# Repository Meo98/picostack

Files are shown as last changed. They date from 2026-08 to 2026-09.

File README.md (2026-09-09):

<p align="center">
  PicoStack
</p>

<h1 align="center">PicoStack</h1>

<p align="center">
  <b>A stackable, contract-driven module system for the Raspberry Pi Pico.</b><br>
  Open hardware, generated by code, verified by tests that are proven to fail.
</p>

<p align="center">
  
  
  
  
</p>

<p align="center">
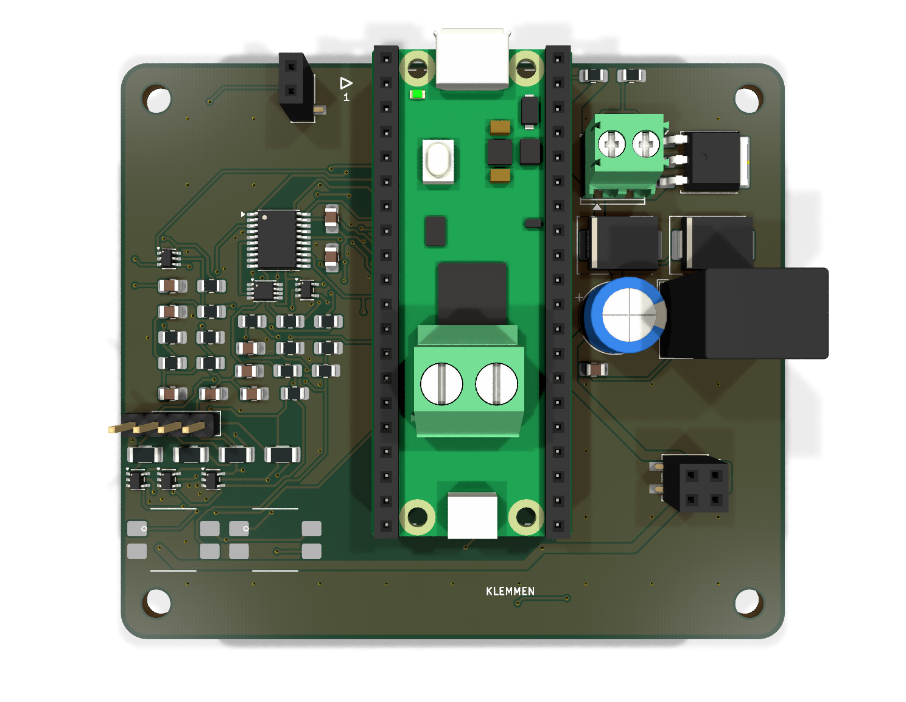
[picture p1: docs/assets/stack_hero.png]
PicoStack motor module with a Raspberry Pi Pico plugged directly into its own stacking headers
  
</p>

---

**One board plus a Pico is a working device.** PicoStack v2 abolishes the
separate base board that v1 needed: every 75 × 65 mm module now carries its
own 6–30 V supply (reverse-polarity protection, TVS, a K7805-1000R3
regulator, Schottky-OR into VSYS) and a pair of Pico-native 1×20 socket rows
(17.78 mm apart, the Pico's own pinout) — the Pico plugs straight into the
top of the stack and all 40 pins run down through it. Stack several fed
boards and they coexist; one is enough to power the whole chain. Every
module also breaks out its 18 spare Pico GPIOs plus 3V3/GND as labelled
solder pads on the board edge.

Power, I²C, emergency-stop and flashing signals run through the stack on
the same contract pinout v1 defined — v2 changed the connector geometry,
not a single pin's role — and any module can be flashed **through the
stack**, selected by a hardware token chain, without touching a cable.

The unusual part: **these boards are not drawn, they are built.** Schematics,
placement, routing, ground stitching and the manufacturing checks all come
from Python that runs headless against KiCad. The stack's mechanical and
electrical rules live in a single machine-readable file — the *contract*
(see the [design spec](docs/superpowers/specs/2026-09-07-picostack-v2-design.md)
for the full v2 rationale) — and every board is measured against it before
it may exist.

## Why you might care

- **You want motorized / sensor / whatever hats for the Pico** that stack
  instead of sprawling across a desk. Design one module and it composes
  with all the others.
- **You want to see a fully generative KiCad workflow** — schematic
  generators, placement specs, headless autorouting (freerouting 2.3),
  copper-pour healing, DRC gates — all reproducible from the command line.
- **You like tests that can actually fail.** Every check in this repository
  ships with a proof that it turns red when the thing it guards is broken.
  ERC and DRC caught *none* of the 14+ real bugs found during development —
  including a fail-unsafe emergency-stop gate (an intact loop blocked the
  motor, a broken wire released it) and a reverse-polarity FET wired so
  that reverse voltage crowbarred instead of being blocked. The custom
  gates caught all of them; that story is documented in the code.

## The stack at a glance

| Piece | What it is | State |
|---|---|---|
| **Contract** (`tools/stack_spec.py`) | Connector positions, pin roles, per-module supply rules, edge-pad positions, landing-point copper rules, mating rules — the single source of truth for anyone building a module | stable, v2 |
| **Motor module** (`hardware/kicad/motor/`) | DRV8876 H-bridge, STM32C011 co-processor, opto-isolated dual-channel e-stop loop, own 6–30 V supply cell | 75 × 65 mm, routed, DRC-clean |
| **Dimmer family** (`hardware/kicad/dimmer{1,3,4}/`) | 1/3/4-channel low-side LED dimmers from one parametric description, own supply cell each | 75 × 65 mm, routed, DRC-clean |
| **Base board** (`hardware/kicad/sockel/`) | v1's Pico socket + 24 V input + 5 V rail board | **v1-only, archived** — see [release v0.1.0](https://github.com/Meo98/picostack/releases/tag/v0.1.0); not part of v2, not updated to the v2 contract |
| **Toolchain** (`tools/`) | Schematic generators, board builder, autorouter driver, ground healer, contract probes | working, evolving |

<p align="center">
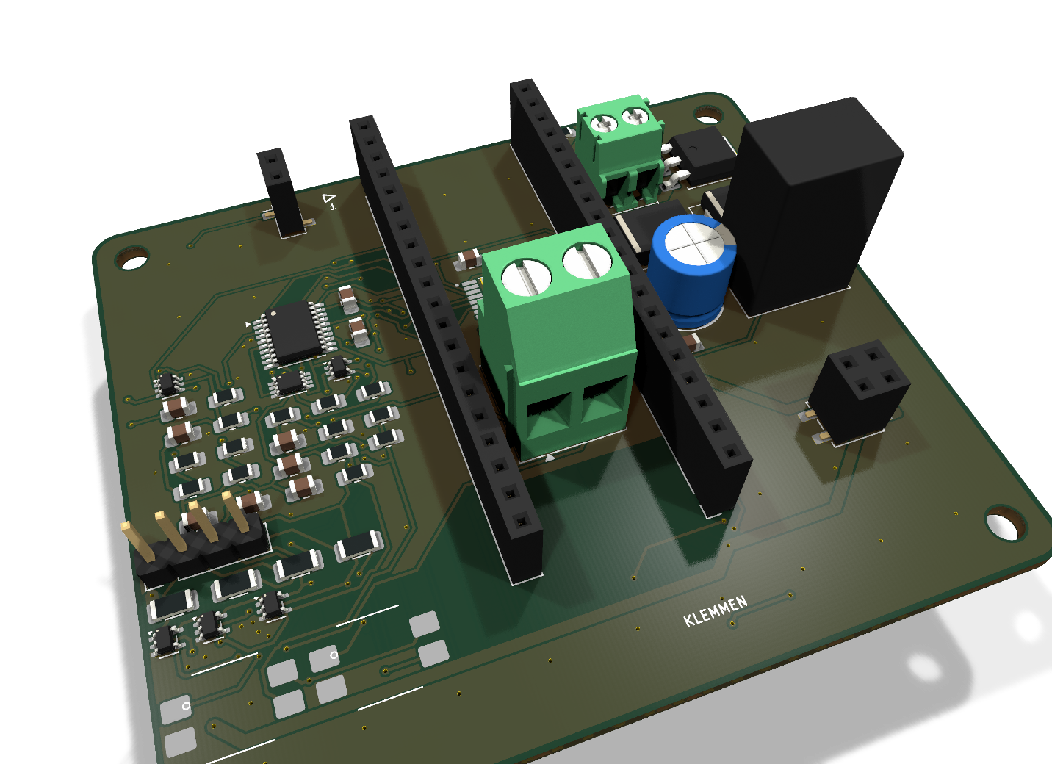
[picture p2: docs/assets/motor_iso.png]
Motor module, isometric
  
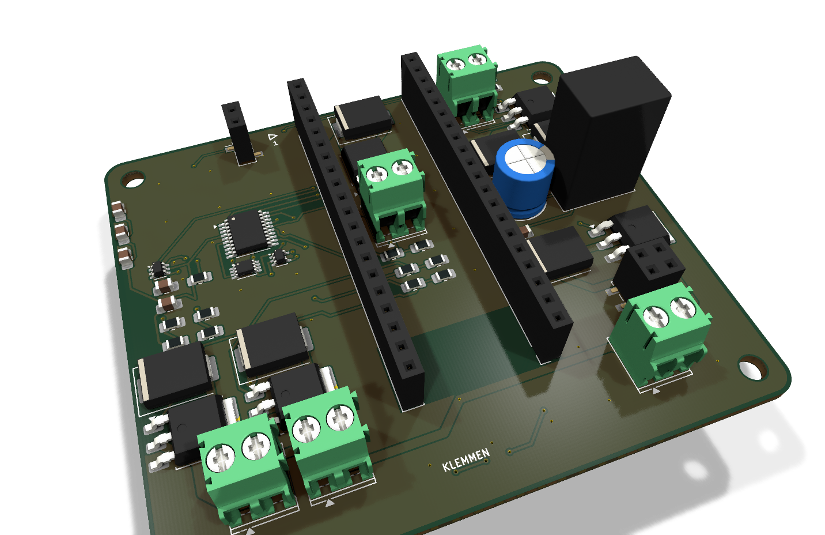
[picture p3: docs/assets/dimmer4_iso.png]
Four-channel LED dimmer module, isometric
  
</p>
<p align="center">
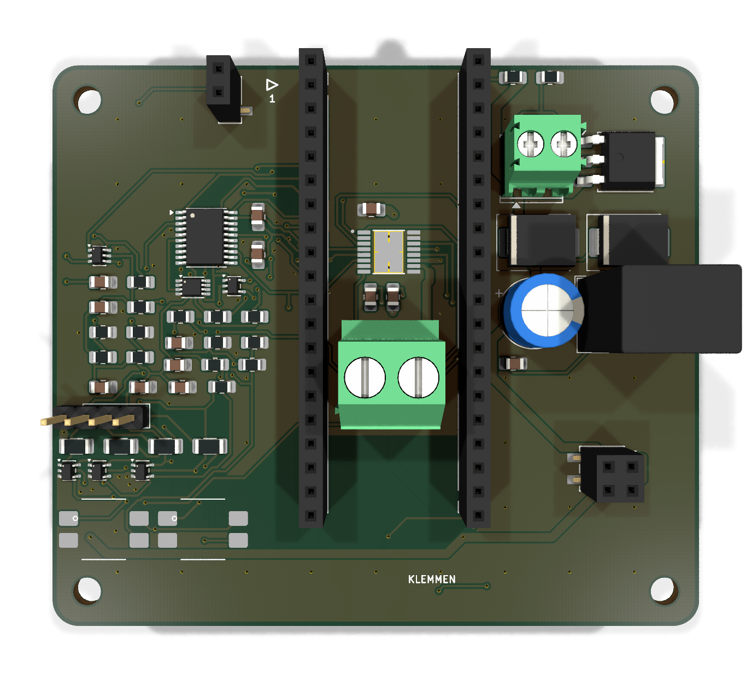
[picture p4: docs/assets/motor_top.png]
Motor module, top view
  
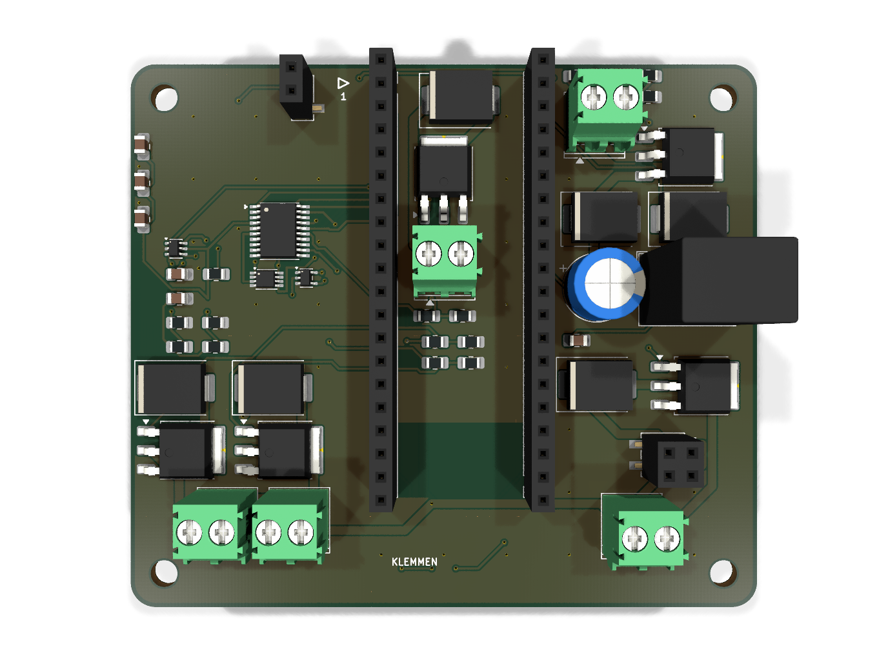
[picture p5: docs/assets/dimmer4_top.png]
Four-channel LED dimmer module, top view
  
</p>

## How a board gets built

```text
tools/sch/<board>.py      →  KiCad schematic (generated, ERC-clean)
tools/pcb/spec_<board>.py →  placement + pre-routes + stitching, no KiCad needed
tools/pcb/build.py        →  fresh .kicad_pcb from netlist + spec
tools/pcb/autoroute.py    →  freerouting 2.3 headless, DSN repaired on the fly
tools/pcb/masseheiler.py  →  finds isolated copper islands, heals them with vias
tools/pcb/steckerprobe.py →  measures the finished board against the contract
```

Every stage is a plain Python file you can read, run and extend. The
[website](https://meo98.github.io/picostack/) walks through the architecture in
detail.

## Building a module of your own

The contract is deliberately small. A module must:

1. use the 75 × 65 mm outline and M3 hole pattern from `stack_spec.py`,
2. place the two Pico-native socket rows and the two connector pairs at the
   contract positions (the helpers compute them for you — never type the
   coordinates),
3. give the board its own 6–30 V supply cell (reverse-polarity protection,
   TVS, Schottky-OR into VSYS) and bring every unused Pico GPIO out as a
   labelled edge pad,
4. keep the landing-point areas free of exposed copper, so a stack that is
   assembled rotated cannot short anything,
5. pass `tests/` and the contract probes against the built board.

Start by copying `tools/pcb/spec_motor.py` and
`tools/sch/motormodul.py`, then read
[CONTRIBUTING.md](CONTRIBUTING.md) — it describes the workflow, the
red-proof testing rule, and how to propose a new module.

**Module ideas we would love to see:** sensor hats, LED drivers, stepper
drivers, CAN/RS-485 bridges, audio, battery management — anything that
speaks the contract. Firmware in any language that runs on a Pico or the
module MCUs (C, MicroPython, Rust, …) is equally welcome.

## Repository layout

```text
hardware/kicad/     KiCad projects (generated .kicad_sch + built .kicad_pcb)
tools/stack_spec.py the contract
tools/sch/          schematic generators
tools/pcb/          board builder, router driver, probes, healer
tests/              plain-python test suites (no pytest needed)
docs/               project website (GitHub Pages)
```

## Building the boards yourself

You need KiCad 10, Python 3, and Java ≥ 25 for the bundled
freerouting 2.3 flow. Then:

```bash
python3 tests/run_all.py                 # every suite, no board tools needed
python3 tools/sch/motormodul.py          # regenerate a schematic
tools/pcb/kipy tools/pcb/build.py spec_motor \
  hardware/kicad/motor/Motormodul.kicad_pcb \
  hardware/kicad/motor/Motormodul.kicad_sch   # rebuild a board
```

(`kipy` is a small launcher that runs a script inside KiCad's Python.
See CONTRIBUTING for the full toolchain walkthrough.)

## Getting boards made

Gerbers, JLC-format BOM/CPL and pick-and-place files for all four v2 boards
live under `hardware/fertigung/{motor,dimmer1,dimmer3,dimmer4}/`, and ship as
ZIPs with every [release](https://github.com/Meo98/picostack/releases).
[`hardware/fertigung/ORDERING.md`](hardware/fertigung/ORDERING.md) walks
through ordering an assembled board at JLCPCB, including the traps that
already cost real money in v1 (a diode package mix-up, a rotation-preview
miss, a type-code encoding gotcha).

## License

- **Hardware** (everything under `hardware/`): [CERN-OHL-S-2.0](hardware/LICENSE) —
  strongly reciprocal: if you ship a derived board, you publish your changes.
- **Code** (tools, generators, firmware): [GPL-3.0-or-later](LICENSE).
- **Documentation**: CC-BY-SA 4.0.

## Project language

The public face of this project is English. The code comments are currently
German — they carry the full engineering rationale of every decision and are
being translated over time. New contributions should be in English.

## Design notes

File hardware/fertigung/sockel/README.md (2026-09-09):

# Sockelplatine — v1-only, archived

This fabrication data is **frozen at the v1 state**, kept for archive
purposes alongside [release v0.1.0](https://github.com/Meo98/picostack/releases/tag/v0.1.0).
It is **not part of the v2 product line** and was not regenerated for the
v2 contract (`VERTRAG_VERSION = 2` in `tools/stack_spec.py`).

v2 removed the need for this board entirely: every v2 module now carries
its own supply cell (reverse-polarity protection, TVS, K7805-1000R3,
Schottky-OR into VSYS) and a pair of Pico-native 1×20 socket rows, so one
module plus a Pico is a working device without a separate base board. See
[`hardware/fertigung/ORDERING.md`](../ORDERING.md) for the current v2
board family (motor, dimmer1, dimmer3, dimmer4) and
[`tools/sch/sockelplatine.py`](../../../tools/sch/sockelplatine.py) for
why this board's generator is not kept in sync with the v2 contract.

Do not order this as a v2 deliverable.

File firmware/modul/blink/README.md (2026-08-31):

# Modul-Testprogramm: blink

Das kleinstmögliche Programm für den Modul-MCU (STM32C011F6P6), dessen
Wirkung man von aussen sieht: ein GPIO-Pin im Sekundentakt umschalten.
Zweck ist einzig, `firmware/sockel/nachweis.py` etwas zum Aufspielen zu
geben, dessen Erfolg oder Misserfolg man ohne Messgerät erkennt — eine
LED oder ein Multimeter am Pin genügt.

Es gibt hier absichtlich **keinen Quelltext**. Register, Header und
Startup-Code hängen am gewählten MCU-Typ (STM32C011F6P6, siehe
`hardware/bauteile.md`) und liegen im Beispielprojekt des Herstellers
(STM32CubeC0 / STM32CubeIDE-Projektvorlage für die STM32C0-Serie,
GPIO-Toggle-Beispiel). Von dort übernehmen, nicht neu schreiben:
STM32-Startup-Dateien und Register-Zugriffe von Grund auf
nachzubauen wäre Aufwand ohne Erkenntnisgewinn für diesen Nachweis.

## Was das Programm tun soll

- Einen freien GPIO-Pin (z. B. ein LED-taugliches Pin, nicht PA11/PA12
  — die trägt der Bootlader-UART — und nicht PA14/BOOT0) im
  Sekundentakt umschalten (toggle, ca. 1 Hz).
- Keine weitere Funktion. Kein UART, kein I²C, keine Interrupts, die
  nicht zum Blinken gehören — je kleiner, desto eindeutiger ist der
  Nachweis, dass genau *dieses* Programm lief.

## Ausgabeformat

Der ROM-Bootlader (AN3155) kennt keine ELF-Dateien und keine
Sektionsheader. Er nimmt rohe Bytes, die er ab `0x08000000`
(Flash-Anfang) in den Speicher schreibt — Adresse und Byte-Reihenfolge
allein entscheiden, keine Metadaten.

Übersetzung (mit dem `arm-none-eabi`-Toolchain aus dem
Hersteller-Beispielprojekt bzw. STM32CubeIDE/CMake):

```bash
# Projekt wie gewohnt uebersetzen -> blink.elf
arm-none-eabi-objcopy -O binary blink.elf blink.bin
ls -l blink.bin      # erwartet: wenige hundert Byte
```

`blink.bin` ist die Datei, die `nachweis.py::aufspielen(pfad)`
erwartet.

## Status

Noch nicht angelegt. Es fehlt der STM32C011 auf dem Tisch (siehe
`docs/nachweis-2026-08.md`) — ohne Hardware zum Gegenprüfen lohnt sich
kein Quelltext, den niemand testen kann. Sobald ein Chip vorliegt: aus
dem Hersteller-Beispiel ableiten, wie oben beschrieben übersetzen, mit
`nachweis.py` aufspielen.

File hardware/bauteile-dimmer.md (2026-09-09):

# Bauteil-Belege Dimmer-Module (1/3/4 Kanäle)

Die Dimmer übernehmen das MCU-Nest wörtlich vom Motormodul; deren
Nummern sind in `bauteile.md` / `bauteile-1b.md` belegt. Hier stehen
nur die Positionen, die es NUR auf den Dimmern gibt bzw. die für die
Bestückungs-Bestellung 2026-09-04 neu gesichtet wurden. Regel wie
immer: eine LCSC-Nummer steht nur hier, wenn die Produktseite selbst
geöffnet und gelesen wurde.

| Position | Bauteil | Gehäuse | LCSC | gesichtet | Beleg |
|---|---|---|---|---|---|
| Freilaufdiode D1–D4 | SS36**C** (MDD/Microdiode) | **SMC (DO-214AB)** | C16237 | ja | LCSC-Produktseite `lcsc.com/product-detail/C16237.html` (Rohdaten: „SMC(DO-214AB)", 60 V, 3 A, „700mV@3A", Lager 102 720). **Falle:** das MDD-Teil mit dem nackten Namen „SS36" (C16015) ist laut seiner Produktseite **SMA (DO-214AC)** — falsches Gehäuse für unsere Pads. Das onsemi-SS36 in SMC (C391251) existiert, hatte am Recherchetag aber nur 847 Stück Lager bei ~0,37 $ |
| Gate-Vorwiderstand RG1–RG4 | 0805W8F1000T5E (UNI-ROYAL), 100 Ω ±1 % | 0805 | C17408 | ja | LCSC-Produktseite `lcsc.com/product-detail/C17408.html` (Rohdaten: „100Ω", „±1%", „125mW", „150V", Lager 8 236 700). Gleiche geprüfte Baureihe wie der 10-kΩ-Beleg C17414 in `bauteile-1b.md` |
| Stütz-Elko C12 (auch C3 Sockel, C12 Motor) | GR227M035F12RR0VL4FP0 (Chengx) | radial D8×L12, RM 3,5 | C45078 | ja | LCSC-Produktseite `lcsc.com/product-detail/…C45078.html` (Rohdaten: „220µF ±20%", „35V", „8mm × 12mm", „Lead Pitch: 3.5mm", „3000hrs@105℃", Lager 123 720) |
| Schraubklemme J5–J8 | KF350-3.5-2P (Cixi Kefa) | THT, RM 3,5, 2P | C474892 | ja | LCSC-Produktseite `lcsc.com/product-detail/C474892.html` (Rohdaten: „3.5mm", „1x2P", „10A", „300V", „18–24 AWG", M2-Schraube, Lager 7 100). **Ehrlich vermerkt:** das ist ein Klon auf dem Raster des Phoenix-PT-1,5/2-3,5-H-Footprints, keine Maßzeichnungs-Gegenprüfung Pad für Pad — Sitz im JLC-Bestückungs-Preview kontrollieren. Der Phoenix-Originaltyp war bei LCSC nicht auffindbar |

## Nachtrag 2026-09-04: JLC-Matching-Runde 2 (Lagerprobleme)

JLCs Abgleich traf drei Widerstandszeilen auf lagerleere Teile (Qty 0)
und hatte vom Kanal-FET NCE6050KA nur noch 3 Stück; die LCSC-Seite
C96013 meldet „Out of Stock". Ersatz, jeweils Produktseite gesichtet:

| Position | Bauteil | LCSC | Beleg |
|---|---|---|---|
| Kanal-FET Q1–Q4 | **NCE6020AK** (NCE), TO-252-2L — **ersetzt den ausverkauften NCE6050KA** | C108639 | LCSC-Produktseite `lcsc.com/product-detail/C108639.html` (Rohdaten: „60V", „20A", „40mΩ@4.5V", „<35mΩ @ VGS = 10V", Gate-Schwelle „2.5V", Lager 6 010). Gleiches V_GS(th)-Limit wie der 6050KA → das 3,3-V-Ansteuerargument (Herleitung in `tools/sch/dimmermodul.py`) bleibt konservativ tragfähig: 40 mΩ × (3 A)² = 0,36 W je Kanal. **Ehrlich vermerkt:** die Espace-Felderfahrung gilt wörtlich nur für den 6050KA — am ersten Board Temperatur nachmessen |
| Kennwiderstand 1,5 kΩ (R100 Dimmer4) | 0805W8F1501T5E (UNI-ROYAL) | C4310 | LCSC-Produktseite `lcsc.com/product-detail/C4310.html` (Rohdaten: „1.5kΩ", „±1%", „125mW", Lager 376 800); JLC-**Basic** laut Basic-Parts-Liste |
| Kennwiderstand 680 Ω (R101, R100 Motor) | 0805W8F6800T5E (UNI-ROYAL) | C17798 | LCSC-Produktseite `lcsc.com/product-detail/…C17798.html` (Rohdaten: „680Ω", „±1%", „125mW", Lager 1 216 700); JLC-Basic |
| 100 kΩ (R102, RP1–RP4) | 0805W8F1003T5E (UNI-ROYAL) | C149504 | JLCPCB-Produktseite `jlcpcb.com/partdetail/160838-0805W8F1003T5E/C149504` (Bestückungsbibliothek); LCSC führt denselben Widerstand doppelt — C17407 („SMT-Geschäft vorbehalten", Lager 185 900 im Retail) meldete im JLC-Dialog trotzdem 35 shortfall, C149504 ist der bestückbare Eintrag. JLCs Auto-Match C5713386 hatte Lager 0 |
| 0-Ω-Brücke (R101 Motor, R100 Dimmer1) | 0805W8F0000T5E (UNI-ROYAL) | C17477 | LCSC-Produktseite `lcsc.com/product-detail/C17477.html` (Rohdaten: „0Ω Jumper", „125mW", Lager 6 207 600) |

## Nachtrag 2026-09-07: JLC-Basic-Festlegung der Kleinteile (Runde 3)

Die „Extended components fee" (3,07 $ je Nicht-Basic-BOM-Zeile) machte
sichtbar, welche Zeilen JLCs Beschreibungs-Matching dem Zufall
überließ. Sichtung per headless Chrome direkt aus dem Seiten-JSON der
JLC-Teileseiten (`componentLibraryType`, `overseasStockCount`,
`noBuyReason`), alle am 2026-09-07:

| Teil | LCSC | Befund |
|---|---|---|
| 100 nF 50 V X7R 0805 (C100 u. a.) | C49678 | YAGEO CC0805KRX7R9BB104, „base", Lager 20,6 Mio |
| 1 µF 50 V X7R 0805 (C101) | C28323 | Samsung CL21B105KBFNNNE, „base", Lager 3,9 Mio |
| 22 µF 25 V X5R 0805 (C2 Sockel) | C45783 | Samsung CL21A226MAQNNNE, „base", Lager 5,2 Mio |
| 4,7 kΩ 0805 (R1/R2 Sockel, R20/R21 Motor) | C17673 | 0805W8F4701T5E, „base", Lager 6,6 Mio |
| 100 kΩ — Bestätigung | C149504 | **„base", Lager 5,2 Mio** — der Karteileichen-Match C17407 ist „expand" UND `noBuyReason: "This product is no longer manufactured."` |
| 100 kΩ — verworfen | C2889441 | VO-Teil aus der Websuche: „expand", Lager 0, ebenfalls abgekündigt |

Ergebnis: Alle Widerstands- und Kondensator-Zeilen aller Boards sind
Basic (keine Gebühr, deterministisches Auto-Match). Die verbleibenden
8 Extended-Zeilen des Dimmer4 sind sämtlich Halbleiter ohne
Basic-Äquivalent — die ~24,56 $ Gebühr sind das Minimum für dieses
Design.

Die übrigen Dimmer-BOM-Nummern (STM32C011F6P6 C5456198, 74LVC-Gatter
C202238/C206109/C7832, IRFR5305 C2624, SMCJ30A C340696, 10 kΩ C17414)
sind in `bauteile.md` / `bauteile-1b.md` bzw. im LED-Dimmer-Altprojekt
belegt und in `tools/jlc.py` als Konstanten übernommen. Der dort
belegte NCE6050KA (C96013) bleibt als Referenz stehen, wird aber seit
dem Nachtrag oben nicht mehr bestückt.

## Nachtrag 2026-09-09: v2-Versorgungszelle (Task 9, Fertigungsdaten)

Mit v2 trägt **jedes** Modul (Motor, Dimmer1/3/4) die Versorgungszelle
aus `tools/sch/versorgung.py` (J90/Q90/R90/R91/D90/C90/U90/C91/D91,
löst den bisherigen board-eigenen Verpolschutz Q1/Q10/D1/D10/C12 ab —
per `pos.csv` nachgemessen, keiner dieser alten Bezeichner existiert
mehr). Für `tools/jlc.py` neu **zusammengesetzt**, aber **keine neue
LCSC-Sichtung** nötig — alle vier Nummern sind bereits an anderer
Stelle in diesem Projekt mit Produktseite belegt:

| Bauteil (Zelle) | LCSC | bereits belegt in |
|---|---|---|
| J90 KF350-3.5-2P | C474892 | `tools/jlc.py` (Bestellrunde 2026-09-04) |
| U90 K7805-1000R3 | C909765 | `tools/sch/sockelplatine.py` / `tools/jlc.py` (Sockel-U2) |
| D91 SS36C | C16237 | `tools/jlc.py` (Dimmer-Kanaldioden D1–D4) |
| C90 220µF Elko | C45078 | `tools/jlc.py` (Sockel-C3 / bisheriges C12) |

Q90 (IRFR5305, C2624), D90 (SMCJ30A, C340696), R90/R91 (10 kΩ,
C17414), C91 (22µF, C45783) sind ebenfalls reine Wiederverwendungen
bereits belegter Nummern (s. Konstanten in `tools/jlc.py`).

**Eine echte neue Sichtung diese Runde:** U6/U7 (Motormodul) wechseln
von SN74LVC1G06 (C7828, invertierend — für den Ruhestrom-Notaus falsch
gepolt, s. `tools/sch/motormodul.py::INVERTER_WERT`) auf **SN74LVC1G07
(C7830)**, nichtinvertierender Puffer mit Open-Drain-Ausgang,
pinidentisch (SOT-353/SC-70-5, gleicher Footprint wie U3/U103). Die
Quelle in `motormodul.py` leitet C7830 aus der LCSC-Nummernfolge der
Nachbartypen her (C7828 = 1G06, C7832 = 1G08) statt aus einer selbst
gesichteten Produktseite — das wäre nach der bindenden Regel dieses
Projekts eigentlich ein Lückenfall (Feld leer lassen). Für diese
Aufgabe **selbst nachgesehen** (WebFetch auf
`lcsc.com/product-detail/C7830.html`, 2026-09-09): Seite bestätigt
MPN **SN74LVC1G07DCKR**, Gehäuse **SC-70-5**, Beschreibung „Single
Buffer/Driver With Open-Drain Output", 1,65–5,5 V, 32 mA Senkstrom —
die Nummer ist korrekt, die Herleitung war nur unvollständig belegt.
`tools/jlc.py` führt C7830 jetzt als `LCSC_1G07`-Konstante.

Unbestückt und ohne LCSC-Bedarf: J95/J96 (Randpad-Reihen, SMD-Lötpads
auf B.Cu, `stack_spec.RANDPADS`) und J105 (zweiter Stapelstecker,
Pico-Pins 21–40 — vorher Teil eines einzelnen 2×20-Steckers J100,
jetzt zwei 1×20-Buchsen) — beide von Hand im gesteckten Verbund
bestückt, s. `hardware/fertigung/*/UNBESTUECKT.txt`.

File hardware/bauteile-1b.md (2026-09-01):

# Bauteilwahl Etappe 1b: Stapelstecker, Auswahlketten-Logik, Leistung, Klemmen

**Stand:** 2026-08-31. Bestand und Preise bei LCSC/JLCPCB ändern sich laufend;
die hier genannten Zahlen sind Stichproben vom Recherchezeitpunkt, keine
Garantie. Vorlage und Sorgfaltsmassstab: `hardware/bauteile.md` (Etappe 1a).

## Bauteiltabelle

**Nachtrag 2026-08-31 (Prüfung durch den Auftraggeber):** Der 2×20-Signalstecker
ist nach der Entscheidung des Auftraggebers **kein** Buchse/Stift-Paar mehr,
sondern ein echter Stapelstecker (Buchse mit durchgehendem Stift). Die
ursprünglichen zwei Zeilen dafür (Buchse C2977589 / Stift C50980) stehen unten
als **verworfen** markiert, ersetzt durch die neue Stapelstecker-Zeile.
Begründung und Rechnung: Beleg 1 (überarbeitet) und der neue Abschnitt
„Beleg 6 — Entscheidung Stapelstecker". Die beiden verworfenen Bauteile
bleiben sichtbar stehen, weil ihre Zahlen (6,0/3,0 mm bzw. 8,5 mm) jetzt die
Grundlage des neuen, eigenständigen Kettensteckers sind.

| Zweck | Typ | Bauform | LCSC | geprüft | Quelle |
|---|---|---|---|---|---|
| Signalstecker, Buchse (oben, 2×20) — **verworfen, s. u.** | BOOMELE/ZHOURI-Familie, 2,54 mm Buchsenleiste | THT, Gehäusehöhe 8,5 mm über Platine | C2977589 | verworfen (Bauform an sich geprüft) | LCSC-Produktseite `lcsc.com/product-detail/C2977589.html`; Datenblatt (ZHOURI, Rev. ZRLCGY2025-06-17-CJ A/1), Masszeichnung „8,5±0,2"; JLCPCB-Produktseite `jlcpcb.com/partdetail/2.54-2*20/C2977589` (SMT Assembly, Economic/Standard PCBA) |
| Signalstecker, Stift (unten, 2×20) — **verworfen, s. u.** | BOOMELE 2,54 mm Stiftleiste, gerade | THT, Stift 6,0 mm oberhalb / 3,0 mm unterhalb des Isolierkörpers (Gesamtlänge 9,0 mm) | C50980 | verworfen (Bauform an sich geprüft) | LCSC-Produktseite `lcsc.com/product-detail/Male-Header_Made-in-China-2-54mm-2-20P-Header_C50980.html`; Datenblatt (东莞康孚电子), Masszeichnung „3.0" / „6.0"; JLCPCB-Produktseite `jlcpcb.com/partdetail/BOOMELE-2_54mm2_20PHeader/C50980` (SMT Assembly, Economic/Standard PCBA) |
| **Stapelstecker, Signal (2×20) — ersetzt die beiden Zeilen oben** | ZHOURI/BOOMELE „PC104-2*NA+1": Buchse mit durchgehendem Stift | THT, Gehäuse 8,5 mm über Platine, Stift 12,46 mm unterhalb des Gehäuses (Gesamtlänge 23,50 mm), 3 A/Kontakt | C35165 | ja | LCSC-Produktseite `lcsc.com/product-detail/Pin-Header-Female-Header_Boom-Precision-Elec-2-54mm-2-20P_C35165.html`; Datenblatt (ZHOURI/上海康司玛, Zeichnung „PC104-2*NA+1"), Masszeichnung „8,5±0,2" / „12,46±0,2" / „23,50"; JLCPCB-Produktseite `jlcpcb.com/partdetail/BOOMELE-2_54_2_20PFemaleLongPC104/C35165` (SMT Assembly, Economic/Standard PCBA) |
| ~~Kettenstecker, Buchse (oben, 1×2, trägt SEL+GND)~~ — **verworfen 2026-08-31 (Aufgabe 5e): zwei bedrahtete Hälften können sich am selben Ort keine Bohrungen teilen, s. Beleg 13** | XFCN PM254V-11-02-H85 | THT, 8,5 mm über Platine, 3 A/Kontakt, 250 V | C541849 | verworfen (Bauform an sich geprüft) | LCSC-Produktseite `lcsc.com/product-detail/C541849.html` (Rohdaten: „3A", „250V", „8.5mm"); JLCPCB-Produktseite `jlcpcb.com/partdetail/XFCN-PM254V_1102H85/C541849` (SMT Assembly, Economic/Standard PCBA) — laut Herstellerbezeichnung passend zur XFCN-PZ254-Reihe |
| ~~Kettenstecker, Stift (unten, 1×2)~~ — **verworfen 2026-08-31 (Aufgabe 5e): zwei bedrahtete Hälften können sich am selben Ort keine Bohrungen teilen, s. Beleg 13** | XFCN PZ254V-11-02P | THT, Stift 6,0 mm oberhalb / 3,0 mm unterhalb des Isolierkörpers, 3 A/Kontakt, 250 V | C492401 | verworfen (Bauform an sich geprüft) | LCSC-Produktseite `lcsc.com/product-detail/Pin-Header-Female-Header_XFCN-PZ254V-11-02P_C492401.html` (Rohdaten: „6mm"/„3mm" Steck-/Lötpin); JLCPCB-Produktseite `jlcpcb.com/partdetail/XFCN-PZ254V_1102P/C492401` (SMT Assembly, Economic/Standard PCBA) |
| ~~Leistungsstecker, Buchse (oben, 2×2)~~ — **verworfen 2026-08-31 (Aufgabe 5e): zwei bedrahtete Hälften können sich am selben Ort keine Bohrungen teilen, s. Beleg 13** | gleiche ZHOURI-Familie, 2,54 mm | THT, 8,5 mm über Platine, 2,5 A/Kontakt | C2977590 | verworfen (Bauform an sich geprüft) | LCSC-Produktseite `lcsc.com/product-detail/Female-Headers_ZHOURI-2-54-2-2_C2977590.html` (Rohdaten: „2.5A", „8.5mm insulation height") |
| ~~Leistungsstecker, Stift (unten, 2×2)~~ — **verworfen 2026-08-31 (Aufgabe 5e): zwei bedrahtete Hälften können sich am selben Ort keine Bohrungen teilen, s. Beleg 13** | gleiche BOOMELE-Familie, 2,54 mm | THT, 6,0/3,0 mm, 3 A/Kontakt | C66690 | verworfen (Bauform an sich geprüft) | LCSC-Produktseite `lcsc.com/product-detail/Male-Header_Double-Rows2-2p-pitch2-54mm_C66690.html` (Rohdaten: „3A", „6mm"/„3mm") |
| **Kettenstecker, Buchse (oben, 1×2) — ersetzt die verworfene Zeile** | Buchsenleiste 1×2, 2,54 mm, SMD senkrecht, Isolationshöhe 8,5 mm, ≥ 1 A | **SMD**, 8,5 mm über Platine | *(offen — keine gesichtete Nummer)* | Bauform ja, Polzahl nein | Bauform belegt an C261072 (BOOMELE 2.54-2\*5P, „Surface mount, vertical", „Insulation Height: 8.5mm", „Current Rating: 2.5A") und C52611 (BOOMELE 2.54-2\*25P, „SMD header 2\*25P 2.54mm H=8.5mm Gold-plated"); in 1×2 auf **keiner** Produktseite gesehen — deshalb kein LCSC-Feld, s. Beleg 13.4 |
| **Kettenstecker, Stift (unten, 1×2) — ersetzt die verworfene Zeile** | Stiftleiste 1×2, 2,54 mm, SMD senkrecht, Isolierkörper ≤ 2,5 mm, Steckstift 6,0 mm | **SMD**, 8,5 mm unter der Platine (2,5 + 6,0) | *(offen — keine gesichtete Nummer)* | Bauform ja, Polzahl nein | Bauform belegt an C919361 (2×2), C192300 (2×4), C124390/C124391 (Ckmtw, 2×3/2×5); in 1×2 nicht gesehen, s. Beleg 13.4 |
| **Leistungsstecker, Buchse (oben, 2×2) — ersetzt die verworfene Zeile** | Buchsenleiste 2×2, 2,54 mm, SMD senkrecht, Isolationshöhe 8,5 mm, ≥ 2,5 A/Kontakt | **SMD**, 8,5 mm über Platine | *(offen — keine gesichtete Nummer)* | Bauform ja, Polzahl nein | wie die Zeile darüber: C261072 / C52611; in 2×2 nicht gesehen, s. Beleg 13.4 |
| **Leistungsstecker, Stift (unten, 2×2) — ersetzt die verworfene Zeile** | BOOMELE „2.54-2\*2P" | **SMD senkrecht**, Isolierkörper 2,5 mm, Steckstift 6,0 mm, 3 A/Kontakt | **C919361** | ja | LCSC-Produktseite `lcsc.com/product-detail/C919361.html` (Rohdaten: „Surface Mount (SMD), Vertical", „Insulation Height: 2.5mm", „Mating Pin Length: 6mm", „Current Rating: 3A", 28 460 auf Lager) |
| D-Flipflop, asynchroner Löscheingang | SN74LVC1G175DCKR (TI) | SOT-363-6 (SC-70-6), 6 Pins | C202238 | ja | LCSC-Produktseite `lcsc.com/product-detail/74-Series_TI_SN74LVC1G175DCKR_SN74LVC1G175DCKR_C202238.html`; JLCPCB-Produktseite `jlcpcb.com/partdetail/TexasInstruments-SN74LVC1G175DCKR/C202238` (SMT Assembly, Economic/Standard PCBA, MSL 1); Primärquelle TI-Datenblatt `SN74LVC1G175`, Dok. SCES560G (März 2004, revidiert Juni 2015), Abschnitt 3 „Description" und Abschnitt 5 „Pin Configuration and Functions" (Gehäuse „DCK Package, 6-Pin SC70", Pin 6 = `CLR`) |
| Gatter Dual-NAND (NOT via NAND(Q,Q), NRST) — **ersetzt die Zeilen NOT+NAND unten, s. Nachtrag 2026-08-31 (2. Runde)** | SN74LVC2G00DCUR (TI) | **VSSOP-8 (0,5 mm Pitch), 8 Pins — NICHT SOT-363**, s. Anmerkung unten | C206109 | ja | LCSC-Produktseite `lcsc.com/product-detail/C206109.html` (Rohdaten: Gehäuse „VSSOP-8-0.5mm"); TI-Datenblatt `SN74LVC2G00`, „Dual 2-Input Positive-NAND Gate" |
| ~~Gatter NOT (Invertierung Q)~~ — **verworfen, s. Nachtrag 2026-08-31 (2. Runde): ersetzt durch eine Einheit des Dual-NAND (Eingänge kurzgeschlossen)** | SN74LVC1G04DCKR (TI) | SOT-353 (SC-70-5), 5 Pins | C8207 | ja (Bauform an sich geprüft, aber verworfen) | LCSC-Produktseite `lcsc.com/product-detail/C8207.html`; JLCPCB-Produktseite `jlcpcb.com/partdetail/TexasInstruments-SN74LVC1G04DCKR/C8207` (SMT Assembly, Economic/Standard PCBA, MSL 1) |
| ~~Gatter NAND (NRST)~~ — **verworfen, s. Nachtrag 2026-08-31 (2. Runde): ersetzt durch die zweite Einheit desselben Dual-NAND** | SN74LVC1G00DCKR (TI) | SOT-353 (SC-70-5), 5 Pins | C8185 | ja (Bauform an sich geprüft, aber verworfen) | LCSC-Produktseite `lcsc.com/product-detail/C8185.html` (Rohdaten: „SOT-353“, „ultra-small DPW package… 0.8 mm × 0.8 mm“); TI-Datenblatt `SN74LVC1G00`, „Single 2-Input Positive-NAND Gate“ |
| Gatter AND (BOOT0) | SN74LVC1G08DCKR (TI) | SOT-353 (SC-70-5), 5 Pins | C7832 | ja | LCSC-Produktseite `lcsc.com/product-detail/C7832.html` (Rohdaten: „SC-70-5“, „ultra-small DPW package… 0.8 mm × 0.8 mm“); TI-Datenblatt `SN74LVC1G08`, „Single 2-Input Positive-AND Gate“ |
| ~~Gatter Dual-AND (RESET, BOOT0) — **verworfen, s. Nachtrag 2026-08-31**~~ | 74LVC2G08GT,115 (Nexperia) | XSON-8 (1×2 mm), 8 Pins | C548580 | ja (Bauform an sich geprüft, aber verworfen) | JLCPCB-Produktseite `jlcpcb.com/partdetail/Nexperia-74LVC2G08GT115/C548580` (SMT Assembly, Economic/Standard PCBA, MSL 1) |
| 5-V-Regler | K7805-2000R3 | SIP-3 | C2931187 | ja | bereits geprüft in Etappe 1a / LED-Dimmer-Projekt, siehe `hardware/bauteile.md` — hier unverändert übernommen, nicht neu recherchiert |
| Klemme 2-polig | DB128L-5.08-2P-GN-S | THT, 5,08 mm | C395868 | ja | bereits geprüft in Etappe 1a / LED-Dimmer-Projekt — unverändert übernommen |
| Klemme 3-polig — **seit Aufgabe 5f von keinem Modul mehr gebraucht** (sie trug die Sensorklemme J2 des Motormoduls; der Sensoreingang ist entfallen, s. Beleg 12, Nachtrag). Zeile bleibt stehen, weil die Nummer geprüft ist und ein künftiges Modul sie brauchen kann | DB128L-5.08-3P-GN-S | THT, 5,08 mm | C395869 | ja | LCSC-Produktseite `lcsc.com/product-detail/C395869.html` (16 A, 300 V, M2-Schraube, 12–22 AWG); JLCPCB-Produktseite bestätigt (DORABO-Familie, SMT/Wave-Assembly, Economic/Standard PCBA) — selbe Farbe/Baureihe wie die bereits geprüfte 2-polige Klemme |
| ~~Schaltdiode (Notaus-Verriegelung, Aufgabe 5)~~ — **verworfen, s. Nachtrag 2026-08-31 (Aufgabe-5-Fix-1): eine Si-Diode ist für den gezogenen Ruhepegel der NOTAUS-Sammelleitung zu hochohmig, s. Beleg 10** | 1N4148W (ST/Semtech) | SOD-123 | C81598 | ja (Bauform an sich geprüft, aber verworfen) | LCSC-Produktseite `lcsc.com/product-detail/Switching-Diode_ST-Semtech-1N4148W_C81598.html` (Rohdaten: Gehäuse „SOD-123", `Vf "1V@50mA"`); JLCPCB-Produktseite `jlcpcb.com/partdetail/ST-1N4148W/C81598` bestätigt SMT-Assembly („Economic and Standard" PCBA, MSL 3) |
| ~~Koppeldiode NOTAUS-Sammelleitung (D3/D4, Aufgabe-5-Fix-1)~~ — **verworfen, s. Nachtrag 2026-08-31 (Aufgabe 5d): der Notaus-Eingang arbeitet jetzt im Ruhestrom, der Bus wird von einem Open-Drain-Ausgang gezogen; eine Diode IN REIHE dazu liesse null Reserve gegen V_IL, s. Beleg 11. Die Grenzwerte bleiben stehen, weil die Gegenproben im Test mit ihnen rechnen** | BAT54W (YANGJIE), Schottky | SOD-123 (gleicher Footprint wie bisher) | C699107 | ja | LCSC-Produktseite `lcsc.com/product-detail/Schottky-Barrier-Diodes-SBD_Yangzhou-Yangjie-Elec-Tech-BAT54W_C699107.html` (Rohdaten: Hersteller „YANGJIE", Gehäuse „SOD-123", 30 V, 200 mA, Leckstrom „2µA@25V"; Bestand am Recherchetag 440 Stück — **wenig, vor der Bestellung prüfen**). Grenzwerte für die Pegelrechnung aus dem Vishay-Typdatenblatt `BAT54W`, Dok. **86408, Rev. 1.0 vom 20-Nov-2023**, Tabelle „ELECTRICAL CHARACTERISTICS" (T_amb = 25 °C): V_F ≤ 240 mV @ 0,1 mA, ≤ 320 mV @ 1 mA, ≤ 400 mV @ 10 mA, I_R ≤ 2 µA @ 25 V. **Ehrlich vermerkt:** das Yangjie-eigene PDF war über LCSC nicht als PDF abrufbar (die Datenblatt-URL liefert eine HTML-Seite); die zitierten Grenzwerte sind die des JEDEC-Typs BAT54W bei Vishay, nicht die von Yangjie selbst. Vor der Fertigung mit dem Yangjie-Datenblatt gegenprüfen |
| Verriegelungsgatter NOTAUS→nSLEEP (U3, Aufgabe-5-Fix-1) | SN74LVC1G08DCKR (TI) — **zweite Verwendung desselben Bauteils wie U103**, keine neue Nummer | SOT-353 (SC-70-5), 5 Pins | C7832 | ja | dieselbe geprüfte Produktseite wie die BOOT0-Zeile oben; Grenzwerte für die Pegelrechnung aus dem TI-Datenblatt `SN74LVC1G08`, Dok. **SCES217AA** (April 1999, revidiert August 2026), Abschnitt 5.3 „Recommended Operating Conditions" (V_IH ≥ 2,0 V, V_IL ≤ 0,8 V bei V_CC = 3–3,6 V) und Abschnitt 5.5 „Electrical Characteristics" (V_OH ≥ V_CC − 0,15 V bei −100 µA, V_OL ≤ 0,1 V bei 100 µA, I_I ≤ ±5 µA) |
| **Kanaltreiber Notaus→NOTAUS (U6/U7, Aufgabe 5d)** — Inverter mit **Open-Drain**-Ausgang; ersetzt die verworfenen Koppeldioden D3/D4 | SN74LVC1G06DCKR (TI) | SOT-353 (SC-70-5), 5 Pins — **gleicher Footprint wie U3/U103** | C7828 | ja | LCSC-Produktseite `lcsc.com/product-detail/Inverters_Texas-Instruments-SN74LVC1G06DCKR_C7828.html` (Rohdaten: Gehäuse „SC-70-5“, Versorgung „1.65V~5.5V“, Ausgangstyp „Open-drain“, Eingang „Schmitt trigger“, „Output sink current 32mA max“, Ruhestrom „10µA max“, Bestand 3 600). Primärquelle TI-Datenblatt `SN74LVC1G06`, Dok. **SCES295AB** (JUNE 2000 – REVISED OCTOBER 2025), selbst geöffnet und gelesen: Abschnitt 5.3 „Recommended Operating Conditions“ (V_IH ≥ 2,0 V, V_IL ≤ 0,8 V bei V_CC = 3–3,6 V; I_OL ≤ 24 mA bei V_CC = 3 V), Abschnitt 5.5 „Electrical Characteristics“ (V_OL ≤ 0,1 V bei 100 µA, **≤ 0,4 V bei 16 mA / V_CC = 3 V**, ≤ 0,55 V bei 24 mA; I_I ≤ ±1 µA; I_off ≤ ±10 µA; I_CC ≤ 10 µA), Abschnitt 1 „Features“ („Schmitt trigger action on all ports“, „Ioff supports partial-power-down mode and back-drive protection“), Abschnitt 3 „Description“ (Ausgänge dürfen für „active-low wired-OR“ zusammengeschaltet werden) |
| **Optokoppler Sensoreingang und Notaus-Schleifen (U2 sowie U4/U5, Aufgabe 5d)** — U2 war seit dem Altprojekt bestückt, stand aber **nie in dieser Tabelle**; hier nachgetragen | PC817X1CSP9F (SHARP), Rangmarke **A** | SMD-4P (SMT-Gullwing) | C97308 | ja | LCSC-Produktseite `lcsc.com/product-detail/Optocouplers_Sharp-Microelectronics-PC817X1CSP9F_C97308.html` (Rohdaten: Hersteller „SHARP“, Gehäuse „SMD-4P“, „Current Transfer Ratio 600%;50%“, „Forward Current (If) 50mA“, „Forward Voltage (Vf) 1.2V“, „VCE Saturation 200mV@20mA,1mA“, „Isolation Voltage 5kV“, Bestand 10 640). Primärquelle SHARP-Datenblatt „PC817X Series“, **Sheet No. D2-A03101EN, Date Sep. 30. 2003**, selbst gelesen: „Absolute Maximum Ratings“ (I_F 50 mA, I_C 50 mA, P_tot 200 mW, T_opr −30…+100 °C), „Electro-optical Characteristics“ (V_F TYP 1,2 V / MAX 1,4 V bei I_F = 20 mA; I_CEO MAX 100 nA; **I_C MIN 2,5 mA bei I_F = 5 mA, V_CE = 5 V** = CTR ≥ 50 %; V_CE(sat) MAX 0,2 V bei I_F = 20 mA, I_C = 1 mA; t_r/t_f TYP 4/3 µs, MAX 18 µs), „Model Line-up“ (Rangmarke A = I_C 4,0–8,0 mA bei I_F = 5 mA). **Footprint — ERLEDIGT (Aufgabe 5f):** die Gullwing-Bauform misst laut „Outline Dimensions“, Zeichnung 2 „SMT Gullwing Lead-Form“, 6,5 × 4,58 mm Körper bei **10,0 +0/−0,5 mm** Anschlussspanne und 7,62 mm Reihenabstand; der Platzhalter `Package_SO:SOP-4_3.8x4.1mm_P2.54mm` (Pads bis 3,48 mm vom Mittelpunkt) lag **vollständig neben** den Anschlüssen. Ersetzt durch einen projekteigenen Footprint, Pad für Pad aus „Design Considerations“ → „Recommended Foot Print (reference)“, Zeile „SMT Gullwing Lead-form“ (Reihenabstand **8,2 mm**, Pad **2,2 × 1,7 mm**, Raster 2,54 mm): `hardware/kicad/components/footprints/Optocoupler_PC817.pretty/PC817_SMT_Gullwing.kicad_mod`. U2 gibt es nicht mehr (Sensoreingang entfallen), U4/U5 tragen ihn. Details Beleg 12, Nachtrag |
| **Schleifenwiderstände Notaus (R16–R19, Aufgabe 5d)** — 1206 statt 0805, weil sie einen äusseren Dauerkurzschluss aushalten müssen | 1206W4F3301T5E (UNI-ROYAL), 3,3 kΩ ±1 % | 1206, Dickschicht | C26032 | ja | LCSC-Produktseite `lcsc.com/product-detail/Chip-Resistor-Surface-Mount_Uniroyal-Elec-1206W4F3301T5E_C26032.html` (Rohdaten: Gehäuse „1206“, „3.3kΩ“, Toleranz „±1%“, Leistung „**250mW**“, max. Arbeitsspannung „200V“, TK „±100ppm/℃“, Bestand 164 200). Die 250 mW sind der Beleg für die Kurzschlussrechnung in Beleg 11 |
| **Widerstände 0805, ganze Baureihe (Aufgabe 5f)** — die Belastbarkeit war bis dahin nirgends belegt, obwohl 20 Widerstände darauf beruhen | 0805W8F…T5E (UNI-ROYAL), Dickschicht, ±1 %; als Beleg geöffnet: 0805W8F1002T5E (10 kΩ) | 0805 | C17414 | ja | LCSC-Produktseite `lcsc.com/product-detail/Chip-Resistor-Surface-Mount_Uniroyal-Elec-0805W8F1002T5E_C17414.html` (Rohdaten: Gehäuse „0805“, „10kΩ“, Toleranz „±1%“, Leistung „**125mW**“, max. Arbeitsspannung „**150V**“, TK „±100ppm/℃“, Bestand 21 700 400). Diese 125 mW sind die Rechengrundlage der neuen Leistungsprüfung (`motormodul.P_NENN_JE_BAUFORM`) — s. Beleg 12, Nachtrag |
| **Verpolungsschutz Q1 (Aufgabe 5f)** — **ersetzt den geerbten „IRF4905“**, den es in TO-252 gar nicht gibt (s. Beleg 12, Nachtrag) | IRFR5305PbF (Infineon/International Rectifier), P-Kanal, −55 V, −31 A, 65 mΩ | **D-Pak (TO-252AA)** | C2624 | ja | LCSC-Produktseite `lcsc.com/product-detail/mosfets_infineon-technologies-irfr5305trpbf_C2624.html` (Rohdaten: „P-Channel MOSFET“, Gehäuse „**DPAK (TO-252AA)**“, „55V“, „31A“, „65mΩ @ 10V“, „110W“, Gate-Schwelle „4V“, Bestand 17 854, 0,23 $ ab 100 St.). Primärquelle Infineon/IR-Datenblatt **PD-95025A (12/13/04)**, selbst gelesen: Titelzeile „IRFR5305PbF … Surface Mount (IRFR5305) … V_DSS = −55V, R_DS(on) = 0.065 Ω, I_D = −31A“, „Absolute Maximum Ratings“ (V_GS ±20 V, P_D 110 W), „Electrical Characteristics“ (V_GS(th) −2,0…−4,0 V; I_GSS ±100 nA bei ±20 V), Abschnitt „D-Pak (TO-252AA) Package Outline“. **Gegenprobe zum alten Typ:** IRF4905 gibt es bei LCSC nur als TO-220 (C2564 Infineon, C18207551 UMW) und als TO-263/D2Pak (C5337969) |

Von den acht in der ersten Fassung neu recherchierten Nummern (nicht sieben, wie dort irrtümlich stand — Zählfehler korrigiert) sowie den drei in dieser Nachbesserung hinzugekommenen (Stapelstecker C35165, Kettenstecker C541849/C492401) wurde jede auf einer echten LCSC- oder
JLCPCB-Produktseite gesichtet (Datenblatt-Zeichnung oder strukturierte
Attribute), nicht aus dem Gedächtnis übernommen. Wo eine WebSearch-Kurzfassung
unterwegs Angaben behauptete, die dem tatsächlich gelesenen Datenblatt
widersprachen (siehe Beleg 2), wurde die Kurzfassung verworfen und nur das
gelesene PDF verwendet.

## Beleg 1 — Steckerhöhe gegen den 15-mm-Plattenabstand

**Aufgabe:** `STAPEL_ABSTAND = 15.0` (`tools/stack_spec.py`) ist der Abstand
**Platinenoberkante zu Platinenoberkante** zweier benachbarter Platinen (so
die Aufgabenstellung). Jedes Modul hat oben eine Buchsenleiste, unten eine
Stiftleiste, in der Platine verbunden. Zu prüfen: passt eine gängige
Bauform von Stift- und Buchsenleiste zusammen mit 1,6 mm Platinendicke auf
genau diesen Abstand.

**Geometrie.** Modul A (oben) trägt die Stiftleiste an seiner Unterseite,
Modul B (darunter) die Buchsenleiste an seiner Oberseite. Der freie
Luftspalt zwischen der Unterseite von A und der Oberseite von B ist

    G = STAPEL_ABSTAND − Platinendicke = 15,0 mm − 1,6 mm = 13,4 mm

Dieser Spalt wird nicht von den Steckern getragen — das leisten die
Abstandsbolzen (Design-Doc, Abschnitt „Mechanik": „Abstandsbolzen tragen
die Mechanik; die Stecker haben nur elektrische Aufgaben"). Für die
Steckverbindung heisst das: Stiftlänge unterhalb der Platine (M) plus
Buchsenhöhe oberhalb der Platine (F) müssen den Spalt **überbrücken**
(M + F ≥ G), und der Stift darf nicht so lang sein, dass sein Schulter
(Isolierkörper) am oberen Rand der Buchse anschlägt, bevor die Bolzen die
Platinen auf Abstand gebracht haben (M ≤ G).

**Belegte Werte (aus Beleg-Datenblättern oben):**

- Stiftleiste C50980: Stift ragt **6,0 mm** unterhalb des Isolierkörpers
  heraus (das ist die Seite, die als Steckseite nach unten zeigt, wenn das
  Bauteil mit dem Lötschwanz — 3,0 mm — durch die Platine nach oben lötet).
  → **M = 6,0 mm**
- Buchsenleiste C2977589: Gehäusehöhe **8,5 mm** über der Platine, auf der
  sie sitzt. → **F = 8,5 mm**

**Rechnung:**

    M + F = 6,0 mm + 8,5 mm = 14,5 mm
    G     = 13,4 mm
    Einstecktiefe = (M + F) − G = 14,5 mm − 13,4 mm = 1,1 mm

    M = 6,0 mm ≤ G = 13,4 mm → kein Anschlagen der Stiftschulter, grosser
    Puffer (7,4 mm) in diese Richtung.

**Befund:** Die Kombination **mattet gerade so**, mit rechnerisch **nur
1,1 mm Einstecktiefe**. Das ist kein „passt nicht", aber ein dünner Rand:

- Beide Bauteile tragen ±0,2 mm Toleranz auf den relevanten Massen
  (zusammen bis zu ±0,4 mm), dazu kommen die Toleranz der Platinendicke
  (JLCPCB-Standard: 1,6 mm ± 10 %, also ±0,16 mm) und die Fertigungslänge
  der Abstandsbolzen. Im ungünstigsten Fall reduziert sich die
  Einstecktiefe auf nahe null oder wird rechnerisch negativ — dann stecken
  die Kontakte nicht mehr sicher ineinander.
- Für 2,54-mm-Stiftkontakte wird in der Verbindungstechnik üblicherweise
  eine Mindest-Einstecktiefe von einigen mm für zuverlässigen Kontaktdruck
  und Selbstreinigung durch Wischen empfohlen; das ist allgemeines
  Auslegungswissen aus der Steckverbinder-Praxis, keine Angabe aus den
  hier gelesenen Datenblättern — beide Datenblätter machen dazu keine
  Aussage.
- Eine gründliche Suche nach einer **passenderen Standard-Buchse** (grösser
  als 8,5 mm, aber ohne durchgehenden Einzelstift wie beim PC104-Typ, der
  unten verworfen wird) oder einem **längeren Standard-Stift** (länger als
  6,0 mm mattend, bei derselben Lieferantenfamilie) blieb erfolglos: die
  generischen 2,54-mm-Serien auf LCSC bieten für Stiftleisten regelmässig
  nur die 6,0/3,0-mm-Kombination, für Buchsenleisten regelmässig maximal
  8,5 mm — jenseits davon wird es entweder ein Sonderpreis-Einzelfund oder
  ein Bauteil mit durchgehendem Stift (siehe unten).

**Verworfen: ZHOURI 2,54-2×20 PC104 (LCSC C35165).** Diese „Buchse" mit
12,3 mm Isolationshöhe (Datenblatt, Masszeichnung „8,5±0,2" Gehäuse plus
„12,46±0,2" / „23,50" lange durchgehende Stiftbeine) ist elektrisch ein
**Sockel-plus-langer-Stift in einem Bauteil** — genau die Bauform, die der
Vertrag ausdrücklich ausschliesst („ein echter Stapelstecker wäre hier
falsch: sein langer Stift bildet oben und unten denselben Kontakt").
Deshalb nicht als Ersatz verwendet, obwohl die Höhe besser passen würde.

**Ergebnis für Aufgabe 2, Schritt 2 — keine stillschweigende Ausweichung:**
Mit den zwei belegten Standard-Bauteilen (C50980 / C2977589) lässt sich der
Vertrag mit **15,0 mm** rechnerisch erfüllen, aber nur mit einer knappen,
toleranzgefährdeten Einstecktiefe von 1,1 mm. Drei Wege stehen offen, und
die Entscheidung darüber liegt beim Auftraggeber:

1. **So lassen** und die 1,1 mm als ausreichend akzeptieren — mit dem
   Risiko, dass ungünstige Toleranzstapel die Verbindung im Extremfall zu
   locker machen.
2. **`STAPEL_ABSTAND` verringern** (z. B. auf 14,0–14,3 mm), um mehr
   Einstecktiefe zu gewinnen — dann muss geprüft werden, ob die 10 mm
   hohen Schraubklemmen (Design-Doc, Abschnitt „Mechanik") noch passen;
   der ursprüngliche Grund für 15 mm war gerade deren Höhe plus Reserve.
3. **Sonderbauform suchen/bestellen lassen** (z. B. eine Buchse mit mehr
   als 8,5 mm bei einem anderen Hersteller/Distributor als LCSC) — hier
   nicht weiter verfolgt, weil ausserhalb des Bindungsrahmens „nur
   gesichtete LCSC/JLCPCB-Nummern".

### Nachtrag 2026-08-31 — Entscheidung des Auftraggebers: doch der Stapelstecker

Der Auftraggeber hat nach Prüfung dieses Befundes entschieden: **der
2×20-Signalstecker wird der oben verworfene PC104-Stapelstecker (LCSC
C35165)** — nicht mehr das Buchse/Stift-Paar C2977589/C50980. Begründung
und Grenzen dieser Entscheidung stehen ausführlich in Beleg 6 unten; hier
nur die nachgerechnete Geometrie, weil sie dieselbe Systematik wie oben
verwendet, nur mit einem anderen Bauteil.

**Geometrie beim durchgehenden Stift.** Anders als beim Buchse/Stift-Paar
sitzt hier auf **jedem** Modul dieselbe Buchse-mit-langem-Stift (C35165).
Der Stift von Modul A führt durch dessen eigene Platine (1,6 mm) hindurch
und ragt dann weiter nach unten in die Buchse von Modul B hinein:

    M = Stiftlänge unter dem Gehäuse − Platinendicke von A
      = 12,46 mm − 1,6 mm = 10,86 mm  (Nettoreichweite unter A's Unterseite)
    F = Gehäusehöhe der Buchse über B's Oberseite = 8,5 mm  (unverändert)

Dieselbe Bedingung wie oben (M ≤ G ≤ M + F, mit G = STAPEL_ABSTAND −
1,6 mm) ergibt jetzt:

    M + F = 10,86 mm + 8,5 mm = 19,36 mm
    G(15,0 mm) = 15,0 mm − 1,6 mm = 13,4 mm

    M = 10,86 mm ≤ 13,4 mm  → kein Anschlagen, 2,54 mm Puffer
    Einstecktiefe = 19,36 mm − 13,4 mm = 5,96 mm  → komfortabel

Umgestellt nach dem gültigen Bereich für `STAPEL_ABSTAND` (Bedingung
M ≤ G ≤ M+F, G = STAPEL_ABSTAND − 1,6 mm):

    STAPEL_ABSTAND_min = M + 1,6 mm  = 10,86 + 1,6  = 12,46 mm
    STAPEL_ABSTAND_max = M+F + 1,6 mm = 19,36 + 1,6 = 20,96 mm

**Ergebnis: 15,0 mm liegt komfortabel im gültigen Bereich [12,46 mm;
20,96 mm]**, mit 5,96 mm rechnerischer Einstecktiefe — deutlich mehr
Reserve als die 1,1 mm des ursprünglich geprüften Paars. Auch im
ungünstigsten Toleranzfall (±0,2 mm auf beiden Bauteilmassen, ±0,16 mm
Platinendicke) bleibt die Einstecktiefe über 5,5 mm; eine Nachrechnung mit
den etwas niedrigeren, automatisch aus dem LCSC-Attributfeld gelesenen
Werten (8,3 mm statt 8,5 mm, 12,3 mm statt 12,46 mm — kleine Abweichung
zur direkt aus der Datenblattzeichnung gelesenen Zahl, vermutlich Rundung
der automatischen Attributextraktion) ändert daran nichts Wesentliches
(M+F ≈ 19,0 mm, Einstecktiefe ≈ 5,6 mm bei 15,0 mm).

**`STAPEL_ABSTAND` muss also NICHT geändert werden.** Die Vermutung des
Auftraggebers, es könnte auf 12,6 mm sinken müssen, hat sich mit den
tatsächlich gelesenen Datenblattzahlen nicht bestätigt — 15,0 mm passt mit
gutem Spielraum. Umgesetzt in `tools/stack_spec.py` als Kommentar bei
`STAPEL_ABSTAND` und in den neuen Konstanten `STECKER_STAPEL`/
`STECKER_KETTE`.

**Unabhängige Bestätigung, nicht aus dem Datenblatt:** PC/104 ist ein
dokumentierter Industriestandard mit **fest definiertem** Platinenabstand
von 0,600 Zoll = 15,24 mm (Quelle: PC/104-Consortium, `pc104.org/hardware-
specifications/pc104/`; unabhängig bestätigt durch Samtec, die für exakt
diesen Standard passende Abstandsbolzen mit 15,24 mm Stapelhöhe führen).
Das hier gewählte Bauteil trägt den Namen „PC104-2\*NA+1“ und ist damit
mit hoher Wahrscheinlichkeit für genau diesen Industriewert ausgelegt —
15,24 mm liegt nur 0,24 mm über unserem Vertragswert 15,0 mm, tief im oben
berechneten gültigen Bereich. Das ist ein unabhängiger Plausibilitätscheck
von ausserhalb der Datenblattzeichnung, kein Ersatz für die eigene
Rechnung, aber eine Bestätigung, dass die eigene Dimensionsinterpretation
der Zeichnung (M und F wie oben zugeordnet) nicht offensichtlich falsch
ist.

> **Überholt seit 2026-08-31 (Aufgabe 5e), s. Beleg 13.** Die hier für den Kettenstecker gewählten bedrahteten Teile (C492401 / C541849) sind nicht baubar — zwei bedrahtete Hälften am selben Ort brauchten dieselben Bohrungen. Der Kettenstecker ist jetzt ein **SMD-Paar**, Einstecktiefe 5,60 statt 3,1 mm.

**Der Kettenstecker reproduziert den ursprünglichen Befund unverändert.**
Die eine Leitung, die weiterhin aufgetrennt werden muss (`SEL`), bekommt
zwangsläufig wieder ein normales Buchse/Stift-Paar (kein Durchgangsstift
möglich, sonst liesse sie sich nicht auftrennen — derselbe Grund, der den
2×20-Stecker ursprünglich zum Paar gemacht hatte). Die dafür gefundenen,
extra für die Zweipoligkeit gesichteten Bauteile XFCN PZ254V-11-02P
(C492401, Stift) und XFCN PM254V-11-02-H85 (C541849, Buchse) tragen
**exakt dieselben Masse** wie C50980/C2977589 (6,0/3,0 mm bzw. 8,5 mm,
beide Datenblätter/Attribute gesichtet) — die Rechnung von oben gilt
deshalb unverändert: **1,1 mm Einstecktiefe bei 15,0 mm, derselbe dünne
Rand wie ursprünglich gefunden.** Der Umstieg auf den Stapelstecker löst
das Höhenproblem nur für die 39 durchgereichten Leitungen, nicht für den
Kettenstecker. Das ist keine neue Erkenntnis, sondern derselbe Befund wie
oben, jetzt auf einen kleineren, eigenständigen Stecker konzentriert statt
über den ganzen 40-Pin-Stecker verteilt — hier explizit festgehalten, weil
das beim ersten Lesen der Aufgabenstellung leicht überlesen werden könnte:
„zur selben Bauhöhe passen" heisst nicht „dasselbe Höhenproblem gelöst".

## Beleg 2 — D-Flipflop mit asynchronem Löscheingang: gefunden

**Ergebnis: Ja, es gibt eines, JLCPCB-bestückbar.** `SN74LVC1G175DCKR`
(Texas Instruments), LCSC C202238, Gehäuse SOT-363-6 (6 Pins).

**Primärquelle, direkt gelesen:** TI-Datenblatt `SN74LVC1G175`, Dokument
SCES560G, „MARCH 2004 – REVISED JUNE 2015“ (heruntergeladen von
`ti.com/lit/ds/symlink/sn74lvc1g175.pdf`). Titel bereits im Dokumentkopf:
„SN74LVC1G175 Single D-Type Flip-Flop With Asynchronous Clear“. Abschnitt 3
„Description“, wörtlich: „The SN74LVC1G175 device has an asynchronous
clear (CLR) input. When CLR is high, data from the input pin (D) is
transferred to the output pin (Q) on the clock's (CLK) rising edge. When
CLR is low, Q is forced into the low state, regardless of the clock edge
or data on D.“ Abschnitt 5 „Pin Configuration and Functions“ zeigt für das
hier gewählte Gehäuse „DCK Package, 6-Pin SC70“ die Pinbelegung 1=CLK,
2=GND, 3=D, 4=Q, 5=VCC, 6=CLR (aktiv LOW, Balken über CLR im Schaltzeichen
und in der Pin-Tabelle als „Clear Data Input“ beschriftet) — exakt das
Gehäuse von C202238 (LCSC-Attribut „SC70(6)“ bzw. „SOT-363-6“, dieselbe
Bauform unter anderem Namen).

Ergänzend, nicht als Ersatz für die Primärquelle: Nexperia führt denselben
Standardtyp unter identischem Familiennamen 74LVC1G175 (Datenblatt Rev. 11,
15. Aug. 2023) mit gleicher Funktion („master reset MR, asynchronous
active LOW“) — die beiden Hersteller bieten pin- und funktionskompatible
Varianten desselben Typs an. Die vorherige Fassung dieses Dokuments zitierte
irrtümlich nur die Nexperia-Quelle für ein bei LCSC als TI-Bauteil
gesichtetes Teil; korrigiert auf die tatsächliche Herstellerquelle des
gesichteten Bauteils. Auf der tatsächlich
gesichteten LCSC-Produktseite steht die TI-Beschreibung wörtlich „Single
D-Type Flip-Flop With Asynchronous Clear".

**Wichtige Korrektur unterwegs — nicht 74LVC1G74, nicht 74LVC1G79:**
Zwei andere Kandidaten aus der ersten Web-Recherche mussten verworfen
werden, nachdem ich die echten Datenblätter gelesen hatte (nicht nur
Suchmaschinen-Kurzfassungen):

- **74LVC1G74** (Nexperia, gesichtet als `74LVC1G74GT,115`, LCSC C548415):
  hat zusätzlich zum Reset auch einen Set-Eingang UND einen invertierten
  Ausgang Q̄ — macht 8 Signale (D, CP, SD, RD, Q, Q̄, VCC, GND) nötig.
  Gehäuse laut LCSC-Produktseite tatsächlich **XSON-8**, nicht SC-70/SOT.
  Nur 75 Stück Lagerbestand am Stichtag — für unseren Zweck ohnehin
  überdimensioniert (wir brauchen keinen Set-Eingang, kein Q̄).
- **74LVC1G79** (Nexperia): eine WebSearch-Kurzfassung behauptete, dieses
  Bauteil habe einen Reset-Eingang in einem 6-Pin-SOT-363. Das
  tatsächliche Nexperia-Datenblatt (Rev. 16, 9. Sept. 2025) widerlegt das:
  Pinbelegung ist nur D, CP, GND, Q, VCC (5 Pins, Funktionstabelle kennt
  **kein** Reset-Signal überhaupt) — ein einfaches Flipflop ohne jeden
  Löscheingang, in SOT-353 (5-Pin). Die Web-Kurzfassung war schlicht
  falsch; verworfen zugunsten des selbst gelesenen PDF.

**Warum SOT-363-6 statt SOT-353/SC-70 (5-Pin), wie in der Aufgabe
gewünscht:** Ein Flipflop mit Löscheingang braucht mindestens sechs
Signale (D, CP, Löscheingang, Q, VCC, GND) — eines mehr, als das reine
5-Pin-SOT-353 (D, CP, Q, VCC, GND, wie beim löscheingangslosen
74LVC1G175-Vorgänger 74LVC1G79) bietet. SOT-363-6 (auch SC-70-6 genannt)
ist dieselbe Gehäusefamilie und Baugrösse, nur mit einem sechsten Anschluss
— das ist die kleinstmögliche Bauform für diese Funktion, keine
gleichwertige 5-Pin-Alternative existiert.

**Was der Löscheingang am Sockel zusätzlich braucht:** `MR̄` ist aktiv
LOW und muss vom Sockel (oder lokal) angesteuert werden. Zwei Wege, beide
technisch gangbar, Entscheidung nicht hier getroffen:

1. **Neue globale Leitung** (z. B. `SEL_CLR`, aktiv LOW, vom Sockel über
   den 2×20-Stecker durchgereicht). Das ist eine Vertragsänderung: ein
   neuner Eintrag in `RESERVIERT`/`PIN_ROLLE` (`tools/stack_spec.py`) —
   verbindlich laut Vertrag „nicht zu ändern" ohne die Erlaubnis des
   Auftraggebers. Vorteil: der Sockel kann die Kette **jederzeit**
   erneut löschen, nicht nur beim Einschalten.
2. **Lokales RC-Power-on-Reset pro Modul**, ohne neue Leitung: ein
   passives RC-Glied an `MR̄`, das beim Hochfahren der Versorgung kurz LOW
   hält und dann freigibt. Passt gut zur tatsächlichen Anforderung des
   Vertrags — der verlangt das Leertakten ausdrücklich nur „bevor er
   FLASH_MODE das erste Mal auf 1 setzt", also einmalig beim Einschalten
   (Design-Doc, Abschnitt „Einschaltzustand"). Da laut Vertrag ausserdem
   kein Hot-Plug vorgesehen ist („Module werden stromlos gesteckt"),
   schalten alle Module gemeinsam mit dem Sockel ein — ein lokales RC-POR
   pro Modul feuert dann bei jedem Einschalten genau einmal, deckt exakt
   den geforderten Fall ab und braucht **keine** Vertragsänderung. Nachteil:
   die Zeitkonstante hängt von Bauteiltoleranzen ab (muss mit Marge gegen
   die Versorgungs-Anstiegszeit ausgelegt werden) und der Sockel kann die
   Kette später nicht mehr aktiv nachlöschen — dafür bliebe weiterhin das
   Leertakten als Rückfalloption.

Mit diesem Löscheingang **entfällt das Leertakten** in beiden Fällen für
den Einschaltfall — Weg 1 ersetzt es vollständig und wiederholbar, Weg 2
deckt exakt den einmaligen Einschaltfall ab, den der Vertrag verlangt.

## Beleg 3 — Gatter (Invertierung, RESET-/BOOT0-AND): JLCPCB-bestückbar

Die in `hardware/bauteile.md`, Beleg 4, genannten Kandidaten wurden auf
echten LCSC-/JLCPCB-Produktseiten geprüft:

- **Invertierung Q** (für RESET): `SN74LVC1G04DCKR` (TI), LCSC C8207,
  Gehäuse SOT-353 (SC-70-5) — genau die in der Aufgabe gewünschte
  Winzbauform. JLCPCB-Produktseite bestätigt SMT Assembly.
- **RESET = FLASH_MODE ∧ ¬Q und BOOT0 = FLASH_MODE ∧ Q** (2× 2-Input-AND):
  `74LVC2G08GT,115` (Nexperia), LCSC C548580, Gehäuse **XSON-8** (1×2 mm,
  kein 6-Pin-SOT möglich — ein Dual-Gatter mit zwei unabhängigen
  2-Input-AND-Funktionen braucht mindestens acht Signale: 2×(2 Eingänge +
  1 Ausgang) + VCC + GND = 8. Das deckt **beide** AND-Funktionen
  (RESET und BOOT0) in einem einzigen Bauteil ab — pro Modul also ein
  einziger Dual-AND-Chip statt zwei Einzel-AND-Chips.

**Zur Stückzahl-Angabe in der Aufgabenstellung:** Die Aufgabentabelle
nennt „2× NOT und 3× AND". Das deckt sich **nicht** mit der tatsächlichen
Gatterlogik in `tools/kette.py` (Funktion `modul_zustand`) und mit
`hardware/bauteile.md`, Beleg 4: dort sind es pro Modul **1× NOT und
2× AND** (`SEL_OUT` braucht seit der Korrektur in Etappe 1a kein eigenes
Gatter mehr, es ist direkt der Flipflop-Ausgang `Q`). Ich habe mich an den
Code und die bereits geprüfte Herleitung in `bauteile.md` gehalten, nicht
an die möglicherweise veraltete Zahl in der Aufgabenstellung — das sollte
beim Lesen auffallen, falls die „2×/3×"-Angabe woanders noch eine Rolle
spielt.

### Nachtrag 2026-08-31 — RESET-Gatter verpolt: aus dem AND wird ein NAND

**Befund (gemeldeter Fehler dieser Aufgabe):** `tools/kette.py` modelliert
`RESET = flash_mode ∧ ¬q` als **aktiv HIGH** ("1 = im Reset gehalten").
Der Reset-Eingang des STM32C011F6P6 heisst aber `NRST` (PF2-NRST) und ist
laut Datenblatt **aktiv LOW**. Im Stand vor dieser Korrektur trieb das
UND-Gatter oben (Einheit 1 von `74LVC2G08GT,115`, C548580) sein Ergebnis
direkt auf `NRST` — verpolt: das Modul liefe genau dann, wenn es im Reset
stehen soll, und umgekehrt.

**Auflösung:** Aus dem UND-Gatter für `NRST` wird ein NAND —
`NRST = ¬(FLASH_MODE ∧ ¬Q)` — das ist exakt die fehlende Invertierung,
ohne ein zusätzliches Gatter im Signalweg. `BOOT0 = FLASH_MODE ∧ Q` bleibt
unverändert ein AND (der Bootloader-Pin des STM32 ist aktiv HIGH, dort
liegt keine Verpolung vor).

**Warum jetzt zwei Einzel-Gatter-ICs statt eines Dual-Gatter-ICs.** Der
bisherige Dual-AND (`74LVC2G08GT,115`, XSON-8, C548580) bildete beide
AND-Funktionen in einem Bauteil. Ein homogenes „2G"-Dual-Gatter kann aber
nur **eine** Funktion für beide Einheiten liefern (2× AND oder 2× NAND,
nicht gemischt) — ein Bauteil mit einer AND- und einer NAND-Einheit in
einem Gehäuse wurde bei LCSC/JLCPCB nicht gefunden. Da `NRST` jetzt NAND
und `BOOT0` weiterhin AND braucht, ersetzen zwei Einzel-Gatter-ICs den
einen Dual-Gatter-IC:

- **NRST-Gatter:** `SN74LVC1G00DCKR` (TI), LCSC C8185, SOT-353 (SC-70-5).
- **BOOT0-Gatter:** `SN74LVC1G08DCKR` (TI), LCSC C7832, SOT-353 (SC-70-5).

Beide auf ihren LCSC-Produktseiten gesichtet (nicht aus dem Gedächtnis):
`lcsc.com/product-detail/C8185.html` nennt das Gehäuse „SOT-353“,
`lcsc.com/product-detail/C7832.html` „SC-70-5“ — dieselbe Bauform unter
zwei gängigen Namen, mit identischer Pinbelegung (1,2 Eingänge, 3 GND,
4 Ausgang, 5 VCC — selbst aus der KiCad-Symbolgeometrie nachgemessen,
`tools/sch/symlib.py`), also 1:1 austauschbar mit dem bereits im Entwurf
verwendeten NOT-Gatter U102 (`SN74LVC1G04DCKR`, C8207, ebenfalls
SOT-353) — exakt „gleiches Gehäuse, gleicher Platz".

**Bauteilzahl, ehrlich benannt:** Die Gatter-**logik** bleibt bei drei
Funktionen (1× NOT, 1× NAND, 1× AND — unverändert gegenüber der
Aufgabenzählung), aber die **physische** IC-Zahl steigt von einem
Dual-Gatter-Bauteil auf zwei Einzel-Gatter-Bauteile (ein IC mehr auf der
Stückliste als unmittelbar zuvor). Das ist keine stillschweigende
Abweichung: ein gemischtes AND/NAND-Dual-Gatter wurde gesucht und nicht
gefunden: mangels passendem Bauteil ist das der einzige gangbare Weg, ohne
einen vierten Gattertyp (einen zusätzlichen Inverter) einzuführen.

**Umgesetzt:**

- `tools/sch/modulsockel.py`: `U103` ist jetzt der NAND-Einzelgatter-IC
  (treibt `NRST` direkt), `U104` neu als AND-Einzelgatter-IC (treibt
  weiterhin `BOOT0`); das Netz an MCU-Pin 6 heisst jetzt `NRST` statt
  `RESET`, um die Aktiv-LOW-Polung im Netznamen sichtbar zu machen.
- `tools/kette.py`: Modellfunktion `modul_zustand()` unverändert (der
  Test hängt an der Aussage "RESET=1 heisst im Reset gehalten"), Docstring
  ergänzt um den Hinweis auf die Hardware-Invertierung.
- `tests/test_modulsockel.py`: neue Zusicherung, dass das an `NRST`
  angeschlossene Gatter invertierend (NAND) ist, nicht nur eine
  Gatterzahl-Prüfung.

### Nachtrag 2026-08-31, zweite Runde — der zusätzliche Baustein war vermeidbar

**Befund der Prüfung:** Die obige Aufteilung in zwei Einzel-Gatter-ICs
übersah den Standardtrick, dass **ein NAND mit kurzgeschlossenen
Eingängen ein Inverter ist** — `¬Q = NAND(Q,Q)`. Damit sind die
NOT-Funktion (`Q → NQ`) und das NRST-Gatter (`NAND(FLASH_MODE, NQ)`)
beide NAND und passen in **ein** Doppel-NAND-Bauteil; nur `BOOT0` bleibt
als eigenständiges AND übrig. Physische Gatter-ICs: **zwei statt drei**
(vorher: NOT + NAND + AND je einzeln).

**Bauteil:** `SN74LVC2G00DCUR` (TI), LCSC **C206109**, „Dual 2-Input
Positive-NAND Gate". **Wichtige Korrektur der zunächst genannten
Gehäuseangabe:** Trotz der Namensähnlichkeit zum SOT-363-Flipflop
(`SN74LVC1G175DCKR`) ist dieses Bauteil **nicht** SOT-363/SC-70-6 —
das auf der LCSC-Produktseite (`lcsc.com/product-detail/C206109.html`)
tatsächlich genannte Gehäuse ist **„VSSOP-8-0.5mm"**, unabhängig
bestätigt über eine zweite Suche (DigiKey/weitere Distributoren nennen
denselben Wert: „NAND Gate IC with 2 channels in an 8-VSSOP package").
Das ist auch physikalisch zwingend: SOT-363/SC-70-6 hat nur 6 Anschlüsse,
ein Dual-2-Input-Gatter braucht mindestens 8 (2×(2 Eingänge + 1 Ausgang)
+ VCC + GND) — ein Dual-Gatter passt in dieses 6-Pin-Gehäuse gar nicht.
Verwendeter KiCad-Footprint: `Package_SO:VSSOP-8_2.3x2mm_P0.5mm`
(0,5-mm-Pitch, passend zur LCSC-Gehäuseangabe).

**Verdrahtung (`tools/sch/modulsockel.py`, U102):** Pin-Gruppierung laut
KiCad-Symbol `74xGxx:74LVC2G00` (`tools/sch/symlib.py`, `_subunits()`
nachgemessen): Einheit 1 = Pins {1,2,7} (Eingänge 1/2, Ausgang 7),
Einheit 2 = Pins {3,5,6} (Eingänge 5/6, Ausgang 3), Einheit 3 = Pins
{4,8} (GND/VCC, gemeinsam). Einheit 1 bekommt an beiden Eingängen
`SEL_OUT` (Q) — die absichtliche Kurzschaltung, die den Inverter bildet
— und liefert `NQ` auf Pin 7. Einheit 2 bildet aus `FLASH_MODE` und `NQ`
das Ergebnis `NRST` auf Pin 3, direkt an PF2-NRST des MCU. Im Code
ausführlich kommentiert, warum die zwei kurzgeschlossenen Pins **kein**
Fehler sind (sonst „repariert" sie der nächste Blick).

**Ersetzt/verworfen (Tabelle oben nachgezogen):**
- `SN74LVC1G04DCKR` (NOT, C8207) — Bauform weiterhin korrekt geprüft,
  aber nicht mehr verbaut.
- `SN74LVC1G00DCKR` (NAND, C8185) — dito, ersetzt durch eine Einheit des
  Dual-NAND.
- `SN74LVC1G08DCKR` (AND, C7832) — **bleibt unverändert** für `BOOT0`;
  kein Gegenstück im Dual-NAND, weil ein homogenes Dual-Gatter nicht eine
  AND- und eine NAND-Einheit zugleich liefern kann.

**Umgesetzt:**

- `tools/sch/modulsockel.py`: `U102` ist jetzt `SN74LVC2G00DCUR`
  (Dual-NAND, drei Platzierungen wie zuvor beim verworfenen Dual-AND:
  Einheit 1 = NOT via NAND(Q,Q), Einheit 2 = NRST-NAND, Einheit 3 =
  Versorgung). `U103` bleibt der Einzel-AND-Gatter-IC für `BOOT0`
  (vorher `U104`, umbenannt, da die Lücke durch die Konsolidierung
  entfällt). Neue Footprint-Konstante `FP_VSSOP8`.
- `hardware/bauteile-1b.md`: neue Zeile für `SN74LVC2G00DCUR` (C206109),
  die drei ersetzten Einzel-Gatter-Zeilen als verworfen markiert (Bauform
  weiterhin korrekt), Gehäuseangabe „VSSOP-8", nicht „SOT-363" — mit
  eigener Anmerkung, weil das zunächst falsch vermutet wurde.
- `tests/test_modulsockel.py`: bestehende Polaritäts-Zusicherung bleibt
  gültig (sucht das treibende Bauteil an `NRST` generisch über die
  Verdrahtung, nicht über eine feste Referenzbezeichnung) — geprüft
  gegen `libid == "74xGxx:74LVC2G00"`, die neue Multi-Unit-Einheit.
- `tests/test_modulsockel.py`: neuer ERC-Testschritt (siehe unten).

## Beleg 4 — Leistungsstecker: Bauform gewählt, Strombelastbarkeit belegt

> **Überholt seit 2026-08-31 (Aufgabe 5e), s. Beleg 13.** Die hier gewählte bedrahtete Buchse/Stift-Paarung (C2977590 / C66690) ist nicht baubar: beide Hälften müssen am selben Ort sitzen und bräuchten dann dieselben Bohrungen. Der Leistungsstecker ist jetzt ein **SMD-Paar**. Die Stromrechnung unten (Engpass Buchse, zwei Kontakte je Ader, ~5 A vor Derating) gilt unverändert weiter — die SMD-Buchse trägt dieselben 2,5 A je Kontakt.

**Bauform:** dieselbe 2,54-mm-Stift-/Buchsenleisten-Familie wie der
Signalstecker (BOOMELE/ZHOURI), aber als eigener, getrennter 2×2-Stecker
— getrennt geführt vom Signalstecker, wie es das Design-Doc verlangt
(„Getrennt vom Signalstecker geführt, damit Motorströme nicht neben
empfindlichen Leitungen liegen"). Dieselbe Familie wurde gewählt, damit
Stiftlänge und Buchsenhöhe zum bereits gerechneten Stapelabstand passen
(Beleg 1) — ein anderer Verbindertyp hier hätte eine zweite,
unabhängige Höhenrechnung nötig gemacht.

- Buchse: C2977590 (ZHOURI 2,54-2×2), LCSC-Produktseite bestätigt
  „2.5A"-Stromangabe pro Kontakt und „8.5mm insulation height" — identische
  Werte wie beim 2×20-Signalstecker (C2977589), nur mit weniger Positionen.
- Stift: C66690 (BOOMELE 2,54-2×2P), LCSC-Produktseite bestätigt „3A" pro
  Kontakt, „6mm"/„3mm" Stiftlänge — identisch zu C50980.

**Strombelastbarkeit (belegt, nicht angenommen):** Engpass ist die Buchse
mit **2,5 A pro Kontakt** (Datenblatt-Rohdaten, „Current rating: 2.5AMP";
die Stiftleiste erlaubt mit 3 A mehr). Bei zwei parallelen Kontakten je
Ader (24 V auf zwei der vier Positionen, GND auf den anderen zwei) ergibt
sich rechnerisch **bis 5 A pro Ader vor Derating** — dieselbe Vorsicht wie
schon in `hardware/bauteile.md`, Beleg 3, für die Etappe-1a-Schätzung: das
ist eine einfache Parallel-Summe der Einzelkontakt-Nennwerte, keine
geprüfte Aussage über reale Stromaufteilung bei ungleichen
Kontaktwiderständen, und keine Herstellerangabe für den Parallelbetrieb
selbst. Der Vertrag legt keinen Strombudget-Wert für den ganzen Stapel
fest (`docs/superpowers/specs/2026-08-28-picostack-design.md` nennt nur
„eigener Stecker, nur 24 V und Masse, mehrere Kontakte parallel", ohne
Zahl) — die Positionsanzahl (2×2) ist hier ein **Vorschlag**, kein
Vertragswert. Reicht 5 A vor Derating nicht (z. B. bei mehreren
Motor-Modulen gleichzeitig unter Last), lässt sich mit einer grösseren
Positionszahl (z. B. 2×3, je 3 parallele Kontakte) mehr herausholen, ohne
die Höhenrechnung aus Beleg 1 zu ändern — die Familie bleibt dieselbe.

## Beleg 5 — Klemmen: 3-polig gefunden, 2-polig unverändert

- **2-polig** (`DB128L-5.08-2P-GN-S`, LCSC C395868): unverändert aus
  Etappe 1a / LED-Dimmer-Projekt übernommen, nicht neu recherchiert (siehe
  `hardware/bauteile.md`).
- **3-polig** (`DB128L-5.08-3P-GN-S`, LCSC C395869): auf der
  LCSC-Produktseite gesichtet, selbe Farbe/Baureihe wie die bereits
  geprüfte 2-polige Klemme (DORABO-Hersteller, „DB128L-5.08"-Familie).
  Datenblatt-Rohdaten: 16 A, 300 V, M2-Schraube, 12–22 AWG (2,5 mm²),
  −40 °C…+105 °C. JLCPCB listet die Geschwister-Varianten derselben
  Baureihe (2P, 3P-OG-S, 3P-BK-S, 4P) mit „Economic and Standard"-PCBA;
  die JLCPCB-Seite für exakt die GN-S-Farbvariante wurde nicht einzeln mit
  eigener URL gesichtet, die LCSC-Produktseite mit der vollständigen
  Spezifikation aber schon.

## Beleg 6 — Entscheidung Stapelstecker: warum zuerst ausgeschlossen, warum jetzt doch

**Warum ursprünglich ausgeschlossen (Etappe 1b, erste Fassung dieses
Dokuments, und schon im Design-Doc):** Der Signalstecker führt alle 40
Pico-Pins durch den Stapel. Ein „echter Stapelstecker" — eine Buchse mit
einem einzigen, durchgehenden Stift statt getrennter Buchse oben/Stift
unten — bildet auf **jedem** dieser 40 Pins denselben elektrischen Knoten
von der Platinenoberseite bis zur Unterseite. Für 39 der 40 Leitungen ist
das gewollt: I²C, die Flash-UART, `SEL_CLK`, `FLASH_MODE`, `NOTAUS`,
Versorgung und alle freien GPIO sind **globale oder durchgereichte Netze**
— im ganzen Stapel dasselbe Signal, unabhängig davon, welches Modul gerade
angesprochen wird. Genau **eine** Leitung ist anders: `SEL`, die
Auswahlkette. Sie ist ein Schieberegister (`tools/kette.py`) — jedes
Modul haelt seinen eigenen Zustand `Q` in einem Flipflop, und `SEL` muss
von Modul zu Modul **unterbrochen** werden koennen (D des einen Moduls ist
Q des Moduls darueber, nicht dieselbe Leitung). Ein durchgehender Stift
kann das nicht: er verbindet `SEL` elektrisch mit sich selbst durch den
ganzen Stapel, und aus der Kette würde ein einziger gemeinsamer Knoten —
das Schieberegister bräche zusammen, mehrere Module wären gleichzeitig
„ausgewählt". Deshalb stand in der ersten Fassung dieses Dokuments (siehe
Beleg 1, unveränderter Text oben): der PC104-Stapelstecker C35165 sei
„elektrisch ein Sockel-plus-langer-Stift in einem Bauteil — genau die
Bauform, die der Vertrag ausdrücklich ausschliesst" und wurde verworfen.

**Was sich geändert hat, ist nicht die Physik, sondern der Zuschnitt.**
Der ursprüngliche Ausschluss galt dem *ganzen* 2×20-Stecker, weil er alle
40 Leitungen auf einmal traf. Er bleibt für **eine** Leitung richtig
(`SEL`) — aber falsch verallgemeinert für die anderen 39. Die Lösung des
Auftraggebers trennt das: Der 2×20-Stecker traegt nur noch die 39
Leitungen, die ohnehin durchgehend sein sollen, als echter Stapelstecker
mit den bekannten Vorteilen (ein Bauteil statt zwei, mechanisch belastbare
lange Kontakte, siehe Beleg 1 Nachtrag für die Hoehenrechnung). `SEL`
bekommt einen eigenen, kleinen, **nicht** durchgehenden Stecker
(Kettenstecker, C492401/C541849) — dort gilt der ursprüngliche Ausschluss
unveraendert, und genau deshalb ist der Kettenstecker ein normales
Buchse/Stift-Paar wie der alte 2×20-Stecker es war, mit demselben
1,1-mm-Befund (Beleg 1, Nachtrag).

**Was das für den Vertrag bedeutet (`tools/stack_spec.py`):**

- `SEL` faellt aus `RESERVIERT` und `PIN_ROLLE` heraus; Pin 4 (GP2) ist
  wieder `"frei"`.
- Zwei neue Konstanten `STECKER_STAPEL` und `STECKER_KETTE` halten Bauteil,
  Hoehenrechnung und (fuer den Kettenstecker) die Pinbelegung fest, analog
  zu den anderen Vertragsgegenstaenden.
- `STAPEL_ABSTAND` bleibt bei 15,0 mm (Beleg 1, Nachtrag: passt komfortabel
  zum Stapelstecker; der Kettenstecker traegt weiterhin nur 1,1 mm
  Einstecktiefe, dokumentiert, nicht stillschweigend uebergangen).
- `docs/vertrag.md` wurde mit `python3 tools/vertrag_doku.py` neu erzeugt
  und zeigt jetzt einen eigenen Abschnitt „Stapelstecker und
  Kettenstecker" mit Bauteil, Hoehen und der Pinbelegung des
  Kettensteckers.
- `tests/test_stack_spec.py` prueft neu: `SEL` steht in keiner Rolle mehr,
  Pin 4 ist frei, und `STECKER_KETTE` traegt genau zwei Pins (`SEL` und
  `GND`).

### Zweite Runde 2026-08-31 — `STAPEL_ABSTAND` sinkt von 15,0 auf 13,0 mm

**Warum 15,0 mm nicht bleiben konnte.** Der obige Stand liess den
Kettenstecker mit rechnerisch nur **1,1 mm Einstecktiefe** stehen (Beleg 1,
Nachtrag) — an ihm haengt die ganze Auswahlkette. Zwei unabhaengige
Suchen (LCSC-Katalog und JLCPCB-Bibliothek) nach einer laengeren
einreihigen Stiftleiste blieben erfolglos: die gaengigen 2,54-mm-Serien
bieten fuer Stiftleisten regelmaessig nur die 6,0/3,0-mm-Kombination, wie
schon in Beleg 1 fuer den urspruenglichen Signalstecker festgestellt.
Ohne laengeres Bauteil bleibt nur, den Spalt selbst zu verkleinern.

**Warum 13,0 mm geht — mit belegten Zahlen, nicht geschaetzt.** Kleinerer
Spalt heisst mehr Einstecktiefe fuer beide Stecker, aber weniger Platz
fuer die Schraubklemmen, die den urspruenglichen 15-mm-Wert begruendet
hatten (Design-Doc, Abschnitt „Mechanik“). Vor der Entscheidung wurden
deshalb die tatsaechlichen Bauhoehen der drei infrage stehenden Bauteile
aus ihren Datenblaettern gelesen, nicht aus der groben Vorabschaetzung
„rund 10 mm“ uebernommen:

- **DB128L-5.08-2P-GN-S (C395868) und DB128L-5.08-3P-GN-S (C395869):**
  Datenblatt DORABO „DB128L-5.08-XXP-C-S“ (Zeichnungsdatum 2022.11.25,
  gesichtet ueber den auf der jeweiligen LCSC-Produktseite verlinkten
  `pdfUrl`, PDF-Hash `774f77501d8e260538e3ee59c3ecee93` — **dasselbe PDF
  fuer beide Bauteile**, weil es ein generischer Zeichnungssatz „XXP“ fuer
  alle Polzahlen dieser Baureihe ist). Seitenansicht, Bemassung **„10.10“**
  — das ist die Gesamthoehe des Klemmenkoerpers ueber der Platine; sie
  haengt in dieser Zeichnung nicht von der Polzahl ab (nur die Breite
  waechst mit „N×5.08“). Die zusaetzlich in derselben Zeichnung bemasste
  Breite „14.10“ (= (2−1)×5,08 mm + Randmass, stimmig fuer die 2-polige
  Ausfuehrung) bestaetigt, dass die Zeichnung tatsaechlich zu dieser
  Baureihe gehoert und nicht vertauscht wurde.
  → **Bauhoehe 10,10 mm**, fuer beide Klemmen gleich.
- **K7805-2000R3 (C2931187):** Datenblatt DEXU Electronics
  „K78xx-2000R3“, Rev. A0-2018.12 (gesichtet ueber den `pdfUrl` der
  LCSC-Produktseite, PDF-Hash `17983581d455f7b27113790e48e5474c`), Seite 2
  („产品特性“ / Produkteigenschaften), Zeile „外观尺寸“ (Aussenmasse):
  „长\*宽\*高 11.6\*7.5\*10.2mm“ (Laenge×Breite×**Hoehe**). Die separate
  Massskizze auf Seite 5 zeigt zusaetzliche Zahlen (u. a. „17.50“ fuer die
  Gesamthoehe inklusive der durchgesteckten Anschlussbeine unterhalb der
  Platine) — fuer die hier gesuchte Frage (Bauhoehe **oberhalb** der
  Platine, im Spalt) ist die explizite Textangabe „10.2mm“ eindeutig und
  wird verwendet.
  → **Bauhoehe 10,2 mm.**

**Rechnung bei 13,0 mm:**

    G = STAPEL_ABSTAND − PLATINE_DICKE = 13,0 − 1,6 = 11,4 mm

    Kettenstecker : Einstecktiefe = 14,5 − 11,4 = 3,1 mm   (statt 1,1 mm bei 15,0 mm)
    Stapelstecker : Einstecktiefe = 19,36 − 11,4 = 7,96 mm (statt 5,96 mm bei 15,0 mm)

    Rest ueber der Klemme (10,10 mm)  : 11,4 − 10,10 = 1,3 mm
    Rest ueber dem K7805  (10,2 mm)   : 11,4 − 10,2  = 1,2 mm

Beide Klemmenhoehen (10,10 mm und 10,2 mm) liegen **unter** der
11,0-mm-Reissleine, ab der der Auftraggeber die Entscheidung selbst
haette treffen wollen — 13,0 mm haelt, mit rundem 1,2–1,3 mm Luft ueber
der Klemme beziehungsweise dem K7805, und mit deutlich mehr Einstecktiefe
an beiden Steckern als vorher. Der K7805 sitzt zwar tatsaechlich nur auf
dem Sockel (oberste Platine, darueber kommt nichts mehr im Stapel), wurde
aber als worst-case gepruemft, falls ein kuenftiges Modul denselben
Regler in einem Spalt verwendet — auch dieser Fall passt.

**Toleranzhinweis, unveraendert aus Beleg 1:** Beide Steckerbauteile
tragen ±0,2 mm Fertigungstoleranz, die Platinendicke ±10 % (JLCPCB-
Standard). Im ungünstigsten Fall schrumpft jede der obigen Reserven
entsprechend — bei 1,2–1,3 mm Luft ueber den Klemmen und 3,1 mm
Einstecktiefe am Kettenstecker ist das ein deutlich engerer Rand als beim
Stapelstecker (7,96 mm), aber in allen vier Faellen bleibt die Reserve im
ungünstigsten Toleranzstapel positiv.

**Umgesetzt:**

- `tools/stack_spec.py`: `STAPEL_ABSTAND = 13.0`, neuer Kommentar mit der
  vollstaendigen Herleitung; neue Konstante `PLATINE_DICKE = 1.6`; neue
  Konstanten `KLEMME_HOEHE_MM = 10.10` und `K7805_HOEHE_MM = 10.2` mit
  Quellenangabe; `STECKER_KETTE` traegt jetzt `buchsenhoehe_mm` und
  `stiftlaenge_mm` als Masse statt eines fest hinterlegten
  `einstecktiefe_mm`-Werts; zwei neue Funktionen
  `EINSTECKTIEFE_STAPEL()`/`EINSTECKTIEFE_KETTE()` berechnen die
  Einstecktiefe aus `STAPEL_ABSTAND` und den Steckermassen, statt sie als
  Zahl zu duplizieren.
- `docs/vertrag.md` neu erzeugt mit `python3 tools/vertrag_doku.py` —
  zeigt jetzt 13,0 mm.
- `tests/test_stack_spec.py`: Wert auf 13,0 mm nachgezogen; zwei neue
  Zusicherungen pruefen, dass `EINSTECKTIEFE_STAPEL()` und
  `EINSTECKTIEFE_KETTE()` ueber einer Mindestschwelle liegen (2,0 mm,
  konservativ unter dem knappsten belegten Fall), und zwei weitere, dass
  ueber `KLEMME_HOEHE_MM` und `K7805_HOEHE_MM` noch Luft im Spalt bleibt
  — nicht nur die Zahl 13,0 selbst.

**Offen — ausdruecklich nicht in dieser Aufgabe erledigt:** Das Gehaeuse
(Aufgabe 9 dieser Etappe) wurde gegen den alten Wert `STAPEL_ABSTAND =
15,0 mm` entworfen bzw. ist dafuer vorgesehen und muss auf den neuen Wert
13,0 mm nachgezogen werden, sobald diese Aufgabe angegangen wird.

## Beleg 7 — Layout-Auflage: C3 muss nah an U2 Pin 1 sitzen (Aufgabe-4-Fix-1, 2026-08-31)

**Hintergrund.** `tools/sch/sockelplatine.py` setzt C1 (HF-Abblockung an
U2, den Reglerpins direkt benachbart) auf 100 nF/50 V statt der vom
Datenblatt für die K78xx-2000R3-Baureihe genannten 22 µF/50 V (Begründung
im Code: 22 µF/50 V ist in 0805/X7R keine sinnvolle Bauform). C3 (220 µF
radial, ohnehin für "Stützung am 24-V-Eingang" im Aufgabenbrief
vorgesehen) übernimmt dabei die vom Datenblatt eigentlich gemeinte
Speicherkapazität an U2s Eingang.

**Auflage, damit das haelt.** Diese Aufteilung funktioniert nur, wenn C3
tatsächlich **nah an U2 Pin 1 (IN)** sitzt — nicht irgendwo sonst auf der
Platine. Liegt zwischen C3 und U2 Pin 1 eine lange Leiterbahn, macht die
Schleifeninduktivität dieser Strecke die Stützwirkung zunichte: C3 kann
dann hochfrequente Stromtransienten am Reglereingang nicht mehr
abfangen, genau die Aufgabe, die die Absicht (C1 klein/HF, C3 groß/
Speicher) ihm zuweist. Das ist keine Platzierungsempfehlung, sondern eine
**Layout-Auflage für Aufgabe 6** (PCB-Layout der Sockelplatine): C3
gehört so nah wie mechanisch sinnvoll an U2 Pin 1, mit möglichst kurzer,
möglichst breiter Verbindung (kurze Schleife PWR24V zwischen C3⁺ und U2
Pin 1, ebenso kurzer Rückweg über GND). Der Schaltplan selbst kann diese
Auflage nicht erzwingen (Netzlisten kennen keine Distanz) — deshalb hier
schriftlich festgehalten, nicht nur im Code kommentiert.

## Beleg 8 — 3,3-V-Haushalt des Stapels, mit dem Motormodul nachgerechnet (Aufgabe 5)

**Aufgabe (Auftraggeber-Punkt 2 der Aufgabe 5):** Die Modul-MCU ziehen ihre
Versorgung aus der 3V3-Schiene, deren Quelle der interne Regler des Pico ist
(3V3_OUT, Pin 36). Nachzurechnen: wie viel darf extern entnommen werden, und
wie viele Module trägt das.

**Obergrenze aus dem Pico-Datenblatt.** Dieselbe Quelle wie bereits in
`hardware/bauteile.md`, Beleg 3, zitiert (Raspberry Pi Pico Datasheet,
Abschnitt „Pin Description", Beschreibung des Pins `3V3`): „This pin can be
used to power external circuitry (maximum output current will depend on
RP2040 load and VSYS voltage, it is recommended to keep the load on this pin
less than 300 mA)." Diese 300 mA sind explizit die Grenze für **externe**
Last — der RP2040-Eigenverbrauch selbst zieht aus VSYS über den internen
Regler, nicht aus dieser Zahl.

**Was ein Modul tatsächlich zieht — vollständiger als in Etappe 1a, weil das
Motormodul zwei neue Verbraucher an die 3V3-Schiene hängt, die es in Etappe
1a (reine Modul-MCU-Abschätzung) noch nicht gab:**

1. **Modul-MCU (STM32C011F6P6), unverändert aus `hardware/bauteile.md`,
   Beleg 3:** DS13866 Rev 3, Tabelle 27 „Current consumption in Run mode
   from flash memory", `IDD(Run)` bei 48 MHz (HSI48): typ. 3,40 mA, max.
   3,90 mA (25 °C), bis max. 4,90 mA (125 °C). Für diese Rechnung wird der
   ungünstigste Wert verwendet: **4,90 mA**.
2. **Zwei Kennwiderstand-Spannungsteiler pro Modul** (`tools/sch/
   modulsockel.py`, `_kennwiderstand()`: R104/R100 und R105/R101, je
   3V3–[ID_OBEN]–Knoten–[Kennwiderstand]–GND). Worst-case-Strom pro Teiler
   bei kleinstem tatsächlich vergebenen Kennwiderstand (`stack_spec.
   ID_WIDERSTAENDE[1]` = 680 Ω — der erste Eintrag, 0 Ω, ist laut
   `stack_spec.py`-Kommentar für „Modultyp 0x00, ungültig" reserviert und
   wird nie real bestückt, aber selbst mit ihm ändert sich die Rechnung
   kaum):

       I_Teiler = 3,3 V / (ID_OBEN + R_kenn) = 3,3 / (10000 + 680) ≈ 0,309 mA

   Zwei Teiler je Modul: **≈ 0,62 mA** (konservativ mit dem theoretischen
   0-Ω-Fall aufgerundet: 3,3/10000 × 2 = 0,66 mA).
3. **U1 VREF (DRV8876, Pin 5), neu gegenüber Etappe 1a:** liegt in diesem
   Modul direkt an 3V3 (wie im Altprojekt). Das DRV8876-Datenblatt (TI
   SLVSDS7B) nennt für VREF nur den zulässigen Spannungsbereich (Abschnitt
   6.3, „Recommended Operating Conditions": 0–3,6 V), **keinen eigenen
   Ruhestromwert** — VREF ist der Referenzeingang eines internen
   Komparators, kein Lastausgang. Ohne eine tatsächlich gelesene
   Datenblattzahl wird hier **keine** erfundene Zahl eingesetzt (Bindend-
   Regel dieser Aufgabe) — die Größenordnung eines Komparator-
   Referenzeingangs liegt allgemein im Nanoampere- bis niedrigen
   Mikroampere-Bereich, also um mindestens zwei Zehnerpotenzen unter den
   beiden obigen Posten. Die Budget-Aussage unten ändert sich dadurch
   nicht, selbst wenn der tatsächliche Wert am oberen Rand dieser
   Größenordnung läge.
4. **Logikgatter (U101 Flipflop, U102 Dual-NAND, U103 AND), neu gegenüber
   Etappe 1a:** CMOS-Standardlogik dieser Bauart liegt typischerweise im
   niedrigen einstelligen Mikroampere-Bereich statischer Stromaufnahme —
   auch hier keine einzeln aus einem gelesenen Datenblattwert belegte Zahl
   (die drei zugehörigen Datenblätter geben zwar `ICC`-Werte an, die wurden
   für diese Rechnung nicht extra herausgesucht, weil selbst ein
   pessimistischer zweistelliger µA-Wert je Gatter die Summe nicht in die
   Nähe der MCU- oder Kennwiderstand-Anteile brächte) — wie Punkt 3 eine
   vernachlässigbare Größenordnung, hier ausdrücklich als solche benannt,
   nicht verschwiegen.

**Rechnung pro Modul (Posten 1+2, die einzigen zahlenmäßig belegten):**

    I_Modul = 4,90 mA + 0,66 mA = 5,56 mA  (worst case, 125 °C)

**Wie viele Module das trägt:**

    N_max = 300 mA / 5,56 mA/Modul ≈ 53 Module

Zehn Module (die Zahl aus `hardware/bauteile.md`, Beleg 3): 10 × 5,56 mA =
**55,6 mA** — weit unter 300 mA, mit über fünffacher Reserve bis zur
theoretischen Grenze von ~53 Modulen. **Die Rechnung ist NICHT eng** — das
Ergebnis aus Etappe 1a (unkritisch) bleibt auch mit den beiden neuen, hier
erstmals berücksichtigten Verbrauchern (Kennwiderstände, VREF) bestehen; ein
eigener 3,3-V-Regler für den Stapel ist nach dieser Rechnung nicht nötig.
Die tatsächliche mechanische Obergrenze (wie viele Module überhaupt
gestapelt werden, Steckerlänge, Gehäuse) liegt weit unter 53 — das
3,3-V-Budget ist an keiner realistischen Stapelgröße der limitierende
Faktor.

## Beleg 9 — Layout-Auflage: C12-Polarität (Aufgabe 5, Motormodul)

**Hintergrund.** Auf dem Muttern-Print (v1, `~/Dokumente/Espace_des_
Inventions/PecheAuxCanards`) lag der „+"-Aufdruck eines 220-µF-Elkos auf
GND statt auf der Versorgungsschiene — zwei Kondensatoren sind dadurch
explodiert (s. `docs/superpowers/specs` bzw. die Projekt-Historie dieses
Fundes). Der Fehler liegt in der KiCad-Quelle des Muttern-Projekts und ist
dort **nicht korrigiert** — diese Aufgabe übernimmt bewusst nur die
Bauteilwerte/die Verschaltungslogik von dort, nicht die Polarität
unbesehen.

**Prüfung für C12 (220 µF, `tools/sch/motormodul.py`).** Das
`Device:C_Polarized`-Symbol trägt Pin 1 wörtlich als „+" (eigene Prüfung der
KiCad-Quelle, `Device.kicad_sym`). Im Motormodul liegt Pin 1 auf `+24V`,
Pin 2 auf `GND` — geprüft sowohl über die Netzliste
(`kicad-cli sch export netlist`, Netz `+24V` enthält `(C12, 1)`) als auch
über eine eigene Testzusicherung (`tests/test_motormodul.py`: „C12 Pin 1
(\"+\") hängt an +24V" / „... NICHT an GND"). Kein weiterer polarisierter
Kondensator kommt in dieser Datei vor (C9/C10/C11/C13 sind unpolarisierte
Keramikkondensatoren, `Device:C`, ohne Vorzugsrichtung).

**Auflage für Aufgabe 7 (PCB-Layout Motormodul).** Der Schaltplan legt die
elektrische Polarität fest, **nicht** aber, ob der spätere Footprint-Silk-
Aufdruck auf der Platine tatsächlich mit Pin 1 übereinstimmt — genau diese
Lücke hat den Muttern-Print-Fehler verursacht (dort war vermutlich nicht die
Schaltplan-Polung falsch, sondern der Footprint/Silk-Aufdruck gegenüber dem
Pad-1-Anschluss verdreht oder das Bauteil beim Bestücken falsch orientiert).
Aufgabe 7 muss deshalb **vor dem Fertigungsauftrag** explizit prüfen: liegt
das Pad, das Pin 1 (`+24V`) trägt, tatsächlich unter dem „+"-Silk-Symbol des
gewählten `CP_Radial_D8.0mm_P3.50mm`-Footprints? Eine reine
Netzlisten-/ERC-Prüfung sieht das nicht (beide Pads sind für die
Konnektivität gleichwertig, nur die Bauteil-Geometrie kennt den
Polaritäts-Silk) — das ist eine manuelle oder skriptgestützte
Footprint-Geometrie-Prüfung (z. B. `tools/pcb/pcb_checks.py`, das laut
Aufgabe-7-Brief ohnehin auf „verpolte Elkos" prüft), keine, die der
Schaltplan selbst erzwingen kann.

## Beleg 10 — Notaus-Verriegelung: die Pegel, nicht nur die Bauteile (Aufgabe-5-Fix-1, 2026-08-31)

**Der Befund.** Die erste Fassung des Motormoduls verriegelte `NOTAUS` →
`nSLEEP` mit einer Diode (D2) und einem Vorwiderstand (R14, 1 kΩ) vor dem
MCU-Vorwiderstand R9 (100 Ω). Der Kommentar dazu rechnete den *Fehlstrom*
aus ((3,3 − 0,6)/1100 ≈ 2,4 mA, unbedenklich für den GPIO) — aber nicht die
*Spannung* am Pin. R9 und R14 bilden einen Spannungsteiler:

    U(nSLEEP) = 0,6 V + 2,4 mA × 1 kΩ ≈ 3,05 V

V_IL des DRV8876-nSLEEP-Eingangs ist 0,8 V (SLVSDS7B, Abschnitt 6.5,
Block „LOGIC-LEVEL INPUTS", Zeile V_VM ≥ 5 V). Der Pin blieb also nicht nur
über V_IL, sondern sogar über V_IH (1,5 V): **die Verriegelung wirkte
nicht.** Genau in dem Fall, für den sie gebaut war — hängender MCU, GPIO
aktiv auf HIGH eingefroren — wäre der Motor angeblieben.

**Der zweite, unabhängige Grund.** Auch ohne R14 hätte die Klemme die
Schwelle verfehlt. Die Sammelleitung `NOTAUS` geht nämlich nicht auf 0 V:
sie wird über D3/D4 gegen den potentialfreien Schaltkontakt
heruntergezogen und liegt damit selbst **eine Durchlassspannung** über
Masse. Eine zweite Diode vom nSLEEP-Pin auf diesen Bus addiert die nächste:

    U(nSLEEP) = V_F(D3) + V_F(D2) ≈ 1,0 … 1,3 V   (1N4148W)   > 0,8 V

Selbst mit **Schottky-Dioden auf beiden Wegen** blieben im Grenzfall
2 × 400 mV = 0,8 V übrig — exakt die Schwelle, null Reserve. Eine passive
Dioden-UND-Verknüpfung kann diese Schwelle in dieser Topologie nicht
sicher einhalten.

**Die Lösung: ein UND-Gatter.** `U1_NSLEEP = NSLEEP(MCU) ∧ NOTAUS`, gebildet
von U3 (`SN74LVC1G08`, C7832 — dasselbe Bauteil wie U103, keine neue
Bauteilnummer) plus Abblockkondensator C14. D2 und R14 entfallen. Der
Gatterausgang ist eine Gegentaktstufe, deshalb sind die Pegel garantiert
statt gerechnet (SCES217AA, Abschnitt 5.5, jeweils bei 100 µA Laststrom):

| Fall | U an U1 Pin 3 | Schwelle (SLVSDS7B 6.5) | Reserve |
|---|---|---|---|
| NOTAUS gezogen | ≤ V_OL = **0,10 V** | V_IL = 0,8 V | 0,70 V |
| Normalbetrieb | ≥ V_OH = **3,15 V** | V_IH = 1,5 V | 1,65 V |

Die V_OL/V_OH-Werte gelten bis 100 µA Laststrom; der interne Pulldown des
nSLEEP-Pins (R_PD = 100 kΩ, SLVSDS7B 6.5) zieht bei 3,15 V nur 32 µA — die
Bedingung ist eingehalten. Fällt die 3,3-V-Schiene aus, geht der
Gatterausgang mit und derselbe Pulldown legt den Treiber schlafen: die
Ausfallrichtung ist die sichere.

**Nebenwirkung, die das Ursprungsanliegen erledigt.** R14 war eingefügt
worden, um den MCU-GPIO zu schützen (ohne ihn hätte die Diodenklemme über
R9 = 100 Ω rund 27 mA gezogen). Ein CMOS-Gattereingang zieht I_I ≤ ±5 µA
(SCES217AA 5.5) — das Schutzanliegen ist ohne Widerstand erledigt, und
ohne die Wirkung zu verhindern. R9 bleibt bei 100 Ω und ist jetzt ein
reiner Serien-/ESD-Widerstand (0,5 mV Abfall).

**Warum D3/D4 jetzt Schottky sind.** Der gezogene Ruhepegel des Busses *ist*
die Durchlassspannung dieser Dioden, und alles, was am Bus hängt — das
Gatter hier (V_IL = 0,8 V), der Pico auf der Sockelplatine, künftige
Module — muss diesen Pegel als LOW lesen. Für den Auslegungsfall aus
Beleg 8 (zehn Module, jedes mit R15 = 10 kΩ gegen 3,3 V):

    I(Bus) = 10 × (3,3 V − 0,4 V) / 10 kΩ ≈ 2,9 mA
    V_F(BAT54W) ≤ 400 mV   (Vishay 86408, MAX-Wert schon bei 10 mA)
    Reserve gegen V_IL = 0,8 V:  ≥ 0,4 V

Mit einem 1N4148W läge derselbe Pegel bei rund 0,6–0,65 V, und das
Datenblatt nennt für diese kleinen Ströme **überhaupt keinen MAX-Wert** —
für eine Sicherheitsfunktion nicht nachweisbar genug. Der BAT54W sitzt in
derselben Bauform (SOD-123); der Footprint bleibt unverändert.

**R15 bleibt bei 10 kΩ** und wird bewusst *nicht* vergrößert: bei zehn
Modulen parallel ergibt das 1 kΩ Bus-Pullup, und die Leckströme aller
Koppeldioden (I_R ≤ 2 µA, Vishay 86408) und Gattereingänge (≤ 5 µA) heben
den Ruhepegel um weniger als 0,1 V an — der Bus bleibt sicher über
V_IH = 2,0 V. Ein sehr viel hochohmigerer Pullup würde genau das kippen.

**Testabdeckung.** `tests/test_motormodul.py` prüft seit dieser
Nachbesserung nicht mehr die Anwesenheit der Diode, sondern die **Pegel**:
alle Größen (R9, R15, V_IL/V_IH des Treibers, V_OL/V_OH/V_IL/V_IH/I_I des
Gatters, V_F/I_R der Schottky-Diode) liegen als benannte Konstanten in
`tools/sch/motormodul.py`, jede mit Dokumentnummer und Abschnitt. Der Test
rechnet damit den Pegel am nSLEEP-Pin aus — **hergeleitet aus dem, was
laut Schaltplan auf dem Netz `U1_NSLEEP` hängt** — und enthält drei
Gegenproben, die zeigen, dass die alte Klemme, die Klemme ohne R14 und
sogar die reine Schottky-Variante die Schwelle verfehlen.

**Offener Punkt für Aufgabe 7 (PCB-Layout).** `NOTAUS_1`/`NOTAUS_2` haben
keinen eigenen Pullup; sie hängen am internen Pullup des Modul-MCU, den
erst die Firmware einschaltet. Für die *Sicherheitsfunktion* ist das
folgenlos (der Schaltkontakt zieht den Bus über D3/D4 unabhängig davon
herunter), für die *Kanaldiagnose* aber schon: vor dem ersten
Firmware-Lauf und bei hohen Temperaturen (Schottky-Leckstrom gegen einen
~40-kΩ-Pullup) ist der gelesene Pegel nicht garantiert. Wenn die
Kanaldiagnose verlässlich sein soll, gehören zwei 10-kΩ-Pullups dazu —
bewusst nicht in dieser Nachbesserung ergänzt, weil sie am Auftrag
(Verriegelung) vorbeigeht.

> **Nachtrag 2026-08-31 (Aufgabe 5d): dieser offene Punkt ist erledigt.**
> Die zwei Kanalknoten heissen jetzt `SCHLEIFE_1`/`SCHLEIFE_2` und tragen je
> einen echten 4,7-kΩ-**Pulldown** (R20/R21). Ihr Pegel ist damit zu jeder
> Zeit definiert — auch vor dem ersten Firmware-Lauf und unabhängig davon,
> was die Firmware an den MCU-Pins einstellt. Kein Zusatzbauteil nötig: der
> Pulldown ist ohnehin Teil des Ruhestrom-Eingangs (Beleg 11).

## Beleg 11 — Notaus-Eingang auf Ruhestromprinzip umgebaut (Aufgabe 5d, 2026-08-31)

**Der Befund.** Bis hierher war der externe Notaus-Kontakt ein **Schliesser**:
J3 Pin 1 bzw. 3 lag über einen potentialfreien Kontakt an GND, Schliessen hiess
Notaus. Ein Kabelbruch, ein abgezogener Stecker oder eine lose Klemme sehen
damit aus wie „alles in Ordnung" — die Schutzfunktion verschwindet still. Das
kam unverändert aus dem Altprojekt und stand als Bedenken 4 im
Aufgabe-5-Fix-1-Bericht. Entscheidung des Auftraggebers: Umbau auf
**Ruhestromprinzip (Öffner)**.

**Was jetzt gilt.** Der Kontakt ist im Normalbetrieb geschlossen. Öffnen löst
aus — und ebenso jeder Kabelbruch, jeder abgezogene Stecker, jede lose Klemme.

```
+24V --R16(3k3,1206)-- J3.1 ==ÖFFNER== J3.2 --R18(3k3,1206)-- U4-LED -- GND

3V3 --U4 Kollektor ... U4 Emitter --+-- SCHLEIFE_1 --> U100 Pin 3 (Diagnose)
                                    |               \
                                  R20 (4k7)          `-> U6 (Open-Drain) --> NOTAUS
                                    |
                                   GND
```

Kanal 2 ist Bauteil für Bauteil identisch (R17/R19/U5/R21/U7, J3 Pin 3+4,
U100 Pin 14).

**Warum 24 V nach draussen und nicht 3,3 V.** Museumskabel sind lang und liegen
neben Motor- und Netzleitungen. Ein 3,3-V-Signal auf eine hochohmige Last wird
von eingekoppelter Störspannung *und* von Kriechwegen (Feuchte, Staub in einer
Klemme) in beide Richtungen verfälscht. Hier fliesst stattdessen ein
definierter **Strom** von 3,0–3,9 mA; das ist zugleich ein brauchbarer
Benetzungsstrom für einen mechanischen Kontakt. Die Rückwandlung macht ein
Optokoppler, kein Spannungsteiler: kein Feldpotential erreicht die Logik. (Eine
echte galvanische Trennung ist es **nicht** — LED-Kathode und Logik liegen auf
derselben Masse; der Gewinn ist die Entkopplung des Signalwegs.)

**Pegelnachweis.** Bindende Schwellen: der Inverter-Eingang U6/U7
(SCES295AB 5.3, V_CC = 3–3,6 V) mit V_IH ≥ 2,0 V und V_IL ≤ 0,8 V; er ist
Schmitt-Trigger und verträgt die trägen Optokopplerflanken (t_r/t_f MAX 18 µs,
D2-A03101EN).

| Zustand | Rechnung | Ergebnis | Schwelle | Reserve |
|---|---|---|---|---|
| Schleife zu, schlechtester Fall | I_F = (21,6 − 1,4)/(2 × 3,3 kΩ × 1,01) | **3,03 mA** → nötiges CTR = (2,0 V / 4,7 kΩ)/3,03 mA = **14 %** | garantiert **≥ 50 %** (I_C ≥ 2,5 mA bei I_F = 5 mA, D2-A03101EN) | Faktor **3,6** |
| Schleife offen (Kabelbruch) | (I_CEO 100 nA + I_I 1 µA) × 4,7 kΩ | **5,2 mV** | V_IL = 0,8 V | **0,79 V** |
| Bus gezogen | 10 Module × (3,3 − 0,4)/10 kΩ = 2,9 mA → V_OL | **≤ 0,40 V** (MAX bei 16 mA / V_CC = 3 V, SCES295AB 5.5) | V_IL(U3) = 0,8 V | **0,40 V** |
| Bus in Ruhe | 10 × (2 × I_off 10 µA + I_I 5 µA) = 250 µA an 1 kΩ | **3,05 V** | V_IH(U3) = 2,0 V | **1,05 V** |

Der gezogene Buspegel ist damit **zahlengleich** mit der bisherigen
Schottky-Rechnung aus Beleg 10 — an der Verriegelung (U3, R9, R15,
`U1_NSLEEP`) ist deshalb **kein Bauteil und keine Zahl geändert**.

*Ehrlicher Vermerk zum CTR:* der Arbeitspunkt liegt bei 3,0–3,9 mA, nicht bei
den 5 mA der garantierten Datenblattzeile; für 3 mA nennt SHARP nur eine
Kennlinie, keinen MIN-Wert. Der Sicherheitsschluss hängt nicht daran: reicht
der Strom nicht, bleibt der Knoten unter V_IH, der Kanal meldet „offen", die
Anlage steht. **Ein CTR-Mangel kann kein falsches „in Ordnung" erzeugen** — er
kostet Verfügbarkeit, nie Sicherheit. Das beschaffte PC817X**1** trägt zudem
Rangmarke A (CTR ≥ 80 %).

**Warum die Koppeldioden D3/D4 entfallen mussten.** Die naheliegende Annahme
war, ein lokaler Pulldown ziehe den Kanalknoten LOW und die vorhandene Diode
ziehe die Sammelleitung mit. Das geht nicht:

```
Pulldown 4,7 kΩ gegen den auf 1 kΩ parallelgeschalteten Buspullup:
U(Bus) = 3,3 V × 4,7/(1 + 4,7) = 2,72 V   -- der Bus rührt sich nicht.
```

Ein Pulldown müsste (mit der Diode im Weg) unter **160 Ω** liegen, um den Bus
unter 0,8 V zu ziehen — und einen 160-Ω-Pulldown könnte kein Optokoppler mehr
auf V_IH heben (12,5 mA Fotostrom, mehr als der ganze Schleifenstrom). Der
bisherige Knoten wurde eben nicht von einem Widerstand, sondern von einem
**Schaltkontakt** (≈ 0 Ω) gezogen. Das Ruhestromprinzip verlangt, dass die
*Abwesenheit* von Strom eine *aktive* Handlung auslöst — das kann kein passives
Bauteil. Deshalb der Open-Drain-Inverter. Und eine Diode **in Reihe** dazu wäre
das Gegenteil einer Verbesserung: 0,4 V (V_OL) + 0,4 V (V_F) = 0,8 V, also
exakt die Schwelle, **null Reserve**.

**Kurzschluss der Rückleitung nach GND.** Die LED ist überbrückt, I_F = 0, der
Knoten fällt auf 5,2 mV, der Bus wird gezogen, der Treiber schläft — die sichere
Richtung. Gleiches gilt für die Hinleitung gegen GND.

**Strombegrenzung nach aussen.** Jede der vier Adern liegt hinter mindestens
3,3 kΩ:

```
I_max = 26,4 V / 3,3 kΩ   = 8,0 mA     (26,4 V = 24 V + 10 %)
P_max = 26,4 V^2 / 3,3 kΩ = 0,211 W    (84 % von 250 mW)
Normalbetrieb             = 0,049 W    (20 %)
```

**Deshalb 1206 und nicht 0805:** ein 0805 (125 mW) wäre im Kurzschluss um 70 %
überlastet. Beide Widerstände eines Kanals sind absichtlich gleich gross — dann
bleibt der Kurzschluss einer beliebigen Ader gegen GND **oder** gegen +24 V in
jedem Fall unter 8,0 mA und unter der Nennleistung, und der LED-Strom bleibt
weit unter den 50 mA Grenzstrom des PC817. *Vermerk:* die 84 % gelten bis 70 °C
Umgebungstemperatur; ein Dauerkurzschluss in einem heissen Gehäuse müsste
derated werden.

**Querschluss zwischen den Kanälen — was dann noch bleibt.** Ehrlich: hier
verliert die Zweikanaligkeit einen Teil ihres Sinns (A = Hinleitung,
B = Rückleitung). A1–A2 ist folgenlos. **B1–B2** koppelt die zwei LED-Zweige:
ist *ein* Kontakt offen und der andere geschlossen, speist der geschlossene
beide LEDs, der offene Kanal ist **blind** — öffnen beide Kontakte (der
Normalfall bei einem Not-Halt-Taster), fällt der Strom trotzdem auf null.
A1–B1 bzw. A2–B2 überbrückt den Kontakt des eigenen Kanals (das ist zugleich
die *absichtliche* Brücke für einen unbenutzten Kanal — die Schaltung kann
Absicht und Fehler nicht unterscheiden). Über Kreuz (A1–B2, A2–B1) sowie eine
Rückleitung an +24 V machen ebenfalls je einen Kanal blind. **Es bleibt: ein
Querschluss macht höchstens einen Kanal blind, der zweite löst weiter aus; für
einen Durchlauf braucht es zwei Fehler.** Was fehlt: die Schaltung **erkennt**
den Querschluss nicht — dafür bräuchte es getaktete Prüfimpulse (OSSD) oder ein
Sicherheitsrelais. Beide Kanäle hängen aber einzeln am Modul-MCU; eine
**Diskrepanzüberwachung in der Firmware** (zwei Kanäle melden länger als ein
paar hundert Millisekunden Verschiedenes → sperren) ist damit möglich und ist
hiermit als Firmware-Auftrag festgehalten. Verlege-Auflage fürs Museum: die
zwei Kreise gehören in **getrennt geführte Leitungen**, nicht in zwei Adern
desselben Mantels.

**Ein schmaler Rückschritt, ehrlich benannt.** Der Schaltkontakt zog den Bus
früher rein *passiv* herunter, auch ohne lokale 3,3 V. Jetzt braucht der
Koppelweg die 3,3-V-Schiene dieses Moduls. Stapelweiter 3V3-Ausfall ist
folgenlos (U3 stirbt mit, der interne 100-kΩ-Pulldown des DRV8876 legt den
Treiber schlafen). Fällt 3V3 **nur auf diesem Modul** aus — gebrochener
3V3-Pin am Stapelstecker —, schläft zwar dieses Modul, aber der an ihm
angeschlossene Not-Halt erreicht die übrigen Module nicht mehr. Nicht
vermeidbar: Ruhestrom verlangt einen gespeisten Treiber.

### Auflage 1 — der unbenutzte Kanal MUSS gebrückt werden

Wird nur ein Notaus-Kreis angeschlossen, hängt der zweite Kanal offen und
meldet **dauerhaft Notaus**; die Anlage läuft nicht an. Richtige Vorgabe
(offen = sicher), aber der Nutzer muss wissen, was zu tun ist:

> **Unbenutzten Kanal am Stecker brücken:
> Kanal 1 = J3 Pin 1+2, Kanal 2 = J3 Pin 3+4.**

J3 ist eine 2,54-mm-Stiftleiste; die zwei Pins eines Kanals liegen deshalb
absichtlich **nebeneinander** — eine handelsübliche Jumper-Brücke genügt. Der
Hinweis steht als Text im Schaltplan neben J3. **Aufgabe 7 (PCB-Layout) muss
ihn zusätzlich auf den Siebdruck neben J3 setzen**, zusammen mit der
Kanalzuordnung der vier Pins.

### Auflage 2 — die Verkabelung des Pêche-aux-Canards-Exponats MUSS umgeklemmt werden

**J3 bleibt vierpolig** (zwei Adern je Kanal statt Signal+GND). Gleiche
Bauform, gleiche Polzahl, völlig andere Bedeutung: **ein altes Kabel passt
mechanisch weiterhin.** Steckt man es, liegt der alte Schliesser zwischen
Pin 1 und Pin 2, also im Weg von Kanal 1; im Ruhezustand ist er offen → der
Kanal meldet Notaus, Kanal 2 hängt ohnehin offen. **Das Exponat stünde nach
dem Modultausch dauerhaft auf Notaus.** Sicher, aber unbrauchbar. Beim
Umstieg ist deshalb zwingend umzuklemmen:

- Not-Halt-Taster mit **Öffnerkontakt** verwenden (nicht Schliesser),
- je Kanal **zwei Adern** zum Taster führen (nicht Signal + Masse),
- Kanal 1 an J3 Pin 1+2, Kanal 2 an J3 Pin 3+4,
- wird nur ein Kreis verdrahtet, den anderen brücken (Auflage 1).

Empfehlung für Aufgabe 7/9, nicht ausgeführt: J3 **codieren oder auf einen
anderen Steckertyp wechseln**, damit ein altes Kabel gar nicht mehr passt —
und für ein Feld-Sicherheitssignal wäre eine Schraubklemme mit Zugentlastung
ohnehin die bessere Bauform als eine 2,54-mm-Stiftleiste.

## Beleg 12 — Layout-Auflage: der Optokoppler-Footprint stimmt nicht (Aufgabe 5d)

Beim Nachtragen des PC817 in die Bauteiltabelle ist aufgefallen, dass der seit
dem Altprojekt eingetragene Footprint nicht zum Bauteil passt — und zwar schon
für das geerbte U2, nicht erst für die neuen U4/U5.

`Package_SO:SOP-4_3.8x4.1mm_P2.54mm` (KiCad-Standardbibliothek) beschreibt ein
Gehäuse von 3,8 × 4,1 mm mit Pad-Mitten bei ±2,75 mm. Der PC817 in
SMT-Gullwing-Bauform misst laut SHARP D2-A03101EN, Abschnitt „Outline
Dimensions", Variante „SMT Gullwing Lead-Form": Körper **6,5 × 4,58 mm**,
Anschlussspanne **10,0 mm**, Reihenabstand **7,62 mm**, Pitch 2,54 mm. Das
passt nicht — auch der grössere Nachbar `SOP-4_7.5x4.1mm_P2.54mm` (Pad-Mitten
±4,6875 mm) trifft es nicht genau.

Im Schaltplan ist das folgenlos (Repo-Praxis: Footprints sind Platzhalter, bis
Aufgabe 7 die echten zeichnet — dieselbe Lage wie bei den DB128L-Klemmen), aber
**Aufgabe 7 muss für U2/U4/U5 einen eigenen PC817-Footprint zeichnen**, bevor
bestückt wird. Zusammen mit der C12-Silkscreen-Prüfung (Beleg 9) und der
U3-Nähe-Auflage sind das jetzt drei Layout-Auflagen aus der Motormodul-Kette.

**Nebenbefund:** R6 (Vorwiderstand des Sensor-Optokopplers U2,
2,2 kΩ im 0805-Footprint) liegt an 24 V und verheizt bei leitendem Sensor
24²/2,2 kΩ ≈ **0,24 W** — fast das Doppelte dessen, was ein 0805 trägt. Genau
der Fehler, den Beleg 11 für die neuen Schleifenwiderstände bewusst vermeidet.
Aus dem Altprojekt geerbt, nicht Gegenstand dieser Aufgabe, gehört
nachgerechnet.

### Nachtrag 2026-09-01 (Aufgabe 5f) — beide Befunde behoben, und als Klasse geprüft

Beide oben offenen Punkte sind erledigt. Wichtiger als die zwei Einzelfälle:
`tests/test_motormodul.py` prüft sie jetzt als **Gattung**, und dabei ist ein
**dritter** Fehler derselben Art aufgefallen.

**(a) R6 — weggelassen statt vergrössert.** Die Rechnung bestätigt sich:
(24 V − 1,2 V)² / 2,2 kΩ = **0,236 W** gegen **0,125 W** Belastbarkeit
(belegt: UNI-ROYAL 0805W8F1002T5E, LCSC **C17414**, Produktseite gesichtet —
„125mW“, „150V“). Ein grösserer Widerstand wäre die falsche Antwort gewesen:
der Sensoreingang wird gar nicht gebraucht. Zwei Belege, beide selbst gelesen:

* Altprojekt `PecheAuxCanards`, `README.md` und `firmware/pico_config.py`:
  „Die Eingänge des Boards (GPIO16 Sensor via PC817 …) sind in diesem Projekt
  **unbenutzt** — es sind keine Sensoren angeschlossen oder geplant.“
* `docs/superpowers/specs/2026-08-28-picostack-design.md`, Tabelle
  „Leistungsstufe“: Modultyp Motor = „DRV8876, ein Motor, Strommessung,
  Notaus-Eingänge“ — **kein Sensor**.

**Entfallen:** J2 (3-polige Klemme), R6, U2 und die Netze `SENSOR24V`,
`U2_LED_A`, `SENSOR_3V3`. Frei geworden: **U100 Pin 2 (PC14)** als GPIO und
die 3-polige Klemme aus der Stückliste. Das weicht bewusst von Aufgabe 5,
Schritt 1 ab (dort stand „U2 … mit R6“ als zu übernehmen).
Wer den Eingang später doch braucht: ein 0805 bräuchte an dieser Schiene
> 5,1 kΩ ((26,4 − 1,2)²/0,125 W), sinnvoller ist 1206 wie R16–R19.

**(b) Optokoppler-Footprint — gezeichnet.** Aus derselben Quelle, aber aus dem
Abschnitt, den Beleg 12 oben noch nicht ausgewertet hatte: SHARP
**D2-A03101EN**, „Design Considerations“ → **„Recommended Foot Print
(reference)“**, Zeile **„SMT Gullwing Lead-form“** — Reihenabstand **8,2 mm**
(Pad-Mitte zu Pad-Mitte), Pad **2,2 × 1,7 mm**, Raster **2,54 mm**. Genau das
liegt jetzt als
`hardware/kicad/components/footprints/Optocoupler_PC817.pretty/PC817_SMT_Gullwing.kicad_mod`
im Projekt (Eintrag in `hardware/kicad/motor/fp-lib-table`).
**Gegenprobe an einer zweiten Quelle:** die Landfläche, die LCSC/EasyEDA selbst
für C97308 führt, heisst `OPTO-SMD-4_L4.6-W6.5-P2.54-LS10.3-TL` mit Pads bei
±4,3 mm, 2,5 × 1,5 mm — das bestätigt die **normale** (nicht die „wide“)
Gullwing-Form und den Reihenabstand auf 0,4 mm genau. In der
KiCad-Standardbibliothek gibt es keinen passenden: `SOP-4_7.5x4.1mm_P2.54mm`
hat nur 0,65 mm breite Pads, `SMDIP-4_W9.53mm` liegt 1,33 mm daneben.

**(c) Der dritte Fall, den erst die Gattungsprüfung fand: Q1 gab es in seinem
Footprint nicht.** `Q1` trug den Wert „IRF4905“ im Footprint
`Package_TO_SOT_SMD:TO-252-3_TabPin2`. **Den IRF4905 gibt es nicht in
TO-252** — bei LCSC nur TO-220 (C2564 Infineon, C18207551 UMW) und
TO-263/D2Pak (C5337969, IRF4905S), alle drei Produktseiten gesichtet. Wert und
Footprint widersprachen sich; JLCPCB hätte ein anderes Bauteil bestückt oder
den Platz leer gelassen — beim Verpolungsschutz, der den ganzen Motorstrom
führt. Ersetzt durch **IRFR5305PbF, D-Pak (TO-252AA), LCSC C2624** (neue
Bauteilzeile oben). Nachgerechnet: 55 V gegen 26,4 V Schiene und gegen die
Klemmspannung der TVS D1 (48,4 V max); V_GS = −13,2 V (R11/R12 gleich groß),
unter ±20 V und über der Schwelle −4,0 V; 0,065 Ω × (2,5 A)² = 0,41 W gegen
„up to 1.5 watts … in typical surface mount applications“ (PD-95025A).

**Warum (c) der teuerste der drei gewesen wäre:** eine heisse Bauform und ein
danebenliegender Footprint fallen beim ersten Aufbau auf. Ein
Wert-Footprint-Widerspruch fällt **gar nicht** auf: die Platine kommt bestückt
zurück, sieht richtig aus, und der Verpolungsschutz ist ein anderer Transistor
als geplant.

**Was jetzt die Klasse abdeckt** (beides in `tests/test_motormodul.py`, beides
mit Rot-Nachweis in einer Wegwerfkopie):

1. **Verlustleistung.** Für **jeden** Widerstand wird aus dem Schaltplan
   hergeleitet, welche Spannung an ihm stehen kann (Schienen gesetzt;
   Feldstecker dürfen im Fehlerfall alles zwischen 0 V und der 24-V-Schiene
   führen; Bausteine halten ihre Netze innerhalb der Schienen, an denen sie
   selbst hängen; Fortpflanzung über leitende Bauteile bis zum Fixpunkt) und
   gegen die Belastbarkeit seiner Bauform gestellt. 20 Widerstände, 6 davon
   über 5 V: R11/R12 mit 0,070 W von 0,125 W, R16–R19 mit 0,213 W von
   0,250 W. Was sich nicht herleiten lässt (R100/R101 tragen im Schaltplan
   keinen Zahlenwert), verlangt eine **belegte Handrechnung** und wird
   ausgedruckt — nicht stillschweigend übersprungen.
2. **Footprint gegen Gehäuse.** Für **jedes** Bauteil: Bibliothek auflösen,
   Datei öffnen, Pad-Nummern gegen Symbol-Pins, Gehäuse des gewählten Teils
   aus einer belegten Tabelle (geschlüsselt nach dem **Wert** — deshalb fiel
   Q1 auf), Rastermass nachmessen und prüfen, ob die **Anschlussspanne**
   überhaupt auf Pads trifft. 35 Bauteile geometrisch nachgemessen, 14 nur
   nach Polzahl und Bauformnamen — die 14 werden bei jedem Lauf namentlich
   ausgedruckt (u. a. Q1, U1, U100: ihre Massbilder liegen als Grafik im PDF).

**Was offen bleibt:** die Klemmen-Footprints sind weiterhin
Phoenix-Platzhalter mit richtigem Raster und richtiger Polzahl, aber falschem
Körper (Auflage an Aufgabe 7, von der Prüfung nicht erfassbar); die
Leistungsprüfung rechnet ohne Derating über 70 °C; Kondensatorspannungen und
Diodenströme sind nicht Gegenstand der Prüfung.

## Beleg 13 — Ketten- und Leistungsstecker: SMD-Paare statt bedrahteter Paare (Aufgabe 5e, 2026-08-31)

**Der Fehler.** Beide Stecker waren Paare aus Buchse oben (J101/J103) und
Stiftleiste unten (J102/J104), beide **bedrahtet**, beide an derselben Stelle.
An derselben Stelle *müssen* sie sitzen: alle Platinen des Stapels sind gleich,
und eine Verschiebung hebt sich zwischen zwei gleichen Platinen nicht auf, sie
summiert sich — der Stift an der Unterseite von Modul N trifft die Buchse an der
Oberseite von Modul N+1 nur bei identischer (x|y). Zwei bedrahtete Bauteile
können sich aber keine Bohrungen teilen. Der 2×20 hat das am 31.08. gelöst,
indem er ein echter Stapelstecker mit durchgehendem Stift wurde (Beleg 6); bei
den beiden kleinen Steckern blieb der Fehler stehen.

### 13.1 Warum die Kette kein durchgehender Stift sein darf

Nachgerechnet, nicht angenommen. Bei durchgehenden Kontakten ist Kontakt *k*
**ein** Netz über den ganzen Stapel. Alle Module sind gleich gebaut, verbinden
also denselben Modulknoten mit demselben Kontakt. Läge `SEL_OUT` auf Kontakt *a*
und `SEL_IN` auf Kontakt *b*, verlangte die Kette `SEL_OUT(n) = SEL_IN(n+1)` für
**jedes** *n* — erfüllbar nur, wenn Netz(*a*) = Netz(*b*). Dann liegen alle
`SEL_IN` und alle `SEL_OUT` des Stapels auf einem Knoten: D und Q jedes
Flipflops kurzgeschlossen, das Schieberegister aus `tools/kette.py` wirkungslos.
**Die Rechnung hängt nicht an der Kontaktzahl** — auch zwei oder zwanzig
Kontakte des vorhandenen 2×20 können die Kette nicht tragen.

Zwei bedrahtete Hälften am selben Ort brauchten dieselben Bohrungen, und dieselbe
Bohrung *ist* ein durchgehender Kontakt. Die Mischung THT/SMD geht ebenfalls
nicht: die Bohrungen der bedrahteten Hälfte liegen genau dort, wo die Kontakte
der SMD-Hälfte auf der Gegenseite liegen müssten. Es bleibt: **beide Hälften
oberflächenmontiert.**

### 13.2 Einen 2×2-Stapelstecker gibt es bei LCSC nicht

Für den Leistungsstecker wäre ein durchgehender Stift **erlaubt** (beide Hälften
führen Pin für Pin `PWR24V`/`GND`). Gesucht bei LCSC und in der
JLCPCB-Bestückungsbibliothek. Auf Produktseiten tatsächlich gesehen:

| LCSC | Hersteller/Teil | Befund |
|---|---|---|
| `C35165` | BOOMELE „2.54-2*20PPC104" | Stapelstecker, **2×20**; Attribute: „Through Hole", „Current Rating: 3A", „Insulation Height: 8.3mm", „PIN Length: 12.3mm" (Zeichnung: 8,5 / 12,46 mm, s. Beleg 1) |
| `C5307344` | ZHOURI „PC104-2*20" | Stapelstecker, **2×20**; „Current Rating: 2.5A", „Insulation Height: 10.5mm", „PIN Length: 12.2mm" |
| `C5307345` | ZHOURI „PC104-2*40" | Stapelstecker, **2×40** |
| `C72555` | BOOMELE „2.54-2*8P3.8" | „Female header 2*8P pitch 2.54mm **Heightened, Pins are long 3.8mm**", 2×8 |
| `C5307342` / `C5307343` / `C5307346` | ZHOURI PM2.54-2*6 / PM2.54-2*16 / PM2.0-1*10 | die Nachbarnummern derselben Reihe: **gewöhnliche** Buchsen, Lötstift 2,8–3,2 mm |

**Kleinere Polzahlen als 2×20 gibt es in dieser Bauform nicht.** Das
nächstliegende „langbeinige" Teil (`C72555`) überbrückt den Spalt nicht einmal:
M = 3,8 − 1,6 = 2,2 mm, M + F = 2,2 + 8,5 = **10,7 mm < G = 11,4 mm**.

### 13.3 Die Leistung über den vorhandenen 2×20 zu führen, geht auch nicht

Dort ist **kein Kontakt frei**: alle 40 tragen Pico-Pins (`PIN_ROLLE`), und die
Sockelplatine verbindet sie mit dem Pico — 24 V auf einem davon zerstört ihn.
Elektrisch tot sind allein Kontakt 30 (`RUN`) und 35 (`ADC_VREF`), die kein
Modul anfassen darf. Das wäre **ein** Pfad für 24 V mit 3 A (`C35165`):

* **unter dem Bedarf** — der DRV8876 zieht über 2,5 A (Beleg 4 / SLVSDS7B), und
  der Stapelstrom ist die Summe aller Module darunter;
* **im 2,54-mm-Raster direkt neben 3,3-V-GPIO** (Kontakt 29 = GP22, 31 = GP26);
* gegen die ausdrückliche Design-Doc-Vorgabe, Motorströme vom Signalstecker
  getrennt zu führen.
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

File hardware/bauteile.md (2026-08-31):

# Bauteilwahl: Modul-MCU, Bootlader-Pins, Reset-Zustand

**Stand:** 2026-08-28. Bestand und Preise bei LCSC/JLCPCB ändern sich
laufend; die hier genannten Zahlen sind Stichproben vom Recherchezeitpunkt,
keine Garantie.

## Bauteiltabelle

| Zweck | Typ | Bauform | LCSC | geprüft | Quelle |
|---|---|---|---|---|---|
| Modul-MCU | STM32C011F6P6 | TSSOP-20 | C5456198 | ja | JLCPCB-Produktseite `jlcpcb.com/partdetail/STMicroelectronics-STM32C011F6P6/C5456198` (Rohdaten: `componentLibraryType":"expand"`, `assemblyMode":"smtWeld"`, `moistureSensitivityLevelEn":"MSL 1"`); LCSC-Produktseite `lcsc.com/product-detail/C5456198.html` |
| Motortreiber | DRV8876PWPR | HTSSOP-16-EP | C575551 | ja | JLCPCB-Produktseite `jlcpcb.com/partdetail/TexasInstruments-DRV8876PWPR/C575551` (Rohdaten: `"Extended Part"`, `componentLibraryType":"expand"`); LCSC-API-Abfrage `wmsc.lcsc.com/ftps/wm/product/detail?productCode=C575551` |
| Motortreiber (Automotive-Grade, Alternative) | DRV8876QPWPRQ1 | HTSSOP-16-EP | C2860987 | ja | LCSC-API-Abfrage `wmsc.lcsc.com/ftps/wm/product/detail?productCode=C2860987`; nur 14 Stück Lagerbestand am Stichtag, deshalb nicht empfohlen |
| Leistungsstecker (Vorschlag, nicht festgelegt) | generischer 2,54-mm-Doppelreihen-Stiftverbinder | THT | — | nein | kein konkretes Bauteil im Vertrag festgelegt; Referenzwert 3 A/Kontakt aus Multicomp-Datenblatt (Farnell-Dok. 2585485, Abschnitt „Specifications", `Current Rating: 3A AC/DC`) — Beschreibung s. Absatz unten |
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

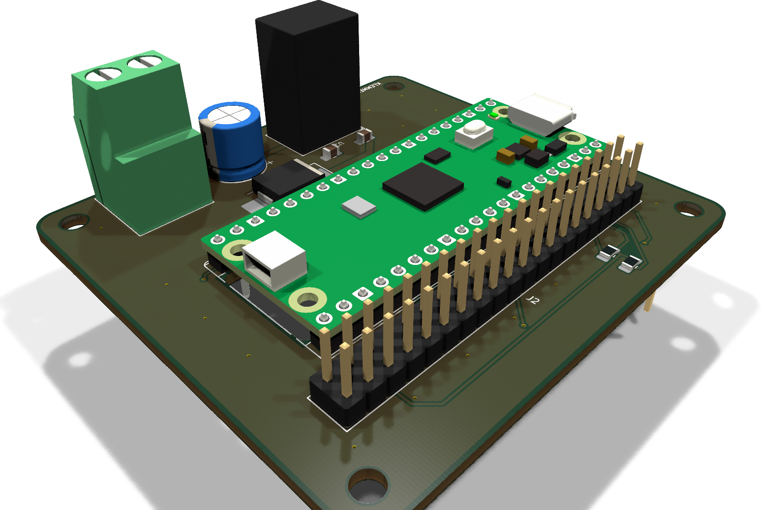
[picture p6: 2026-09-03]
docs/assets/sockel_iso.png

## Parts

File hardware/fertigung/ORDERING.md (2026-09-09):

# Ordering an assembled board at JLCPCB

Covers the four **v2** boards: **Motormodul** (motor), and the **Dimmer**
family (dimmer1, dimmer3, dimmer4 — 1/3/4 LED channels). Same steps for
each; screenshots below use Dimmer4, the largest of the four.

The v1 **Sockelplatine** is **not part of the v2 product line** anymore —
its role (Pico carrier + 24 V supply) is now built into every module as
the versorgung cell (J90/Q90/R90/R91/D90/C90/U90/C91/D91). Its files under
`hardware/fertigung/sockel/` are kept for archive purposes only; do not
order it as a v2 deliverable, and do not copy its steps below without
checking against a current v2 board first — some of what changed between
v1 and v2 (see the traps section) started life as a v1 mistake on this
exact board.

## Files you need (already in `hardware/fertigung/<board>/`)

| File | Used for |
|---|---|
| `<board>-gerber-jlc.zip` | the PCB itself (upload as-is) |
| `jlc-bom.csv` | parts list, JLC BOM format |
| `jlc-cpl.csv` | pick-and-place positions, JLC CPL format |
| `UNBESTUECKT.txt` | what you will solder / fit by hand, and why |

## Step by step

1. **jlcpcb.com → "Instant Quote"** and upload `<board>-gerber-jlc.zip`.
   JLC should detect the board outline (75 × 65 mm on all four v2 boards —
   grown from v1's 64 × 60 mm to fit the second stacking row, the per-board
   supply cell and the edge pads) and 2 layers. Keep the defaults (FR-4,
   1.6 mm, HASL, any colour, qty 5 — that is the minimum).
2. Toggle **"PCB Assembly"** on. Choose *Economic*, *Top side* — every
   populated part on all four boards sits on the top layer; nothing on
   the bottom is machine-placed (see "unpopulated by design" below).
   Assembly quantity 2 is usually enough for prototypes.
3. Upload `jlc-bom.csv` and `jlc-cpl.csv` when asked.
4. **Check the part matching page carefully.** Most BOM lines carry an
   LCSC part number that was verified against the actual LCSC product
   page (see the constants at the top of `tools/jlc.py` and the evidence
   trail in `hardware/bauteile*.md`) — those match automatically. The
   remaining lines (a few small parts with no verified number, e.g. the
   DRV8876 on the Motormodul, the Notaus pin header, the current-limit
   resistor position) are either matched by JLC from their description or
   deliberately left for you to source/solder — check `UNBESTUECKT.txt`
   and the BOM comment text for each blank LCSC field.
5. **Check the placement preview.** JLC's rotation convention differs
   from KiCad's for some packages — this project already applies a
   correction table in `tools/jlc.py` (`ROT_KORREKTUR`: SOT-353/363
   +180°, TSSOP +270°, VSSOP-8 +180°) and pad-centroid positions for the
   THT families (`tools/pcb/zentroide.py`: terminal blocks, the
   electrolytic, the DC/DC converter). Still **verify pin-1 / cathode
   orientation** in the render for U100 (MCU, TSSOP-20), U101–U103 and
   U6/U7 (SC-70/SOT, VSSOP), the diodes (D90 TVS, D91 and D1–D4
   Schottky), and both MOSFET families (Q90 IRFR5305, Q1–Q4 NCE6020AK on
   the dimmers) — this is the step that catches most assembly mistakes,
   and the correction table does not cover every footprint (TO-252 and
   the DO-214AB diodes are deliberately NOT in it, see the comment above
   `ROT_KORREKTUR`).
6. If JLC flags THT parts (C90 electrolytic, J5/J90/J6–J8 terminals) as
   not assemblable in Economic: deselect them and solder them yourself —
   they are the easiest parts on the board.
7. Order. The stack connectors (J100, J105, J101–J104) are **hand-fitted
   on purpose** (see `UNBESTUECKT.txt` and `stack_spec.MONTAGE_REGEL`):
   solder them in the mated stack so the contacts align without strain.
   J95/J96 (the edge-pad rows) are also unpopulated — see below.

## Unpopulated by design

Every v2 board carries two rows of bare solder pads along one edge —
`J95` (18 GPIO) and `J96` (2× 3V3 + 2× GND), `stack_spec.RANDPADS`. They
are **never meant to be assembled**: they exist so a finished module can
be probed or hand-wired to a free GPIO without opening the stack. Both
are SMD pads on the bottom copper layer (`B.Cu`) — this is new in v2 (v1
had no equivalent). Because they are always unpopulated, **the
bottom-layer change has no effect on `jlc-cpl.csv`**: nothing on the
bottom side of any v2 board is ever machine-placed (the only other
bottom-side footprints, J102/J104, were already hand-soldered stack
connectors before this change) — checked board by board against
`pos.csv`/`jlc-cpl.csv` while building this fabrication data, not
assumed.

The stack connectors (J100/J105 left/right Pico rows, J101–J104 chain and
power connectors) are likewise always in `UNBESTUECKT.txt`: they must be
soldered **in the mated stack**, after stacking, so the contacts align
without strain (`MONTAGE_REGEL`). J105 is new in v2 — v1 had a single
2×20 stacking header (`J100`); v2 splits it into two 1×20 sockets
(`J100` pins 1–20, `J105` pins 21–40).

## Traps that already cost real money in v1 — check these every time

- **JLC's placement-preview rotation check is not optional.** The
  correction table in `tools/jlc.py` fixes the *known* package families;
  it does not guarantee every footprint. A wrongly-rotated part that
  slips through the preview is a wrong assembly, not a wrong file.
- **SS36C (SMC / DO-214AB) is not SS36 (SMA).** The free-wheeling and
  VSYS diodes on every v2 board are **SS36C**, LCSC **C16237** — MDD's
  plain "SS36" (**C16015**) is the smaller SMA package and does not fit
  these pads. Confirm the footprint column reads `D_SMC`, not an SMA
  package, before accepting JLC's auto-match.
- **R100/R101 encode the module type — never "optimise" them to a
  common value.** They are read back by the module's own firmware at
  boot (`stack_spec.TYPCODE_WIDERSTAENDE`) to tell modules apart; a well
  -meaning BOM cleanup that merges "two identical-looking resistor rows"
  into one silently bricks the type detection. This is not theoretical:
  on **Dimmer3** (type code 0x11), R100 *and* R101 both resolve to the
  **same value, 680 Ω** (`TYPCODE_WIDERSTAENDE(0x11) == (680, 680)`) —
  two BOM rows, same value, same footprint, and still two electrically
  and semantically distinct designators that must stay on separate rows.
  Do not let anyone "simplify" that away because the values match.

## After the boards arrive

- Populate the connectors and any deselected THT parts.
- Flash the module MCU through the stack (or SWD for the first board).
- Please open an issue with photos — the first real-world build report
  is worth more than any simulation.

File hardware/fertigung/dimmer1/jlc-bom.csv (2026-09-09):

Comment | Designator | Footprint | LCSC Part #
100nF 50V X7R 0805 | C100,C102,C103,C104 | C_0805_2012Metric_Pad1.18x1.45mm_HandSolder | C49678
1uF 50V X7R 0805 | C101 | C_0805_2012Metric_Pad1.18x1.45mm_HandSolder | C28323
22uF 25V X5R 0805 | C91 | C_0805_2012Metric_Pad1.18x1.45mm_HandSolder | C45783
220uF 35V Elko radial D8 RM3.5 | C90 | CP_Radial_D8.0mm_P3.50mm | C45078
100kOhm 0805 1% | R102,RP1 | R_0805_2012Metric_Pad1.20x1.40mm_HandSolder | C149504
100Ohm 0805 1% | RG1 | R_0805_2012Metric_Pad1.20x1.40mm_HandSolder | C17408
10kOhm 0805 1% | R90,R91,R104,R105 | R_0805_2012Metric_Pad1.20x1.40mm_HandSolder | C17414
SMCJ30A TVS unidirektional DO-214AB | D90 | D_SMC | C340696
SS36C Schottky 60V 3A DO-214AB (SMC) | D91,D1 | D_SMC | C16237
IRFR5305 P-MOSFET -55V TO-252 | Q90 | TO-252-3_TabPin2 | C2624
NCE6020AK N-MOSFET 60V 20A TO-252 | Q1 | TO-252-3_TabPin2 | C108639
KF350-3.5-2P Klemme 3.5mm 2P 10A | J90,J5 | TerminalBlock_Phoenix_PT-1,5-2-3.5-H_1x02_P3.50mm_Horizontal | C474892
K7805-1000R3 DC/DC 5V 1A 6-30V SIP-3 | U90 | Converter_DCDC_RECOM_R-78B-2.0_THT | C909765
SN74LVC1G08DCKR AND SC-70-5 | U103 | SOT-353_SC-70-5 | C7832
SN74LVC1G175DCKR D-Flipflop SC-70-6 | U101 | SOT-363_SC-70-6 | C202238
SN74LVC2G00DCUR Dual-NAND VSSOP-8 | U102 | VSSOP-8_2.3x2mm_P0.5mm | C206109
STM32C011F6P6 MCU TSSOP-20 | U100 | TSSOP-20_4.4x6.5mm_P0.65mm | C5456198
0Ohm Bruecke 0805 (Kennwiderstand ID0) | R100 | R_0805_2012Metric_Pad1.20x1.40mm_HandSolder | C17477
680Ohm 0805 1% (Kennwiderstand ID1) | R101 | R_0805_2012Metric_Pad1.20x1.40mm_HandSolder | C17798

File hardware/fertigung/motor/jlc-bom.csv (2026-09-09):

Comment | Designator | Footprint | LCSC Part #
22nF 50V X7R 0805 | C10 | C_0805_2012Metric_Pad1.18x1.45mm_HandSolder
100nF 50V X7R 0805 | C9,C11,C13,C14,C15,C16,C17,C18,C19,C100 | C_0805_2012Metric_Pad1.18x1.45mm_HandSolder | C49678
1uF 50V X7R 0805 | C101 | C_0805_2012Metric_Pad1.18x1.45mm_HandSolder | C28323
22uF 25V X5R 0805 | C91 | C_0805_2012Metric_Pad1.18x1.45mm_HandSolder | C45783
100kOhm 0805 1% | R102 | R_0805_2012Metric_Pad1.20x1.40mm_HandSolder | C149504
220uF 35V Elko radial D8 RM3.5 | C90 | CP_Radial_D8.0mm_P3.50mm | C45078
SMCJ30A TVS unidirektional DO-214AB | D90 | D_SMC | C340696
SS36C Schottky 60V 3A DO-214AB (SMC) | D91 | D_SMC | C16237
DB128L-5.08-2P-GN-S Klemme 16A 300V | J5 | TerminalBlock_Phoenix_MKDS-3-2-5.08_1x02_P5.08mm_Horizontal | C395868
KF350-3.5-2P Klemme 3.5mm 2P 10A | J90 | TerminalBlock_Phoenix_PT-1,5-2-3.5-H_1x02_P3.50mm_Horizontal | C474892
Stiftleiste 1x04 2.54mm THT | J3 | PinHeader_1x04_P2.54mm_Vertical
IRFR5305 P-MOSFET -55V TO-252 | Q90 | TO-252-3_TabPin2 | C2624
100Ohm 0805 1% | R7,R8,R9 | R_0805_2012Metric_Pad1.20x1.40mm_HandSolder | C17408
1.3kOhm 0805 1% | R5 | R_0805_2012Metric_Pad1.20x1.40mm_HandSolder
3.3kOhm 1206 1% | R16,R17,R18,R19 | R_1206_3216Metric | C26032
4.7kOhm 0805 1% | R20,R21 | R_0805_2012Metric_Pad1.20x1.40mm_HandSolder | C17673
10kOhm 0805 1% | R13,R15,R90,R91,R104,R105 | R_0805_2012Metric_Pad1.20x1.40mm_HandSolder | C17414
K7805-1000R3 DC/DC 5V 1A 6-30V SIP-3 | U90 | Converter_DCDC_RECOM_R-78B-2.0_THT | C909765
DRV8876PWPR H-Bruecke HTSSOP-16 PowerPAD | U1 | IC_DRV8876PWPR
SN74LVC1G08DCKR AND SC-70-5 | U3,U103 | SOT-353_SC-70-5 | C7832
SN74LVC1G07DCKR Buffer OD SC-70-5 | U6,U7 | SOT-353_SC-70-5 | C7830
SN74LVC1G175DCKR D-Flipflop SC-70-6 | U101 | SOT-363_SC-70-6 | C202238
SN74LVC2G00DCUR Dual-NAND VSSOP-8 | U102 | VSSOP-8_2.3x2mm_P0.5mm | C206109
STM32C011F6P6 MCU TSSOP-20 | U100 | TSSOP-20_4.4x6.5mm_P0.65mm | C5456198
PC817 Optokoppler SMD Gullwing | U4,U5 | PC817_SMT_Gullwing | C97308
680Ohm 0805 1% (Kennwiderstand ID0) | R100 | R_0805_2012Metric_Pad1.20x1.40mm_HandSolder | C17798
0Ohm Bruecke 0805 (Kennwiderstand ID1) | R101 | R_0805_2012Metric_Pad1.20x1.40mm_HandSolder | C17477

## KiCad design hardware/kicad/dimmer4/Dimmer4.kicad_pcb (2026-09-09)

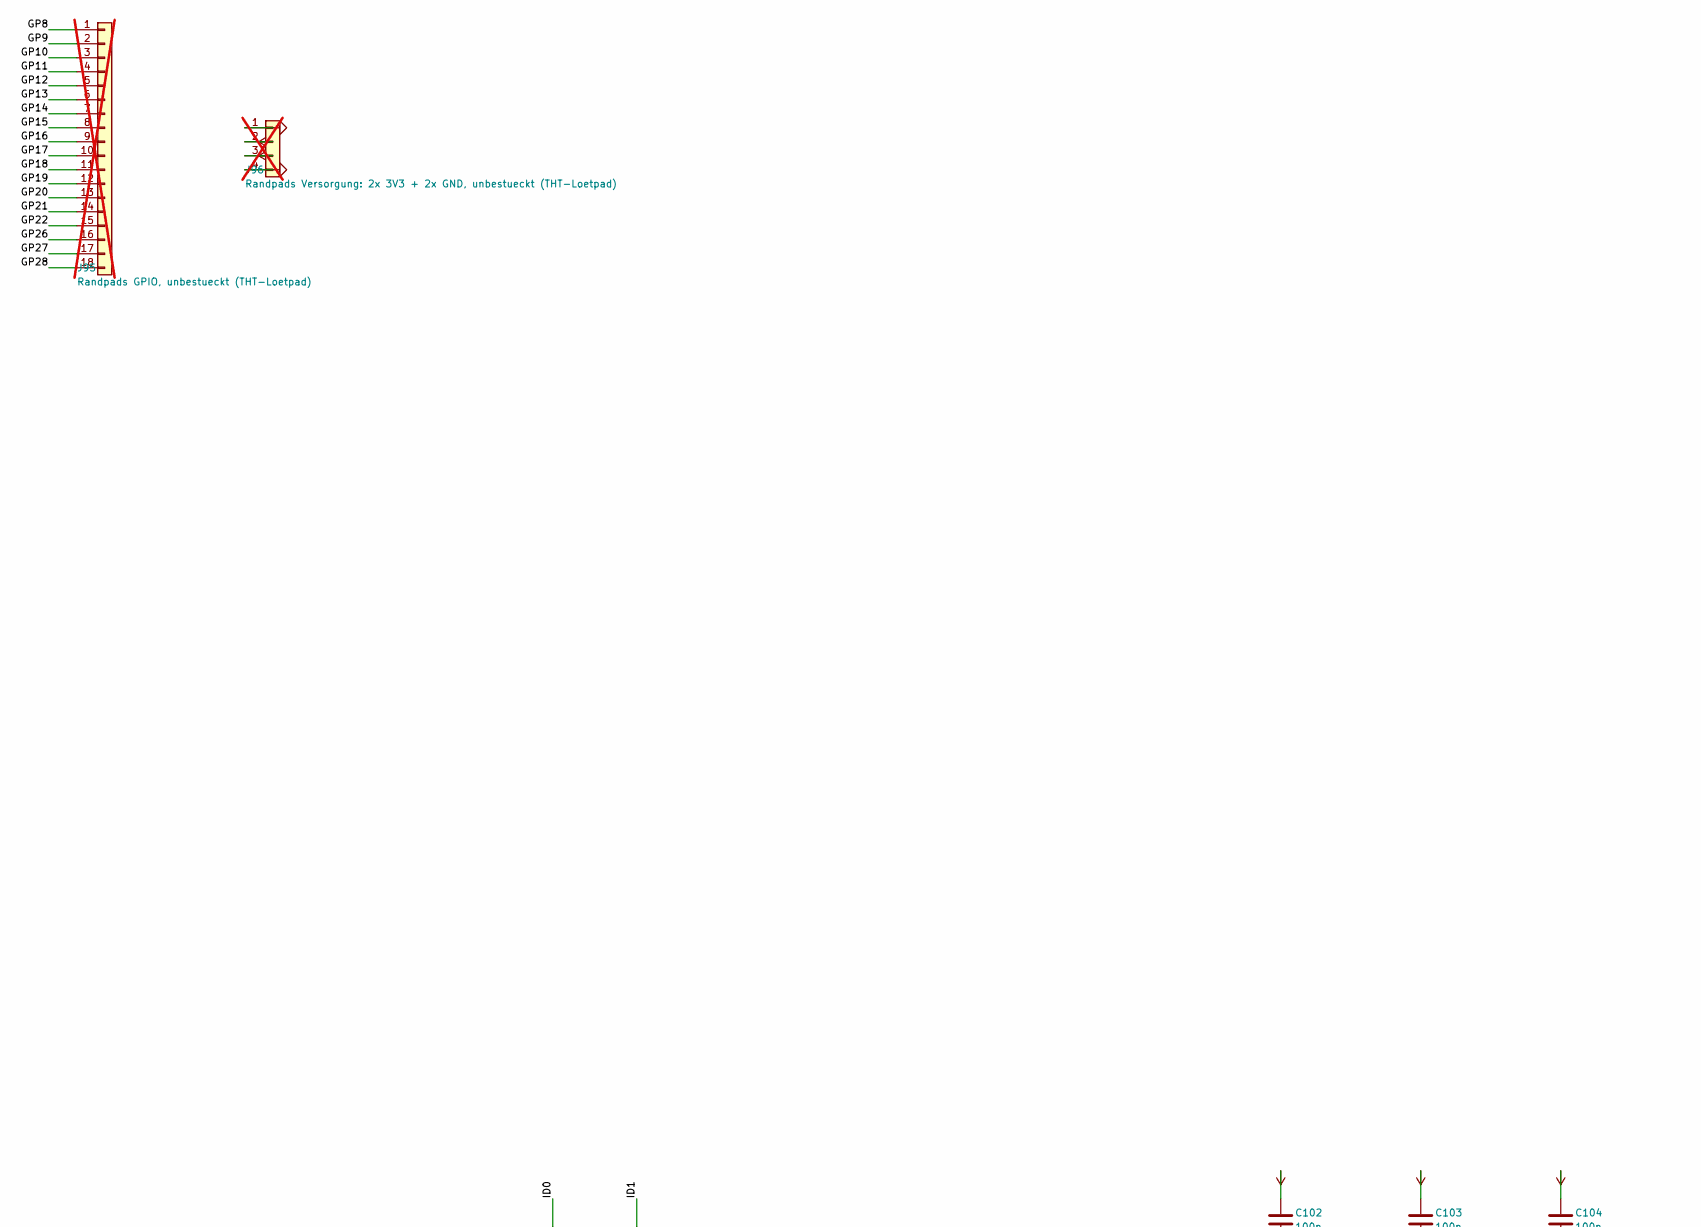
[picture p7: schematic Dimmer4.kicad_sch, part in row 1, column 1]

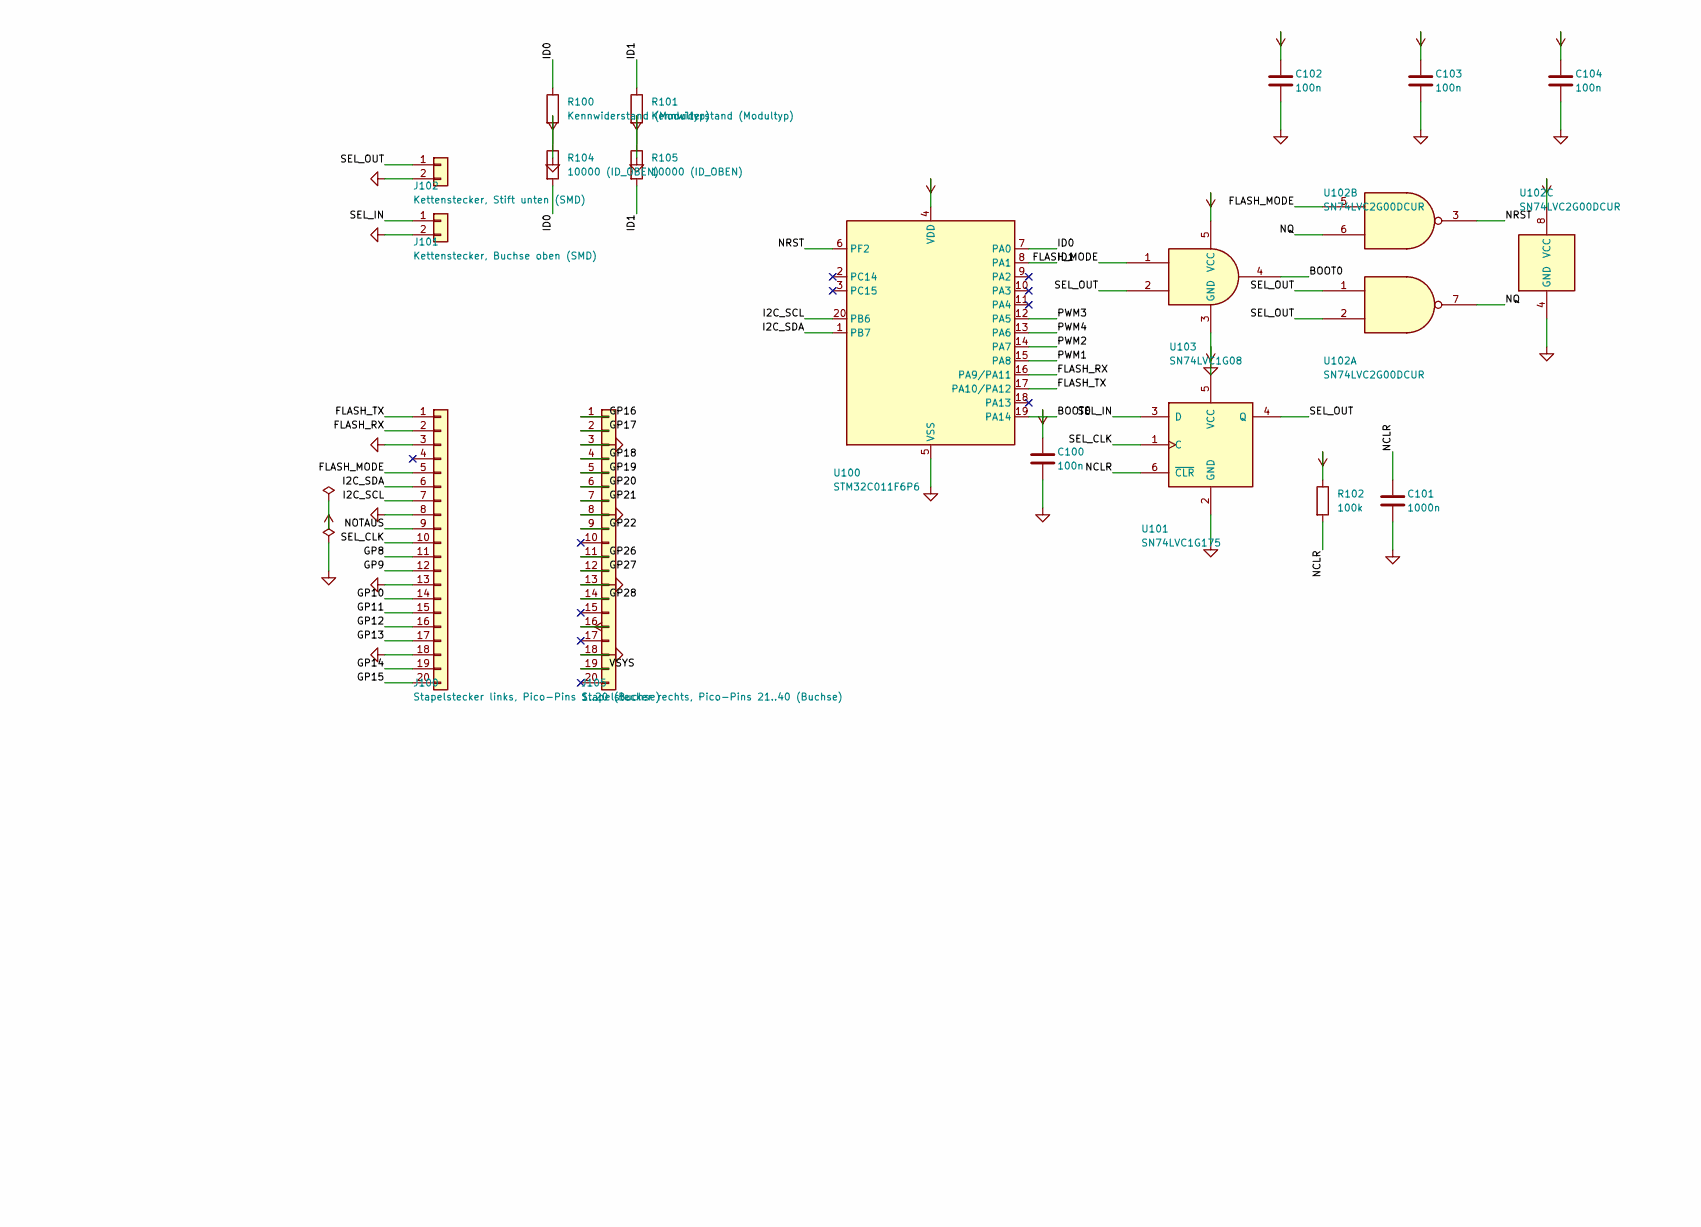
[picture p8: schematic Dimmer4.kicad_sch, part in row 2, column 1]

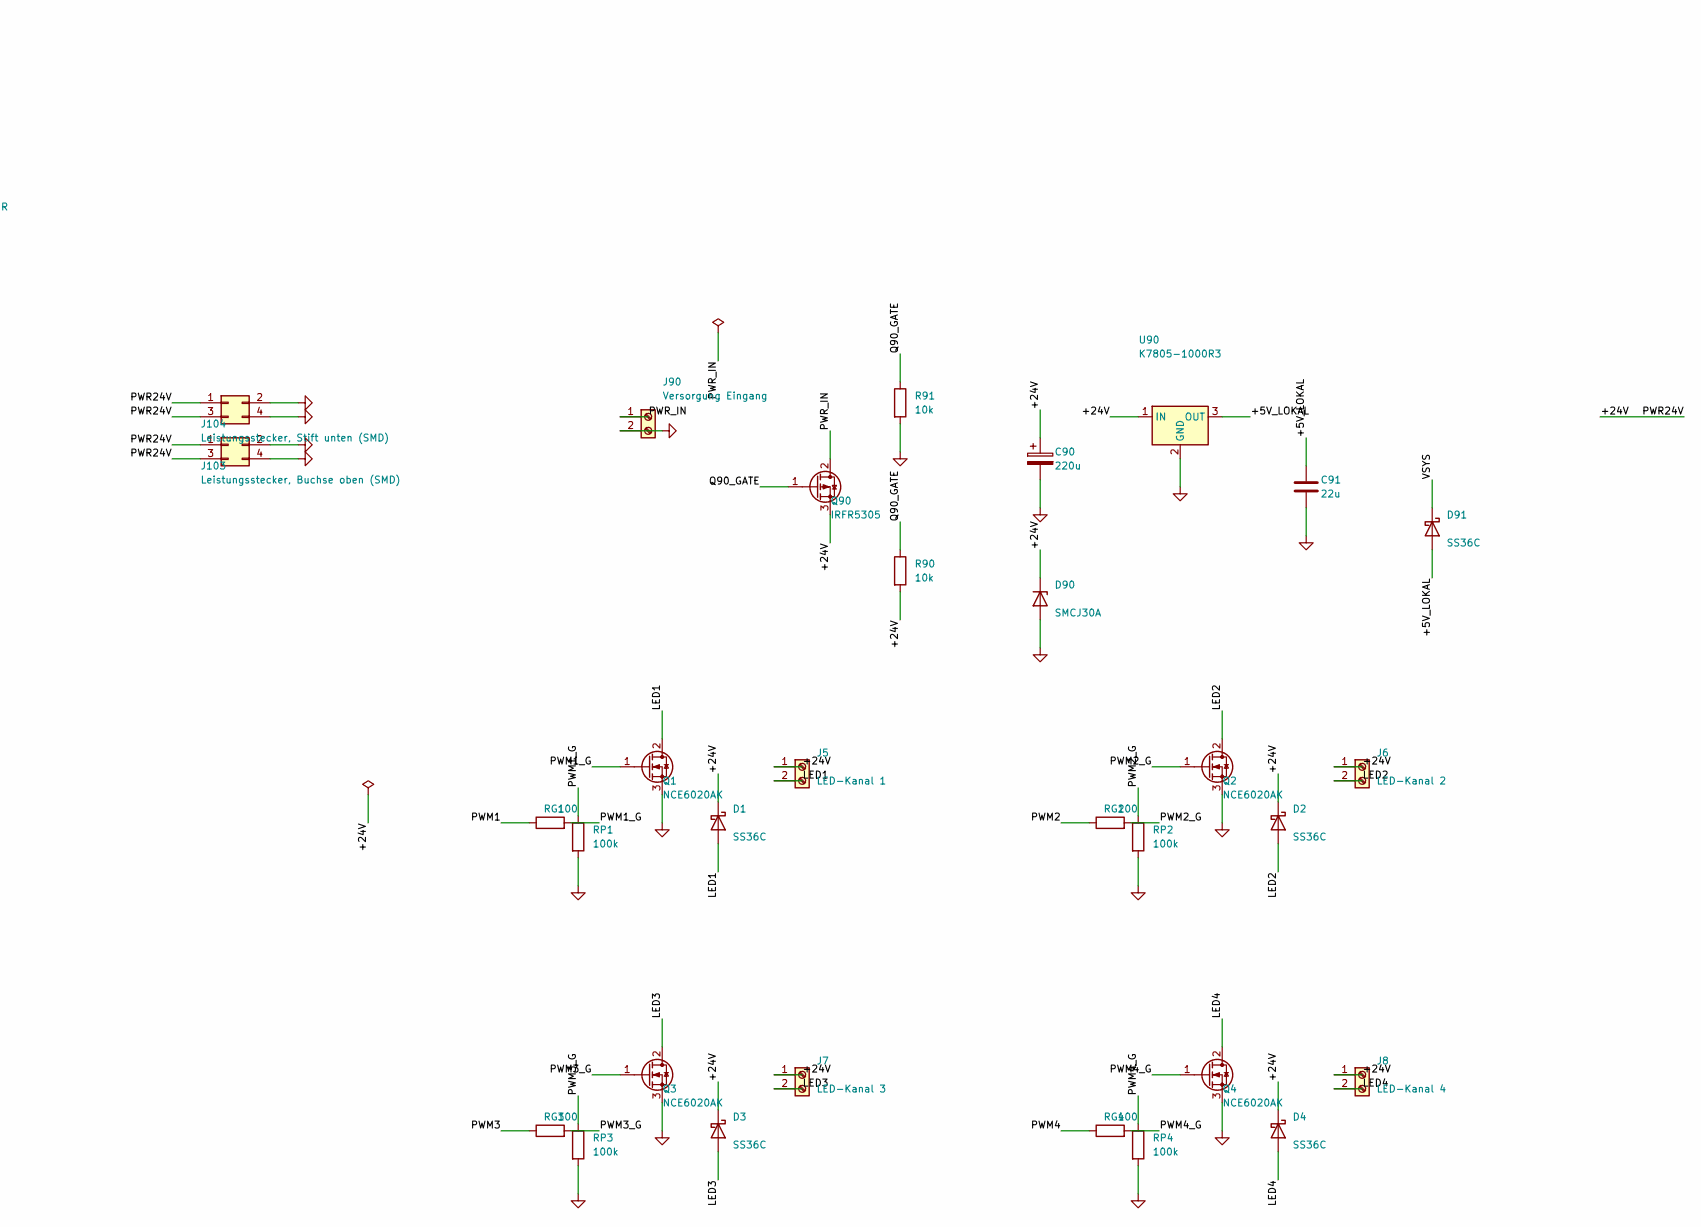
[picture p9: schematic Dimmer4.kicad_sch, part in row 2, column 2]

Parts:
C90: 220u; CP_Radial_D8.0mm_P3.50mm
C91: 22u; C_0805_2012Metric_Pad1.18x1.45mm_HandSolder
C100: 100n; C_0805_2012Metric_Pad1.18x1.45mm_HandSolder
C101: 1000n; C_0805_2012Metric_Pad1.18x1.45mm_HandSolder
C102, C103, C104: 100n; C_0805_2012Metric_Pad1.18x1.45mm_HandSolder; LCSC C49678
D1, D2, D3, D4, D91: SS36C; D_SMC
D90: SMCJ30A; D_SMC
J5: LED-Kanal 1; TerminalBlock_Phoenix_PT-1,5-2-3.5-H_1x02_P3.50mm_Horizontal
J6: LED-Kanal 2; TerminalBlock_Phoenix_PT-1,5-2-3.5-H_1x02_P3.50mm_Horizontal
J7: LED-Kanal 3; TerminalBlock_Phoenix_PT-1,5-2-3.5-H_1x02_P3.50mm_Horizontal
J8: LED-Kanal 4; TerminalBlock_Phoenix_PT-1,5-2-3.5-H_1x02_P3.50mm_Horizontal
J90: Versorgung Eingang; TerminalBlock_Phoenix_PT-1,5-2-3.5-H_1x02_P3.50mm_Horizontal
J95: Randpads GPIO, unbestueckt (THT-Loetpad); Randpad_Reihe_1x18; not fitted
J96: Randpads Versorgung: 2x 3V3 + 2x GND, unbestueckt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; Randpad_Reihe_1x04; not fitted
J100: Stapelstecker links, Pico-Pins 1..20 (Buchse); PinSocket_1x20_P2.54mm_Vertical
J101: Kettenstecker, Buchse oben (SMD); PinSocket_1x02_P2.54mm_Vertical_SMD_Pin1Left
J102: Kettenstecker, Stift unten (SMD); PinHeader_1x02_P2.54mm_Vertical_SMD_Pin1Left
J103: Leistungsstecker, Buchse oben (SMD); PinSocket_2x02_P2.54mm_Vertical_SMD
J104: Leistungsstecker, Stift unten (SMD); PinHeader_2x02_P2.54mm_Vertical_SMD
J105: Stapelstecker rechts, Pico-Pins 21..40 (Buchse); PinSocket_1x20_P2.54mm_Vertical
Q1, Q2, Q3, Q4: NCE6020AK; TO-252-3_TabPin2
Q90: IRFR5305; TO-252-3_TabPin2
R90, R91: 10k; R_0805_2012Metric_Pad1.20x1.40mm_HandSolder
R100, R101: Kennwiderstand (Modultyp); R_0805_2012Metric_Pad1.20x1.40mm_HandSolder
R102: 100k; R_0805_2012Metric_Pad1.20x1.40mm_HandSolder
R104, R105: 10000 (ID_OBEN); R_0805_2012Metric_Pad1.20x1.40mm_HandSolder
RG1, RG2, RG3, RG4: 100; R_0805_2012Metric_Pad1.20x1.40mm_HandSolder
RP1, RP2, RP3, RP4: 100k; R_0805_2012Metric_Pad1.20x1.40mm_HandSolder
U90: K7805-1000R3; Converter_DCDC_RECOM_R-78B-2.0_THT
U100: STM32C011F6P6; TSSOP-20_4.4x6.5mm_P0.65mm
U101: SN74LVC1G175; SOT-363_SC-70-6
U102: SN74LVC2G00DCUR; VSSOP-8_2.3x2mm_P0.5mm
U103: SN74LVC1G08; SOT-353_SC-70-5

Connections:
/+5V_LOKAL: C91.1, D91.2 (A), U90.3 (OUT)
/+24V: C90.1, D1.1 (K), D2.1 (K), D3.1 (K), D4.1 (K), D90.1 (K), J5.1, J6.1, J7.1, J8.1, J103.1, J103.3, J104.1, J104.3, Q90.3 (S), R90.2, U90.1 (IN)
/BOOT0: U100.19 (PA14), U103.4
/FLASH_MODE: J100.5, U102.5, U103.1
/FLASH_RX: J100.2, U100.16 (PA9/PA11)
/FLASH_TX: J100.1, U100.17 (PA10/PA12)
/GP8: J95.1, J100.11
/GP9: J95.2, J100.12
/GP10: J95.3, J100.14
/GP11: J95.4, J100.15
/GP12: J95.5, J100.16
/GP13: J95.6, J100.17
/GP14: J95.7, J100.19
/GP15: J95.8, J100.20
/GP16: J95.9, J105.1
/GP17: J95.10, J105.2
/GP18: J95.11, J105.4
/GP19: J95.12, J105.5
/GP20: J95.13, J105.6
/GP21: J95.14, J105.7
/GP22: J95.15, J105.9
/GP26: J95.16, J105.11
/GP27: J95.17, J105.12
/GP28: J95.18, J105.14
/I2C_SCL: J100.7, U100.20 (PB6)
/I2C_SDA: J100.6, U100.1 (PB7)
/ID0: R100.1, R104.2, U100.7 (PA0)
/ID1: R101.1, R105.2, U100.8 (PA1)
/LED1: D1.2 (A), J5.2, Q1.2 (D)
/LED2: D2.2 (A), J6.2, Q2.2 (D)
/LED3: D3.2 (A), J7.2, Q3.2 (D)
/LED4: D4.2 (A), J8.2, Q4.2 (D)
/NCLR: C101.1, R102.2, U101.6 (~CLR)
/NOTAUS: J100.9
/NQ: U102.6, U102.7
/NRST: U100.6 (PF2), U102.3
/PWM1: RG1.1, U100.15 (PA8)
/PWM1_G: Q1.1 (G), RG1.2, RP1.1
/PWM2: RG2.1, U100.14 (PA7)
/PWM2_G: Q2.1 (G), RG2.2, RP2.1
/PWM3: RG3.1, U100.12 (PA5)
/PWM3_G: Q3.1 (G), RG3.2, RP3.1
/PWM4: RG4.1, U100.13 (PA6)
/PWM4_G: Q4.1 (G), RG4.2, RP4.1
/PWR_IN: J90.1, Q90.2 (D)
/Q90_GATE: Q90.1 (G), R90.1, R91.1
/SEL_CLK: J100.10, U101.1 (C)
/SEL_IN: J101.1, U101.3 (D)
/SEL_OUT: J102.1, U101.4 (Q), U102.1, U102.2, U103.2
/VSYS: D91.1 (K), J105.19

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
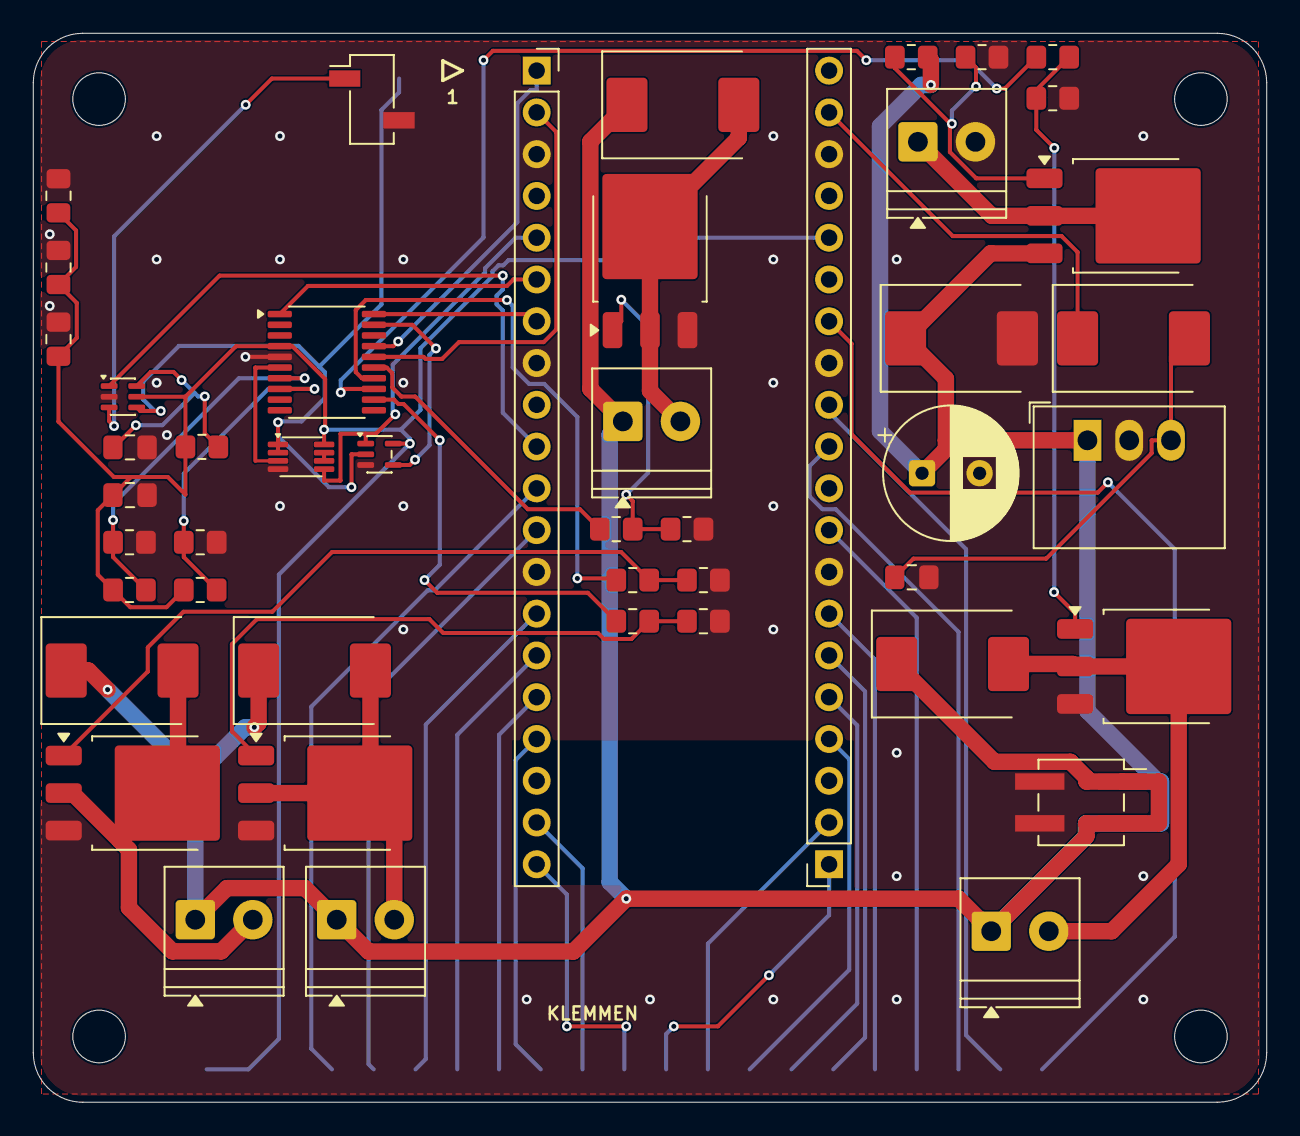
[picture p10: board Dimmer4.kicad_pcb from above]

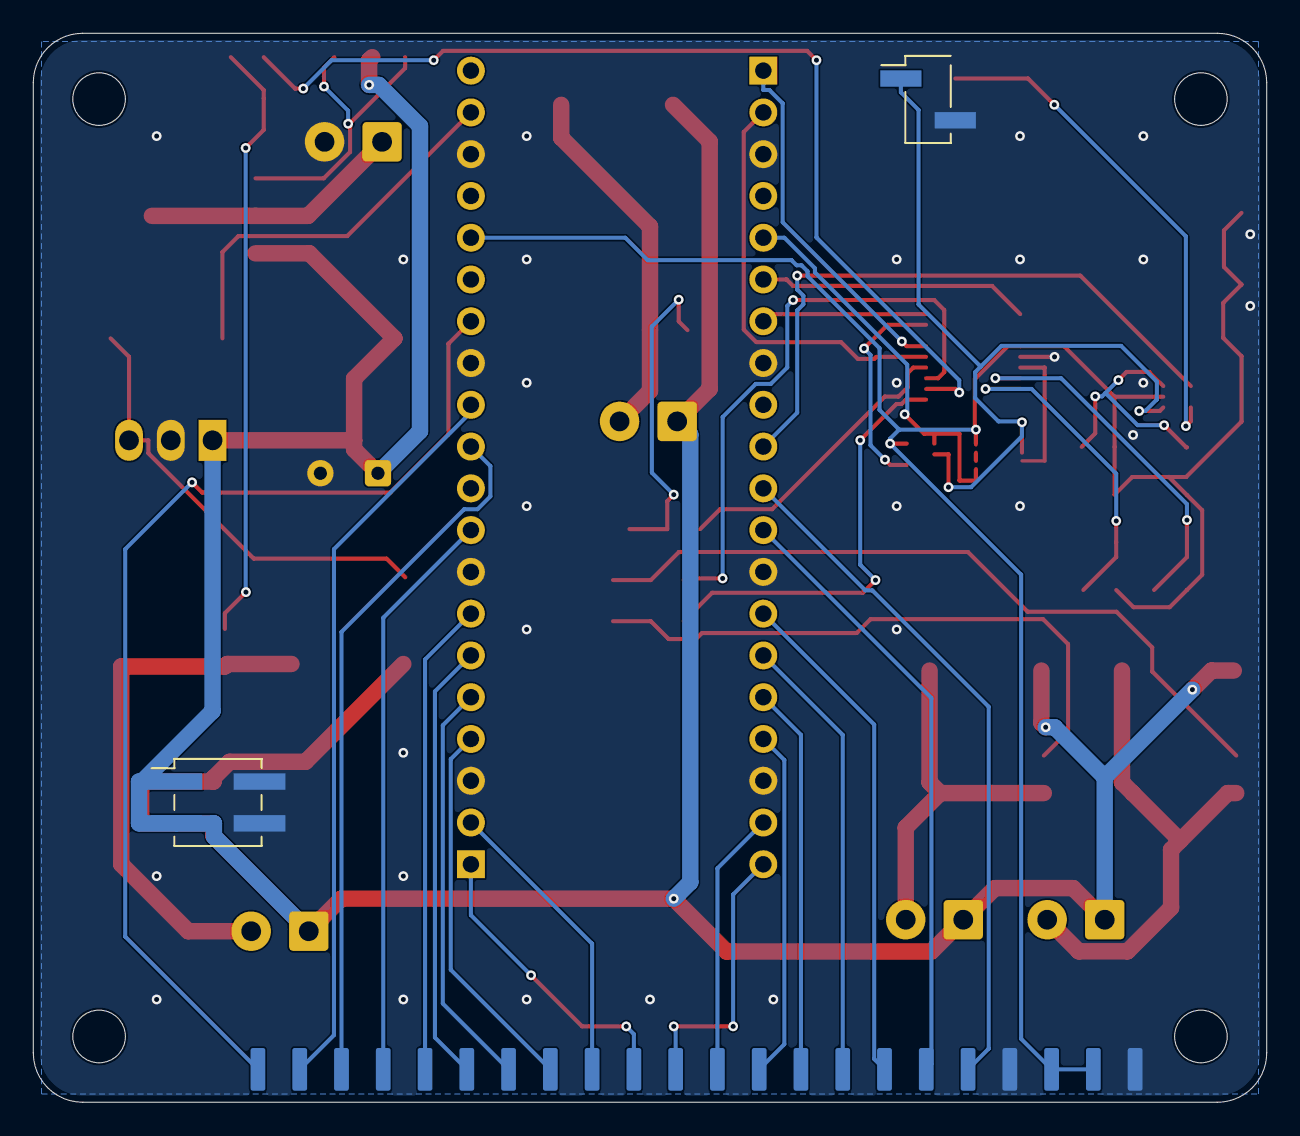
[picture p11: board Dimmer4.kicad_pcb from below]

Board: 2 copper layers, 75.0 x 65.0 mm, 55 parts (4 on the bottom side), 51 nets.

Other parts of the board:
H1, H2, H3, H4: M3

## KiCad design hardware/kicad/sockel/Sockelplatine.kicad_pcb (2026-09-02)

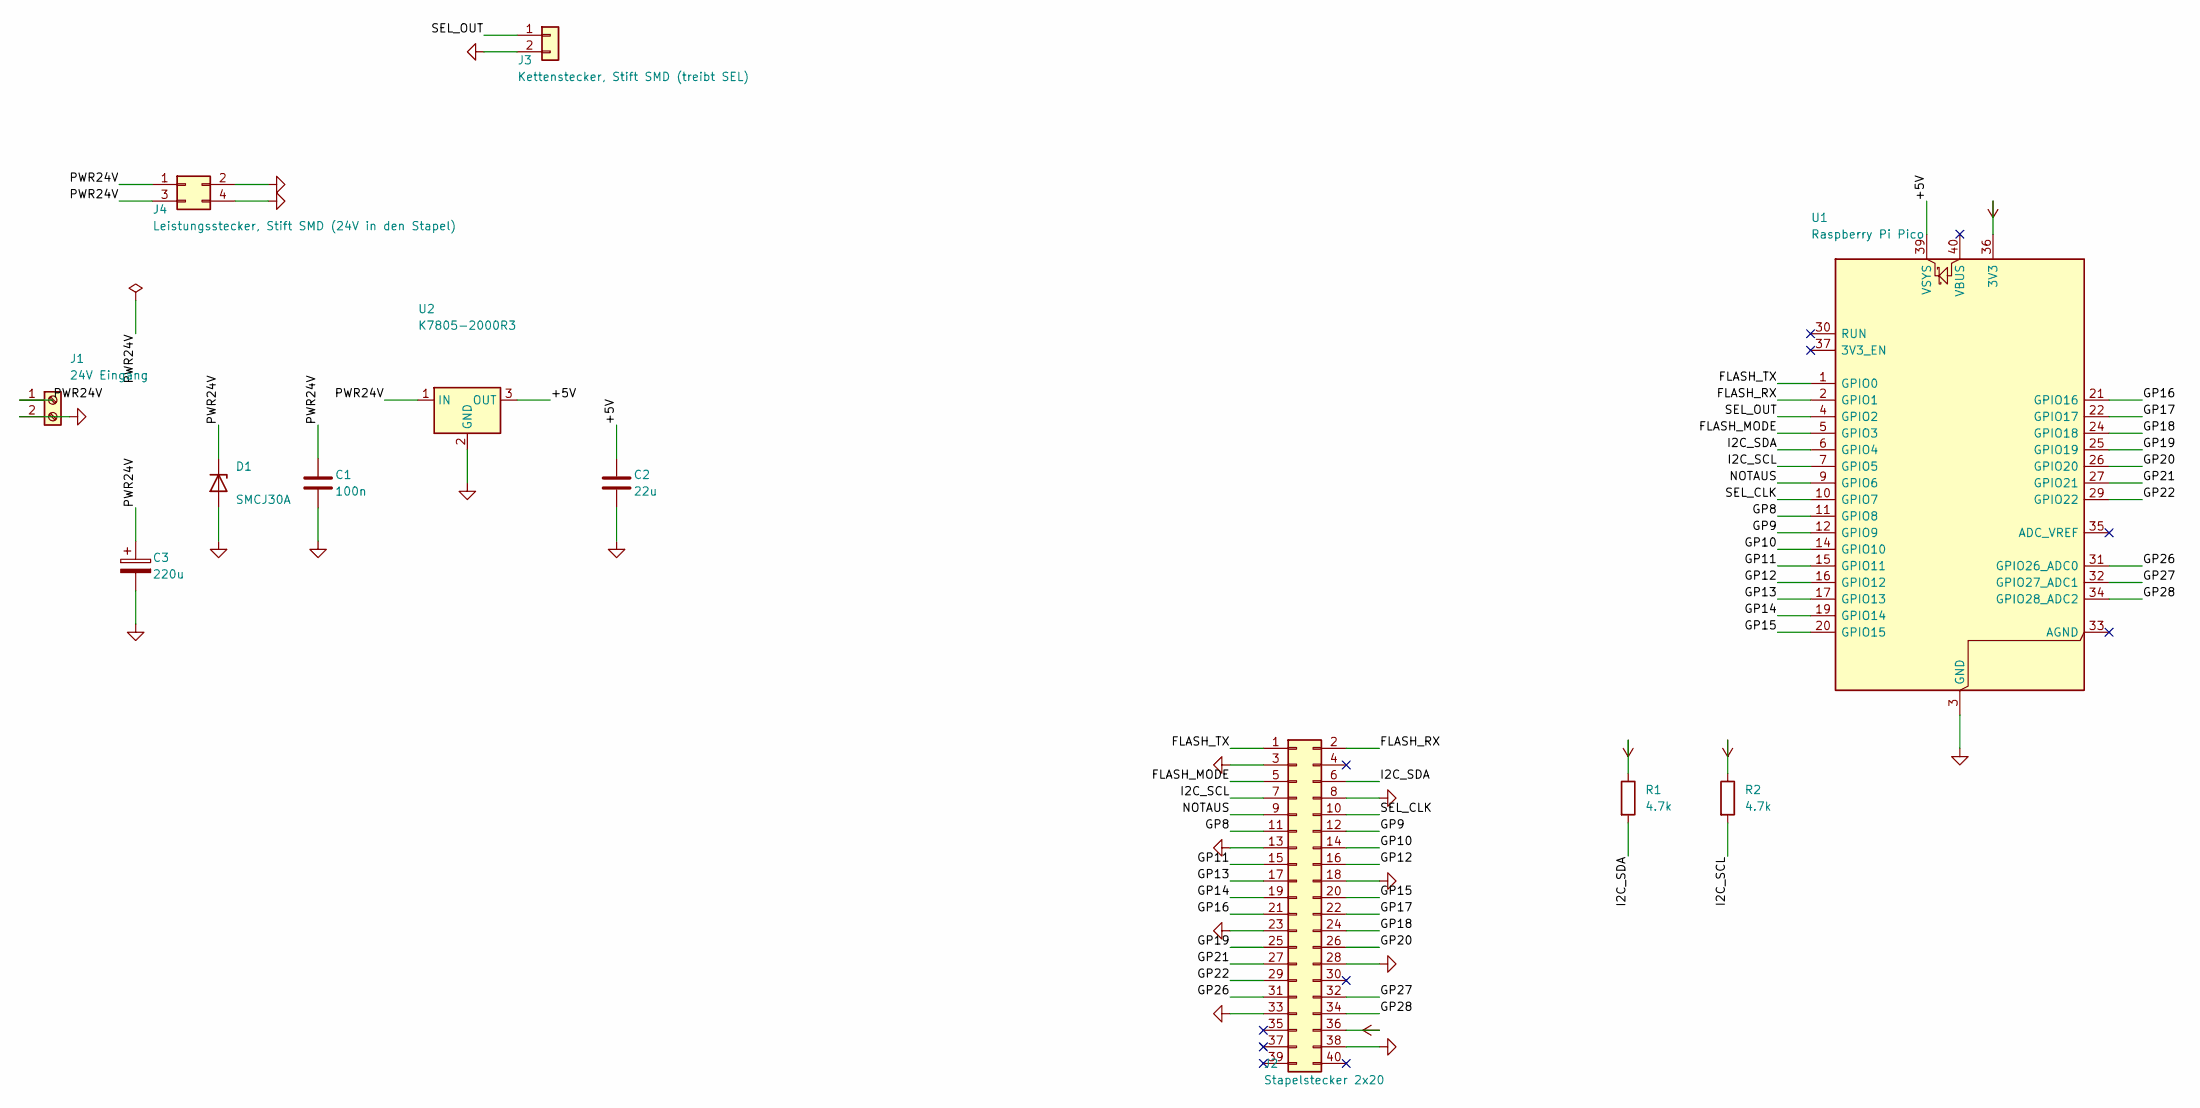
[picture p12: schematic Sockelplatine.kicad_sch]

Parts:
C1: 100n; C_0805_2012Metric_Pad1.18x1.45mm_HandSolder
C2: 22u; C_0805_2012Metric_Pad1.18x1.45mm_HandSolder
C3: 220u; CP_Radial_D8.0mm_P3.50mm
D1: SMCJ30A; D_SMC_Handsoldering
J1: 24V Eingang; TerminalBlock_Phoenix_MKDS-3-2-5.08_1x02_P5.08mm_Horizontal
J2: Stapelstecker 2x20; PinHeader_2x20_P2.54mm_Vertical
J3: Kettenstecker, Stift SMD (treibt SEL); PinHeader_1x02_P2.54mm_Vertical_SMD_Pin1Left
J4: Leistungsstecker, Stift SMD (24V in den Stapel); PinHeader_2x02_P2.54mm_Vertical_SMD
R1, R2: 4.7k; R_0805_2012Metric_Pad1.20x1.40mm_HandSolder
U1: Raspberry Pi Pico; RaspberryPi_Pico_Common_THT
U2: K7805-2000R3; Converter_DCDC_RECOM_R-78B-2.0_THT

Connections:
3V3: J2.36, R1.1, R2.1, U1.36 (3V3)
/+5V: C2.1, U1.39 (VSYS), U2.3 (OUT)
/FLASH_MODE: J2.5, U1.5 (GPIO3)
/FLASH_RX: J2.2, U1.2 (GPIO1)
/FLASH_TX: J2.1, U1.1 (GPIO0)
/GP8: J2.11, U1.11 (GPIO8)
/GP9: J2.12, U1.12 (GPIO9)
/GP10: J2.14, U1.14 (GPIO10)
/GP11: J2.15, U1.15 (GPIO11)
/GP12: J2.16, U1.16 (GPIO12)
/GP13: J2.17, U1.17 (GPIO13)
/GP14: J2.19, U1.19 (GPIO14)
/GP15: J2.20, U1.20 (GPIO15)
/GP16: J2.21, U1.21 (GPIO16)
/GP17: J2.22, U1.22 (GPIO17)
/GP18: J2.24, U1.24 (GPIO18)
/GP19: J2.25, U1.25 (GPIO19)
/GP20: J2.26, U1.26 (GPIO20)
/GP21: J2.27, U1.27 (GPIO21)
/GP22: J2.29, U1.29 (GPIO22)
/GP26: J2.31, U1.31 (GPIO26_ADC0)
/GP27: J2.32, U1.32 (GPIO27_ADC1)
/GP28: J2.34, U1.34 (GPIO28_ADC2)
/I2C_SCL: J2.7, R2.2, U1.7 (GPIO5)
/I2C_SDA: J2.6, R1.2, U1.6 (GPIO4)
/NOTAUS: J2.9, U1.9 (GPIO6)
/PWR24V: C1.1, C3.1, D1.1 (K), J1.1, J4.1, J4.3, U2.1 (IN)
/SEL_CLK: J2.10, U1.10 (GPIO7)
/SEL_OUT: J3.1, U1.4 (GPIO2)
GND: C1.2, C2.2, C3.2, D1.2 (A), J1.2, J2.3, J2.8, J2.13, J2.18, J2.23, J2.28, J2.33, J2.38, J3.2, J4.2, J4.4, U1.3 (GND), U1.8 (GND), U1.13 (GND), U1.18 (GND), U1.23 (GND), U1.28 (GND), U1.38 (GND), U2.2 (GND)

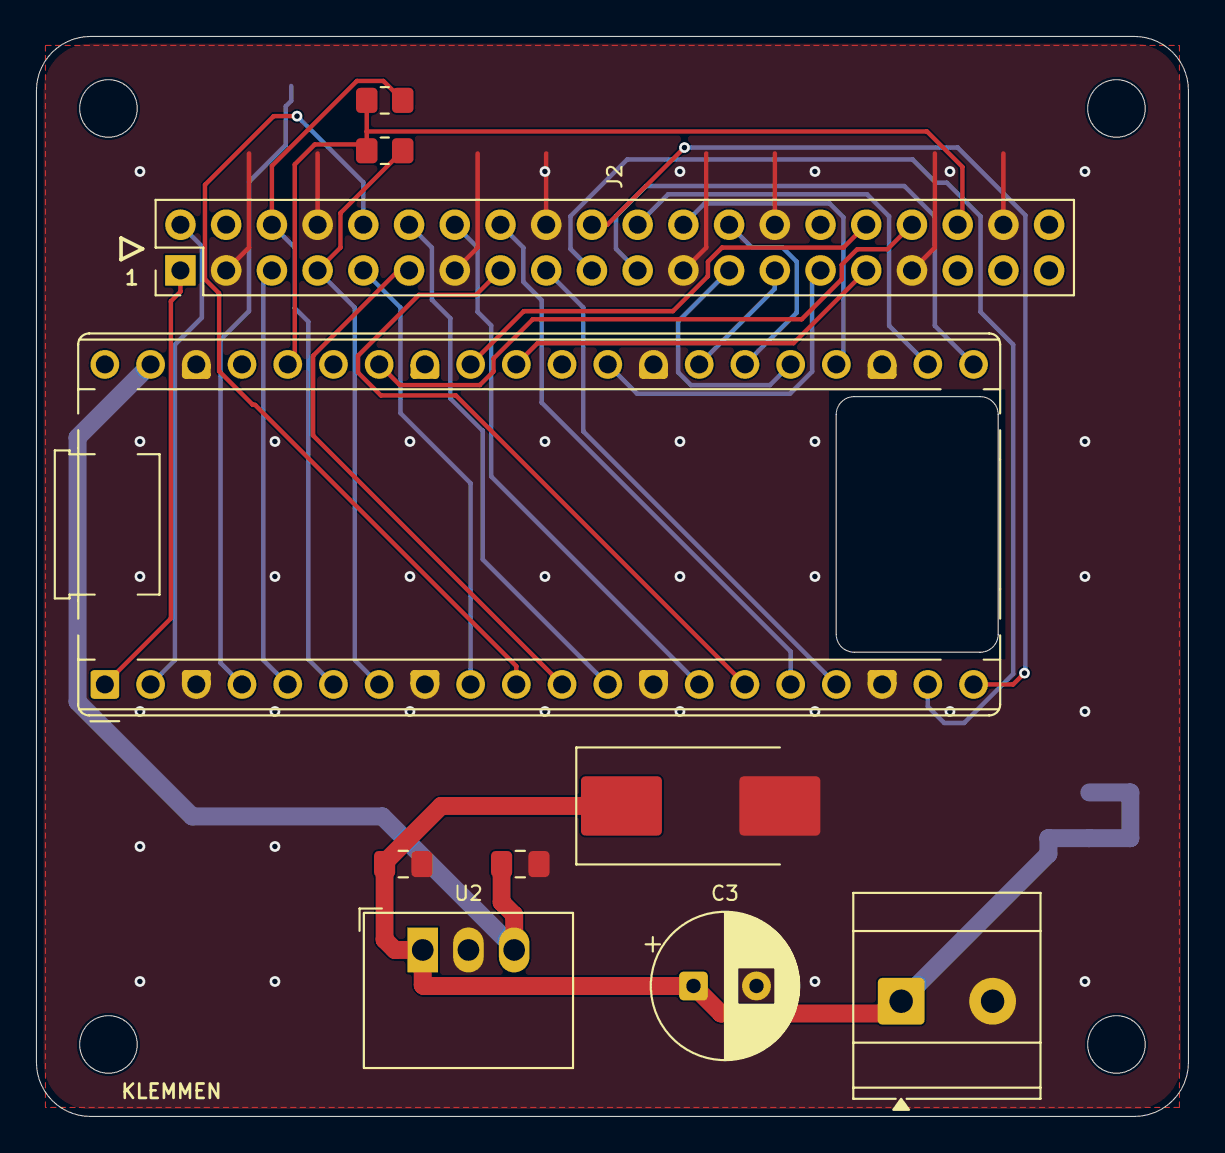
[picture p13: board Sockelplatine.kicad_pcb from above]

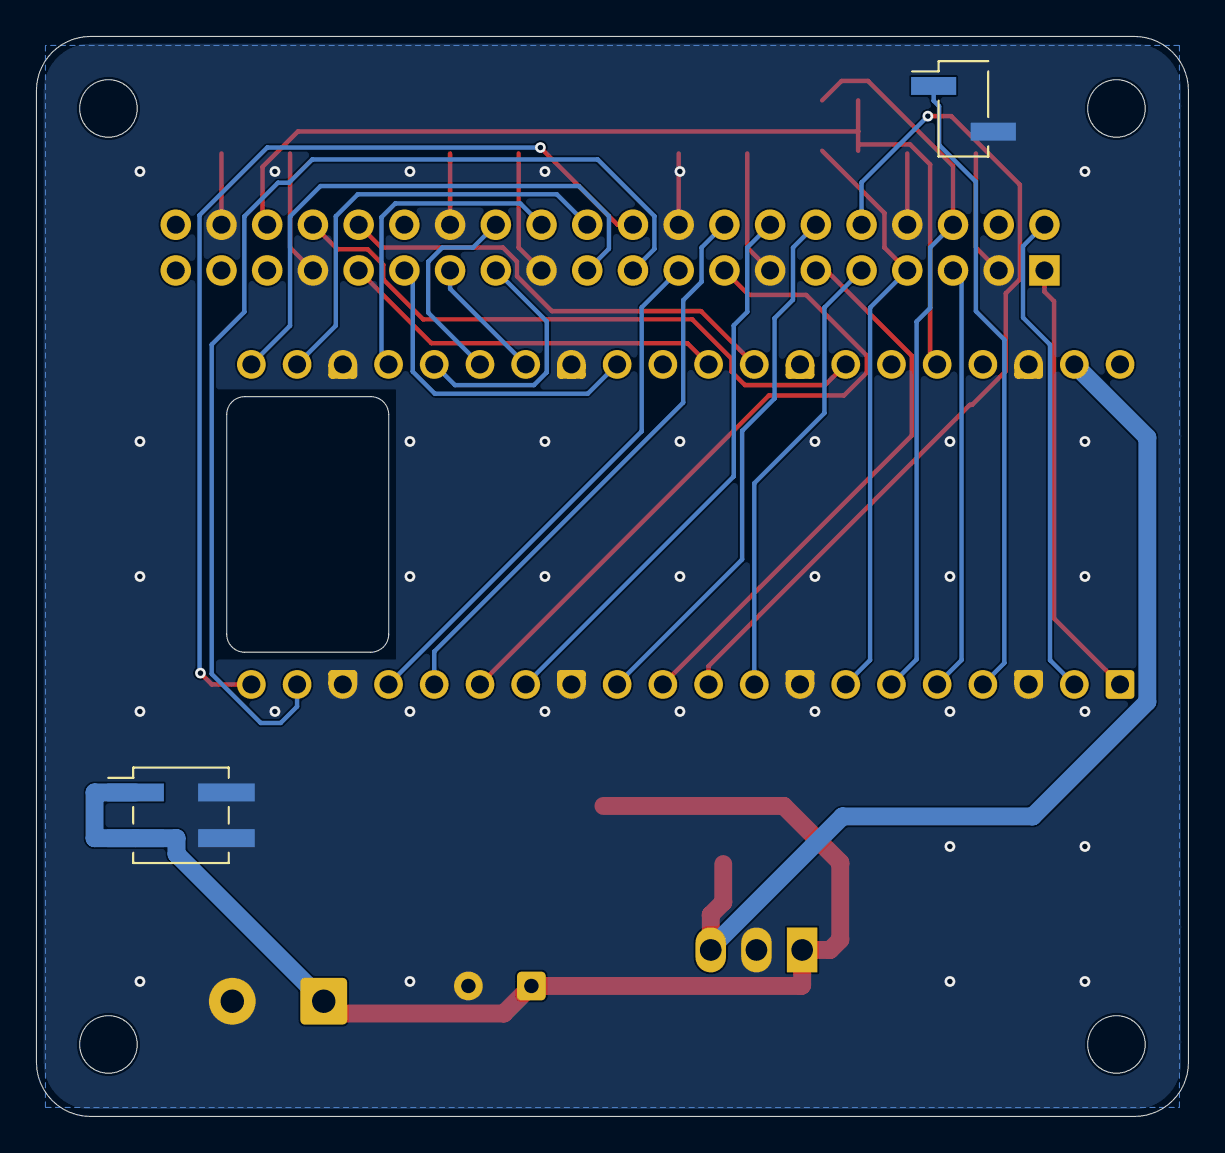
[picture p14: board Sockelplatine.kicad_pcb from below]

Board: 2 copper layers, 64.0 x 60.0 mm, 16 parts (2 on the bottom side), 30 nets.

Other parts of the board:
H1, H2, H3, H4: M3

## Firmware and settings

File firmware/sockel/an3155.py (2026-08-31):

"""Der USART-Bootlader der STM32, so weit PicoStack ihn braucht.

Laeuft auf dem Pico unter MicroPython und beschreibt darueber die
Modul-MCU. Absichtlich klein gehalten: synchronisieren, loeschen,
schreiben, starten -- mehr braucht das Aufspielen einer Firmware
nicht.

Bewusst NICHT dabei ist der Get-Befehl: AN3155 Abschnitt 3.1 laesst
den Chip mit ACK, N, Version, N Befehlsbytes und nochmals ACK
antworten. Wer davon nur die erste Quittung abholt, laesst den Rest im
Empfangspuffer stehen -- der naechste Befehl liest ihn dann als seine
eigene Quittung. Gebraucht wird Get hier nirgends; halb umgesetzt ist
er gefaehrlicher als gar nicht umgesetzt.

Die Schnittstelle ist 8 Datenbits mit gerader Paritaet und einem
Stoppbit. Jeder Befehl geht mit seinem Einerkomplement hinaus; das ist
die einzige Pruefung, die das Protokoll auf der Befehlsebene hat.

EHRLICHKEIT: Diese Umsetzung ist nur gegen eine Attrappe geprueft
(tests/test_an3155.py), nie gegen echtes Silizium. Kein STM32 hat je
darauf geantwortet.

Werte nach ST AN3155 (Rev. 16, Februar 2023):
- ACK/NACK: Abschnitt "Communication safety" (Seite 8/50)
- SYNC und Bootloader-Sequenz: Abschnitt 1 (Seite 5/50)
- Befehlscodes: Table 2 (Seite 7/50)
- Go: Abschnitt 3.5 (Seite 18/50)
- Write Memory: Abschnitt 3.6 (Seite 20/50)
- Extended Erase Memory: Abschnitt 3.8 (Seite 26/50)
- Prüfsummen-Regel: Abschnitt "Communication safety" (Seite 8/50)
  - XOR für alle Daten-Bytes
  - Befehl + Komplement (XOR = 0xFF)
  - Global erase (0xFFFF) mit Checksum 0x00

REVISIONSABGLEICH (2026-08, siehe docs/nachweis-2026-08.md): Es gibt
eine neuere Fassung, AN3155 Rev 21 (Februar 2026, bestaetigt ueber die
ST-Downloadseite und unabhaengig ueber die Revisionshistorie auf
stmcu.jp: Rev 17 05.03.2024, Rev 18 24.05.2024, Rev 19 04.02.2025,
Rev 20 03.07.2025, Rev 21 Februar 2026). Gegen die hier verwendeten
Werte geprueft -- ACK/NACK (0x79/0x1F), SYNC (0x7F), die Befehlscodes
0x44/0x31/0x21, die Komplement- und XOR-Pruefsummenregel aus
"Communication safety", die Laengenbyte-Konvention N/N+1 bei Write
Memory und der Massenloeschcode 0xFFFF mit Checksum 0x00 bei Extended
Erase: **unveraendert gegenueber Rev 16**. Rev 17-21 fuegen laut
Revisionshistorie nur neue MCU-Serien zur Produktliste hinzu
(u.a. STM32U0, STM32WBA, STM32WB0, STM32U3, STM32WL3x) und aendern
Abbildungen/Protection-Hinweise, nicht die Bytes auf der Leitung.
Rev 16 wurde Seite fuer Seite gegengelesen (PDF direkt geladen); Rev 21
wurde ueber einen Proxy-Abruf gelesen, dessen Angaben (Revisionsdaten,
Befehlstabelle, Communication-safety-Text, Write-Memory- und
Extended-Erase-Abschnitt) mit einer zweiten, unabhaengigen Quelle
(stmcu.jp) und der Google-Suchvorschau des PDF selbst abgeglichen
wurden, aber nicht Seite fuer Seite lokal nachvollzogen wie bei Rev 16.
Bezug bleibt deshalb Rev 16 als gepruefte Primaerquelle.
"""

ACK = 0x79
NACK = 0x1F

SYNC = 0x7F
CMD_ERASE_EXT = 0x44
CMD_WRITE = 0x31
CMD_GO = 0x21


def _xor(daten, start=0):
    p = start
    for b in daten:
        p ^= b
    return p


class Bootlader:
    def __init__(self, uart):
        self.uart = uart

    # --- unterste Ebene ---
    def _quittung(self):
        """Ein Byte lesen und pruefen, ob es ACK ist.

        machine.UART.read() liefert bei Zeitueberschreitung None, nicht
        b"" -- len(None) wuerde einen TypeError werfen. Genau dieser
        Fall ist "Pico an, kein Chip antwortet", also der erste
        Handgriff am Tisch: er muss ein sauberes False melden, keinen
        Absturz.
        """
        a = self.uart.read(1)
        if not a:
            return False
        return len(a) == 1 and a[0] == ACK

    def _befehl(self, code):
        """Befehl samt Komplement senden und Quittung abholen."""
        self.uart.write(bytes([code, code ^ 0xFF]))
        return self._quittung()

    # --- Protokoll ---
    def sync(self):
        self.uart.write(bytes([SYNC]))
        return self._quittung()

    def erase_all(self):
        if not self._befehl(CMD_ERASE_EXT):
            return False
        # 0xFFFF = Massenloeschung, Pruefsumme ist das XOR darueber
        self.uart.write(b"\xff\xff\x00")
        return self._quittung()

    def write(self, adresse, daten):
        if not daten or len(daten) > 256 or len(daten) % 4:
            raise ValueError("Block muss 1..256 Byte und durch 4 teilbar sein")
        if not self._befehl(CMD_WRITE):
            return False
        a = bytes([(adresse >> 24) & 0xFF, (adresse >> 16) & 0xFF,
                   (adresse >> 8) & 0xFF, adresse & 0xFF])
        self.uart.write(a + bytes([_xor(a)]))
        if not self._quittung():
            return False
        n = len(daten) - 1
        self.uart.write(bytes([n]) + daten + bytes([_xor(daten, n)]))
        return self._quittung()

    def go(self, adresse):
        if not self._befehl(CMD_GO):
            return False
        a = bytes([(adresse >> 24) & 0xFF, (adresse >> 16) & 0xFF,
                   (adresse >> 8) & 0xFF, adresse & 0xFF])
        self.uart.write(a + bytes([_xor(a)]))
        return self._quittung()

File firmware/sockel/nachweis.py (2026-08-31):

"""Beschreibt einen Modul-MCU vom Pico aus. Nachweis, kein Produkt.

Reihenfolge: ueber die Kettenlogik in den Bootlader bringen,
synchronisieren, loeschen, blockweise schreiben, ueber dieselbe
Kettenlogik zurueck in die Anwendung.

Auf dem Tischaufbau gibt es weder Flipflop noch Gatter: Pico und MCU
sind ueber vier blanke Draehte verbunden (siehe
docs/nachweis-2026-08.md). Die Pico-UART-Pins entsprechen
FLASH_TX/FLASH_RX aus stack_spec.PIN_ROLLE (Steckerpins 1/2) und
fuehren direkt zum Bootlader-USART der MCU (physisch PA11/PA12, siehe
hardware/bauteile.md). BOOT0 und NRST dagegen liegen hier direkt an
den rohen MCU-Pins (PA14/NRST) an, nicht an SEL/SEL_CLK/FLASH_MODE --
auf der fertigen Platine haelt erst ein D-Flipflop die Auswahl (Q) und
ein Gatter leitet daraus mit FLASH_MODE Reset und Bootlader-Auswahl
ab. Beides existiert auf dem Tisch nicht; das eine Modul am Tisch ist
hier von Hand als "ausgewaehlt" gesetzt (q=1).

EHRLICHKEIT: Dieses Programm ist noch nie auf Hardware gelaufen. Es
ist nicht einmal syntaktisch auf einem Pico geprueft -- MicroPython
mit machine.UART gibt es auf dem Entwicklungsrechner nicht.
"""
from machine import Pin, UART
import time
from an3155 import Bootlader
from kette import modul_zustand

BLOCK = 256
START = 0x08000000

# timeout: MicroPython liefert bei Zeitueberschreitung None zurueck,
# was an3155._quittung() als "keine Antwort" meldet. Ohne timeout=
# blockiert read() je nach Port unbestimmt lange -- ein Modul ohne
# bestueckten MCU laesst den Nachweis dann einfach haengen, statt einen
# Fehler zu melden.
# 2000 ms: Die Quittungen auf SYNC und die Schreibbloecke kommen in
# wenigen Millisekunden; der lange Fall ist die Massenloeschung, deren
# Dauer wir nicht nachgeschlagen haben. Der Wert ist deshalb bewusst
# grosszuegig geschaetzt und nicht aus einem Datenblatt hergeleitet --
# er soll nur verhindern, dass ein toter Chip den Aufbau blockiert.
uart = UART(0, baudrate=115200, bits=8, parity=0, stop=1, tx=0, rx=1,
            timeout=2000)
boot0 = Pin(2, Pin.OUT)
nrst = Pin(3, Pin.OUT)


def reset(flash_mode, q):
    """Reset- und BOOT0-Pegel nicht direkt setzen, sondern ueber
    kette.modul_zustand(flash_mode, q) ableiten -- derselben
    Gatterlogik, die auf der fertigen Platine aus FLASH_MODE und dem
    Flipflop-Ausgang Q gebildet wird. Ein direktes Setzen von
    BOOT0/NRST wuerde eine zweite, womoeglich abweichende Logik neben
    die Kettenlogik stellen, die schon gegen die Wahrheitstabelle
    geprueft ist (tests/test_kette.py). So prueft dieser Nachweis am
    Tisch denselben Weg, den spaeter die Gatter in Kupfer ausfuehren --
    nur eben in Software nachgerechnet, weil sie auf dem Tischaufbau
    (noch) fehlen.

    q ist am Tisch von Hand gesetzt: es gibt nur ein Modul und kein
    Schieberegister, das die Auswahl weiterschieben koennte.

    flash_mode=1, q=1 waehlt dieses (einzige) Modul im Flash-Modus:
    reset=0, boot0=1 -- der Bootlader startet.
    flash_mode=0 ist der Normalbetrieb: reset=0, boot0=0 -- die
    Anwendung startet.
    """
    reset_haltung, boot0_ziel, _sel_out = modul_zustand(flash_mode, q)
    boot0.value(boot0_ziel)
    nrst.value(0)
    time.sleep_ms(10)
    nrst.value(0 if reset_haltung else 1)
    time.sleep_ms(50)


def aufspielen(pfad):
    reset(flash_mode=1, q=1)
    bl = Bootlader(uart)
    if not bl.sync():
        raise RuntimeError("keine Antwort vom Bootlader")
    if not bl.erase_all():
        raise RuntimeError("Loeschen abgelehnt")
    with open(pfad, "rb") as f:
        adresse = START
        while True:
            block = f.read(BLOCK)
            if not block:
                break
            if len(block) % 4:
                block += b"\xff" * (4 - len(block) % 4)
            if not bl.write(adresse, block):
                raise RuntimeError("Schreiben abgelehnt bei 0x%08X" % adresse)
            adresse += len(block)
    reset(flash_mode=0, q=0)
    print("aufgespielt:", pfad)

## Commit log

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2026-08-31 Auswahlkette: Schieberegister statt Kombinatorik
    Die alte Fassung war rein kombinatorisch (SEL_OUT = ¬flash_mode ∧
    sel_in) und im Flash-Modus damit immer 0: nur das oberste Modul war je
    erreichbar, die Adressvergabe aus der Spezifikation fiel aus. Der
    Docstring versprach ein Wandern des Tokens, das die Schaltung nicht
    leisten konnte -- ihr fehlte der Speicher.
    Jedes Modul bekommt jetzt ein D-Flipflop an einer neuen gemeinsamen
    Taktleitung SEL_CLK. D = SEL_IN, Q = "ausgewaehlt" und zugleich
    SEL_OUT. Der Sockel legt eine 1 an, taktet, und die 1 wandert je Takt
    eine Position tiefer; mitgezaehlte Takte sind die Adressen.
    modul_zustand() bleibt als reine Gatterlogik daneben stehen (jetzt
    ueb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
    [kette.py, nachweis.py, test_kette.py]
2026-08-31 Vertrag: SEL_CLK, Auflage zur Sendeleitung, Bohrdurchmesser, Status
    SEL_CLK ist die neue gemeinsame Taktleitung der Auswahlkette; sie
    bekommt den bisher freien Pin 10 (GP7). Keine bestehende Zuweisung
    aendert sich.
    Neu ausserdem im Vertrag: die Auflage, dass Modulfirmware die
    gemeinsame Sendeleitung (FLASH_RX am Pico) ausserhalb des Flash-Modus
    nicht treiben darf. Im Normalbetrieb sind alle Module gleichzeitig
    wach -- ohne diese Regel haengen mehrere Sender an einer Leitung.
    M3_DRILL stand im Datenmodul, fehlte aber in der Lochbild-Tabelle:
    wer nach dem Bohrdurchmesser sucht, fand ihn im Vertrag nicht.
    Der Statushinweis sagt jetzt im Vertrag selbst, dass die Flash-Pins an
    einer unbelegten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
    [stack_spec.py, vertrag_doku.py]
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2026-08-31 Auflage festhalten: Kette vor erstem FLASH_MODE leertakten
    Reale D-Flipflops starten mit undefiniertem Q; ohne Leertakten koennen
    mehrere Modul-MCU gleichzeitig im Bootlader landen und sich ueber die
    gemeinsame Sendeleitung stoeren. Regel + Begruendung im Design-Doc,
    Klarstellung im kette.py-Docstring (q=0 ist Sim-Annahme, keine
    Hardware-Eigenschaft), Auswahlkriterium (asynchroner Loescheingang) in
    bauteile.md Beleg 4.
    [kette.py]
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2026-08-31 Werkzeugketten aus Muttern-Redesign und LED-Dimmer uebernommen
    geometry.py, build.py und autoroute.py importierten im Vorlaeuferprojekt
    ein globales Modul "spec" fuer genau eine Platine; build.py trug zudem
    deren Dateipfad fest ein und autoroute.py griff darauf zu. PicoStack
    baut zwei Platinen (Sockel, Motormodul) im selben Baukasten -- die drei
    Werkzeuge sind jetzt platinenunabhaengig: geometry.check_all(placement,
    beschreibung), build.bauen(beschreibung, board_pfad, sch_pfad),
    autoroute.verlegen(board_pfad, leistungsnetze). netclasses.py hatte
    denselben globalen-Import-Fehler, wurde vom Auftrag aber nicht genannt;
    gleich mitbehandelt, sonst waere er beim ersten Zwei-Platinen-Lauf
    wieder au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
    [autoroute.py, build.py, geometry.py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]
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2026-08-31 Modulsockel als gemeinsamer Schaltplanblock
    gen.py aus led_dimmer/gen_sch.py gezogen (comp/net/wire/nc/emit/
    selfcheck als Schaltplan-Methoden), modulsockel.py baut MCU, Flipflop,
    Gatter, Kennwiderstaende und alle Stecker ausschliesslich aus
    stack_spec.PIN_ROLLE/kette.py auf. Angepasst an die zwei veralteten
    Stellen im Brief: 1x NOT/2x AND (SEL_OUT ist der Flipflop-Ausgang),
    eigener Kettenstecker statt SEL im 2x20-Stapelstecker.
    Echtes kicad-cli sch erc gegen das generierte Blatt deckte drei Bugs
    in gen.py auf, die die reine Pin-auf-Draht-Selbstpruefung nicht sehen
    konnte: Power-Symbole nie geladen (Phantom-Verbindung), extends-
    Vererbung (STM32C011F6Px) von kicad-cli nicht aufgeloest (MCU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
    [gen.py, modulsockel.py, test_modulsockel.py]
2026-08-31 Reset-Verpolung an NRST behoben: aus dem AND-Gatter wird ein NAND
    RESET war in tools/kette.py aktiv HIGH modelliert (1 = im Reset
    gehalten), aber direkt auf den aktiv-LOW NRST-Pin des STM32C011
    verdrahtet -- ein nicht ausgewaehltes Modul liefe, statt im Reset zu
    stehen, und umgekehrt.
    NRST = ¬(FLASH_MODE ∧ ¬Q) statt eines direkt verdrahteten AND liefert
    die fehlende Invertierung ohne ein zusaetzliches Gatter im Signalweg.
    BOOT0 bleibt unveraendert AND (aktiv HIGH, keine Verpolung dort).
    - tools/sch/modulsockel.py: der bisherige Dual-AND-IC (74LVC2G08GT,115,
    XSON-8) wird durch zwei Einzel-Gatter-ICs im SOT-353-5-Gehaeuse
    ersetzt (wie das schon vorhandene NOT-Gatter): U103 = SN74LVC1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
    [kette.py, modulsockel.py, test_modulsockel.py]
2026-08-31 Reset-Gatter zu Dual-NAND konsolidiert, ERC-Lauf als Testschritt
    Zwei Pruefer-Befunde zum vorherigen Fix (aus dem AND-Gatter fuer NRST
    wird ein NAND) behoben:
    1. Der zusaetzliche Baustein aus dem vorherigen Fix war vermeidbar: ein
    NAND mit kurzgeschlossenen Eingaengen ist ein Inverter (NAND(Q,Q) =
    ¬Q). NOT (Q -> NQ) und das NRST-Gatter sind damit beide NAND und
    passen in ein Doppel-NAND-Bauteil; nur BOOT0 bleibt ein
    eigenstaendiges AND. tools/sch/modulsockel.py: U102 ist jetzt
    SN74LVC2G00DCUR (Dual-NAND, drei Platzierungen: NOT via NAND(Q,Q),
    NRST-NAND, gemeinsame Versorgung), U103 bleibt der Einzel-AND fuer
    BOOT0 -- zwei physische Gatter-ICs statt drei. Die vorgeschla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
    [modulsockel.py, test_modulsockel.py]
2026-08-31 Sockelplatine: Schaltplan erzeugt
    U1 Pico + U2 K7805-2000R3 (5V an VSYS, nicht 3V3_OUT) + 24V-Eingang
    (J1/D1/C3/C1/C2) + I2C-Abschluss (R1/R2) + Stapel-/Ketten-/Leistungs-
    stecker (J2/J3/J4, nur die noetigen Haelften). Kein MCU/Flipflop/
    Gatter -- der Sockel ist kein Modul. ERC 0 Fehler, VSYS-Zufuehrung per
    Test und Netzliste bestaetigt.
    [Sockelplatine.kicad_sch]
2026-08-31 Sockelplatine: freie GPIO voll zum Stapel durchreichen, SEL_OUT auf Pin 4 zurueckverlegt
    Zwei zusammenhaengende Befunde der vorigen Runde (Aufgabe 4) behoben:
    1. Freie Pico-GPIO waren sowohl auf der Sockelplatine (U1) als auch auf
    J2 (modulsockel._stapelstecker()) no_connect -- der Stapelstecker
    leitet zwar mechanisch durch, aber ohne Draht vom Pico dorthin hing
    an keinem freien GPIO je etwas. modulsockel._stapelstecker() bekommt
    dafuer einen neuen Parameter frei_durchreichen (Vorgabe False, jedes
    Modul-J100 unveraendert); die Sockelplatine ruft J2 damit auf und
    verdrahtet U1 unter denselben Netznamen (modulsockel.PIN_GPIO_NAME).
    RUN (Pin 30) und ADC_VREF (Pin 35) bleib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
    [Sockelplatine.kicad_sch]
2026-08-31 RUN und ADC_VREF sind keine freien GPIO: Vertragsrollen statt Vorgabe
    Dritter Fall derselben Luecke in dieser Etappe: PIN_ROLLE fuehrte einen
    Pin als "frei", der es nicht ist. Pin 4 trieb lokal die Auswahlkette
    (Befund 2 der Fix-1-Runde), Pin 30 ist der aktiv-LOW Reset des RP2040
    und Pin 35 die analoge ADC-Referenz. Ein Modulautor, der sich auf den
    Vertrag verlaesst, haette den Pico zurueckgesetzt oder die Referenz
    belastet.
    Die Fix-1-Runde hatte beide Pins bereits richtig von der Durchreichung
    ausgenommen, aber nur als Kommentar in modulsockel.PIN_GPIO_NAME. Das
    steht jetzt im Vertrag selbst, und eine Pruefung schliesst die Klasse
    ab statt den naechsten Einzelfall abzuwarten: die Menge der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
    [modulsockel.py, stack_spec.py, test_modulsockel.py]
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2026-09-01 Geerbte Fehler aus dem Muttern-Print als Gattung geprueft, drei gefunden
    Die Endstufe wurde uebernommen, ohne sie nachzurechnen. Zwei Fehler waren
    bekannt, den dritten hat erst die Gattungspruefung gefunden:
    R6 (Vorwiderstand des Sensor-Optokopplers) verheizte 0,236 W in einem
    0805 mit 0,125 W Belastbarkeit -- Faktor 1,9 dauerhaft ueber Grenzwert.
    Behoben nicht durch ein groesseres Gehaeuse, sondern durch Weglassen des
    ganzen Sensoreingangs (J2, R6, U2): er war schon im Altprojekt unbenutzt,
    und die Spec nennt fuer den Modultyp Motor nur Treiber, Strommessung und
    Notaus. Ein Bauteil, das nichts tut, aber ueberlastet ist, wird nicht
    vergroessert. Frei wird dabei PC14 als GPIO und der einzige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
    [Motormodul.kicad_sch]
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2026-09-01 Die Stifthaelften des Sockels sassen oben statt unten
    Eigener Fehler aus dem Layout von gestern. J3 und J4 sind die
    Stifthaelften der SMD-Steckerpaare; der Vertrag sagt "Buchse oben,
    Stiftleiste unten", und der Sockel sitzt zuoberst im Stapel und treibt
    nach UNTEN in das oberste Modul. Ungespiegelt auf der Oberseite zeigen
    seine Stifte ins Leere, und die Pads liegen auf der falschen
    Kupferlage. Aufgefallen beim Aufstellen der Bauteilliste fuer das
    Motormodul -- das traegt von beiden Steckern BEIDE Haelften, und dort
    faellt die Seitenfrage sofort auf.
    Platz bekommt dafuer ein Feld unten; build.place() spiegelt vor dem
    Vermessen des Hofes; geometry.check_all() laesst Teile auf
    verschiedenen S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
    [Sockelplatine.kicad_pcb]
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2026-09-03 Open-Source-Geruest: Lizenzen, englische Doku, Website, Werkzeug-Vervollstaendigung
    Vorbereitung der Veroeffentlichung als offenes Projekt (PicoStack):
    * Lizenzen: CERN-OHL-S-2.0 fuer hardware/, GPL-3.0-or-later fuer den
    Rest -- Copyleft nach Absprache, damit Weiterentwicklungen offen
    bleiben.
    * README, CONTRIBUTING (inkl. Rot-Nachweis-Regel und Modul-Anleitung),
    Code of Conduct, Issue-/PR-Vorlagen -- alles Englisch; die deutschen
    Code-Kommentare sind als Uebergangszustand deklariert.
    * docs/: eigenstaendige Projektseite fuer GitHub Pages (index.html,
    Logo, Renders), .nojekyll.
    * tools/pcb/kipy liegt jetzt IM Repo (vorher nur im lokalen
    Skill-Verzeichnis -- die Kette war fuer Fr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
    [Modulsockel.kicad_sch, Motormodul.kicad_sch, Sockelplatine.kicad_sch]
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2026-09-07 CPL: JLC-Rotationskorrektur fuer SOT-353/363, TSSOP, VSSOP-8
    U100-U103 standen im Bestueckungs-Preview verdreht: JLCs Bibliothek
    hat fuer diese Familien andere Null-Drehungen als KiCad. Korrektur-
    winkel aus JLCKicadTools und Fabrication-Toolkit (identische Werte,
    beide gesichtet), angewandt als (Winkel + Korrektur) mod 360.
    TO-252 korrigieren beide bewusst nicht -- das verdrehte IRFR5305-
    Modell ist eine Teil-Eigenheit fuer den Preview-Editor.
    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
    [jlc-cpl.csv]
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2026-09-07 Sockel-BOM: K7805 auf lieferbaren JETEKPS-Eintrag C5378008
    C2931187 (DEXU) ist bei JLC/LCSC abgekuendigt (noBuyReason im
    Seiten-JSON) -- das erklaert den '5 shortfall' im Bestelldialog.
    C5378008 ist derselbe K78-Klon von JETEKPS, 34 Stueck JLC-Lager.
    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
    [jlc-bom.csv]
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2026-09-07 Platzprobe v2: Eckloch-Randabstand gegen alle vier Pflichtflaechen pruefen
    Review-Fund (Fix-Runde 1): die Kollisionspruefung testete den
    Eckloch-Randabstand bisher nur gegen die Pico-Zone (oben) und die
    Randpad-Kante (unten) -- nicht gegen die Versorgungszelle, die mit
    57,2 mm BREITER ist als die Randpad-Kante (55,88 mm) und deshalb die
    eigentlich straffere Bedingung waere. Der Check haengte damit an der
    im ersten Entwurf angenommenen Regal-Reihenfolge und wuerde bei jeder
    anderen Anordnung der vier Zonen still falsch. pruefe() rechnet jetzt
    den Randabstand (W - Zonenlaenge)/2 >= M3_REICHWEITE fuer alle vier
    Pflichtflaechen unabhaengig von ihrer tatsaechlichen Position und
    druckt die Rechnun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
    [platzprobe_v2.py]
2026-09-08 stack_spec v2: der Pico ist der Stapel + Rot-Liste der Folgearbeiten
    VERTRAG_VERSION=2, BOARD_W/H=75/65 (aus platzprobe_v2.py). Der
    2x20-Stapelstecker STECKER_POS["stapel"] wird zu zwei 1x20-Buchsen-
    reihen in echter Pico-Geometrie (Reihenabstand 17,78 mm) --
    stapel_links/stapel_rechts, je eine Seite des Pico, PIN_ROLLE
    unveraendert. kette/leistung neu positioniert (v1-Herleitungslogik,
    neu gerechnet gegen die jetzt seitlich liegende Stapelzone) --
    gefunden dabei einen echten Fehler: eine mittig zentrierte Placierung
    der beiden Stapelreihen haette die Verdreh-Probe auf 0,50 mm gedrueckt
    (v1-Reissleine 2,5 mm), weil beide Reihen exakte Spiegelbilder
    voneinander sind; behoben mit 2,0-mm-Versat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
    [stack_spec.py, test_stack_spec.py]
2026-09-08 Fix-Runde 1: Kommentar-Arithmetik, Stapelstecker-Sourcing, Antennen-Keepout
    Reagiert auf Task-Review (Approved + 2 Important + 2 Rulings):
    1. Kommentarfehler bei STECKER_POS behoben: die Luft zwischen kette und
    stapel_links ist 4,06 mm (28,06 - 24,0), nicht 2,06 mm wie behauptet
    -- reiner Rechenfehler im Kommentar, keine Geometrie- oder
    Testaenderung.
    2. RULING: der Plan-Fallback "eine Spalte eines 2x20-PC104-Teils (C35165)
    bestuecken" ist mechanisch nicht baubar (die zweite, unbenutzte
    Pinreihe braucht trotzdem ihre eigenen Bohrungen, die ein 1x20-
    Lochbild nicht vorhaelt). STECKER_STAPEL jetzt als echte einreihige
    Stapelleiste (1x20 oder 2x 1x10 in Reihe, Arduino-Sta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
    [stack_spec.py, test_stack_spec.py]
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2026-09-08 Aufgabe 5: Motormodul v2 (Notaus-Fix 1G06->1G07, Versorgungszelle statt Q1)
    Notaus-Fix (Rot-Nachweis in TDD): U6/U7 liefen als SN74LVC1G06 (INVERTIERender
    Open-Drain-NOT), waehrend saemtliche Doku/Pegelrechnung nichtinvertierendes
    Verhalten voraussetzte -- das Board war fail-unsafe (intakte Schleife zog
    Notaus, ein Drahtbruch gab ihn frei). Ersetzt durch SN74LVC1G07 (nicht-
    invertierender OD-Puffer, pinidentisch, LCSC C7830). Datenblatt SCES296AG
    per WebFetch selbst gelesen: Ii korrigiert (+-5uA statt +-1uA), kein
    Schmitt-Trigger mehr (dokumentiert warum trotzdem sicher), Pin 1 (NC) ist
    im 1G07-Symbol anders als im 1G06-Symbol ein echter Pin -> sch.nc() ergaenzt.
    Q1/R11/R12/D1/C12 (falsch g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
    [Motormodul.kicad_sch]
2026-09-08 Fix-Runde 1: VSYS (Pin 39) v2-belegbar -- Vertragswiderspruch behoben
    Task-Review-Befund (tragend): stack_spec.NICHT_BELEGBAR verbot v1 jede
    Einspeisung auf VSYS (Pin 39), weil niemand ihn trieb. Die v2-VERSORGUNG-
    Zusage (vsys_diode=True) verlangt aber genau das Gegenteil -- jede
    Versorgungszelle (versorgung.py, D91) speist VSYS ueber eine Schottky-
    Diode. Der Vertrag verbot damit das Netz, das er selbst zusagt; D91s
    Kathode landete auf einem Knoten ohne Verbraucher (isolated_pin_label-
    ERC-Warnung im Motormodul).
    TDD: tests/test_stack_spec.py zuerst um den Check
    `IST_BELEGBAR(39) == True` ergaenzt (rot: False != True). Behoben in
    tools/stack_spec.py -- Pin 39 aus NICHT_BELEGBAR entfernt,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
    [Motormodul.kicad_sch]
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2026-09-08 Fix-Runde 1 zu Task 6: Motorsignale optional, PWM3/4 auf PA5/PA6
    modulsockel.einbauen() verdrahtete PA2..PA6 (Pin 9-13) bisher
    UNBEDINGT auf die DRV8876-Motorsignale (IN1/IN2/NSLEEP/NFAULT/IPROPI)
    -- eine Altlast aus der Zeit mit nur einem Modultyp, die jedem Modul
    ohne eigenen Motortreiber fuenf Port-A-Pins kostete. Neuer Parameter
    motorsignale=False (Vorgabe): nur ein Modul mit motorsignale=True
    (Motormodul) bekommt die feste Verdrahtung, jedes andere Modul
    behandelt die fuenf Pins wie gewoehnliche freie GPIO (zusatz_pins oder
    no_connect).
    Motormodul fordert die Signale jetzt explizit an (motorsignale=True) --
    Regressionsnachweis: generierte Netzliste vor/nach dem Umbau
    byte-identisch (Sc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
    [Dimmer1.kicad_sch, Dimmer3.kicad_sch, Dimmer4.kicad_sch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]
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2026-09-08 Fix-Runde 1 zu Aufgabe 7: Stapelreihen vertragstreu -- FOOTPRINT_HOF gemessen statt geschaetzt
    Beide Stapelreihen des Motormoduls sassen um (-0,78|+0,50) mm neben dem
    Vertrag: Vertrag stapel_links pin1 (30,61|2,27), gebaut (29,83|2,77);
    stapel_rechts identisch versetzt. Board-zu-Board haette sich das
    herausgekuerzt (alle v2-Boards teilen den Fehler) -- ein Modul, das ein
    Dritter exakt nach Vertrag baut, haette aber nicht gepasst. Vertrags-
    treue, nicht Selbstkonsistenz.
    URSACHE. stack_spec.FOOTPRINT_HOF fuehrte fuer die 1x20-Stapelbuchse
    5,10 x 50,80 mm. Diese Zahl war NICHT gemessen, sondern aus dem
    RESERVIERUNGSMASS PICO_REIHE_L/B des Aufgabenzettels abgeleitet -- der
    Kommentar sagte das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
    [spec_motor.py, stack_spec.py, steckerprobe.py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]
2026-09-08 Aufgabe 7b: Motormodul auf der vertragstreuen Platzierung neu verlegt
    Neu gebaut und neu verlegt, nachdem der B0-Fix beide Stapelreihen um
    (+0,78|-0,50) mm auf die Vertragslage gezogen hat. 14 Wuerfellaeufe
    (Laeufe n und p), bester Stand n2.
    Stand:
    kicad-cli pcb drc --severity-error --exit-code-violations
    Found 0 violations
    Found 4 unconnected items
    davon EINE Netz-Luecke: /CPL C10-2 <-> U1-14
    und drei GND-Inseln (masseheiler: F.Cu-Stuecke bei x 13,8..15,6 y
    26,3..27,1 und x 12,6..16,6 y 18,7..25,7; B.Cu-Stuecke bei
    x 47,0..49,3 y 43,6..48,8 und x 11,8..16,6 y 18,7..20,0).
    pcb_checks.py: 129 Vias, alle beidseitig angebunden; ANTENNE_FREI auf
    F.Cu kupferfrei.
    steck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
    [Motormodul.kicad_pcb]
2026-09-09 Fix-Runde 2 zu Aufgabe 7: Randpads auf B.Cu, Verdreh-Kupferregel erfuellt
    Steckerprobe jetzt VOLLSTAENDIG gruen, einschliesslich
    "Verdreht 46 Landepunkte, alle >= 1.5 mm von freiliegendem Kupfer" --
    ohne jede Ausnahmeliste, wie im Ruling verlangt.
    RANDPADS AUF DIE RUECKSEITE (Ruling). Auf der Oberseite ist die Klausel
    mit einer 2,54-mm-Padreihe unerfuellbar: auf dem Raster liegt immer ein
    Pad <= 1,27 mm von jedem x, minus 0,85 mm Padhalbbreite bleiben 0,42 --
    verlangt sind 1,5. Sechs der 22 VERTRAGLICHEN Randpad-Koordinaten
    brachen die Regel selbst, drei davon mit Abstand 0,000 mm. Auf B.Cu
    bleibt die Schutzzusage voll erhalten (ein verdreht gestecktes Modul
    trifft nur F.Cu), und es bleiben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
    [Motormodul.kicad_sch]
2026-09-09 Fix-Runde 2, Nachschlag: Ostkorridor fuer /CPH und /CPL freigelegt
    /CPL blieb in ALLEN ACHT Wuerfen des Laufs r offen, /CPH in drei von
    acht -- und die Ursache war eine Bahn, die ich in dieser Runde selbst
    gelegt hatte.
    Nachgemessen am besten Board (r7, nur /CPL offen): der Router fuehrt
    /CPH ueber die B.Cu-Spur x = 47,17 nach Sueden, also durch den Korridor
    zwischen meiner /+24V-Nordspur und der J105-Padreihe (Padkante 47,54).
    Mit der Nordspur auf x = 46,30 war dieser Korridor 0,74 mm breit -- eine
    0,25-mm-Bahn braucht 0,65, zwei brauchen 1,10. Es passte also genau
    EINE, und /CPH gewann sie jedes Mal.
    Nordspur auf x = 45,80 verschoben: Korridor 1,24 mm, beide passen. Zum
    /VCP-Via bei (44,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
    [spec_motor.py]
2026-09-09 Fix-Runde 2: Ostkorridor-Verbreiterung zurueckgenommen (gemessen schlechter)
    Der Versuch, die /+24V-Nordspur von x = 46,80 auf 46,30 zu ziehen, sollte
    den Korridor zur J105-Padreihe von 0,74 auf 1,24 mm verbreitern, damit
    /CPH UND /CPL dort nach Sueden passen (in r7 nachgemessen: der Router
    benutzt genau diese Spur, x = 47,17).
    Gemessen wurde das Gegenteil: offene Posten 4 (r6/r8) -> 9..11 (s1..s3),
    und /CPL blieb trotzdem offen. Auf 46,30 draengt die Spur zu dicht an die
    F.Cu-Trasse (45,53) und an das /VCP-Via und nimmt dem Router mehr, als
    der breitere Korridor einbringt.
    Zurueckgenommen, mit der Messung als Kommentar an der Stelle -- damit es
    niemand ein zweites Mal versucht. Die beiden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
    [spec_motor.py]
2026-09-09 Aufgabe 7b: Motormodul neu verlegt auf der vertragstreuen Platzierung (Fix-Runde 2)
    Wurf t7, bester aus 26 Wuerfen der Laeufe r, s und t.
    Found 2 unconnected items
    Die zwei Posten, vollstaendig:
    1. /CPL C10-2 <-> U1-14 -- die eine Netz-Luecke.
    2. eine GND-Insel in der Notaus-Ecke (F.Cu x 6,9..11,0 y 46,1..49,5,
    B.Cu x 7,7..10,6 y 45,2..51,5). Der masseheiler-Wachhund bleibt
    deshalb ROT; er heilte in diesem Lauf sieben Stuecke und meldet
    diese eine Gruppe als ohne freien Heilpunkt.
    steckerprobe.py: VOLLSTAENDIG GRUEN, alle elf Zeilen -- die sechs
    Vertragsstecker, Umriss, Bohrungen, Lo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
    [Motormodul.kicad_pcb]
2026-09-09 Fix-Runde 3: /CPL verdrahtet -- die /+24V-Trasse war die Wand; zwei Werkzeugfallen gefixt
    KORREKTUR EINER VORGABE (Ruling /CPL, Empfehlung A). "C10 drehen und
    ~1 mm suedlich, damit die 0,625-mm-Luecke auf 0,650 kommt" kann nicht
    gehen: die 0,625 mm sind der Abstand zwischen C10s EIGENEN ZWEI PADS und
    damit Footprint-Geometrie (0805-HandSolder, Padraster 2,075 minus
    Padhoehe 1,450). Drehen oder Verschieben nimmt beide Pads mit; die
    Luecke bleibt in jeder Lage 0,625 mm.
    Die eigentliche Ursache war meine EIGENE Bahn. Die /+24V-Trasse lief von
    U1-11 nach Osten bis x = 45,43 und dann nach Sueden -- als Wand zwischen
    den Pads 12/13/14 (noerdlich) und ihren Kondensatoren (suedlich). Jedes
    Cap-Netz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
    [build.py, spec_motor.py, stack_spec.py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]
2026-09-09 Fix-Runde 3: /+24V erreicht C9-1 von Westen um U1 herum
    In Lauf u blieb /+24V offen, nachdem die Ostgasse-Trasse entfallen war:
    C9-1 haette von der Versorgungszelle aus entweder durch die (jetzt den
    Cap-Netzen gehoerende) Ostgasse gemusst oder quer durch U1. Beides geht
    nicht, also war das Weglassen zu viel des Guten.
    Jetzt fuehrt der Anschluss ueber die Rueckseite um U1 HERUM und
    beruehrt die Ostgasse gar nicht: Via im eigenen Pad von C9-1, auf B.Cu
    nach Westen bei y = 28,60 (0,475 mm unter der /CPL-Rueckseitenbahn),
    bei x = 33,30 nach Norden -- westlich der Waermepfad-Regelflaeche (die
    beginnt erst bei 34,10) und 1,34 mm neben den Kontakten von
    stapel_links -- und oben auf y = 17,30 nach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
    [spec_motor.py]
2026-09-09 Fix-Runde 3: /CPH auf eine eigene Rueckseitenspur, Baender entzerrt
    Nach Lauf v (nur noch /CPH offen, sonst 2 Posten) bekommt auch das
    dritte Cap-Netz eine feste Fuehrung. Auf der Vorderseite war kein Platz
    mehr: zwischen den Spuren von /VCP (45,75) und /CPL (46,40) bleiben
    0,40 mm, und oestlich von /CPL kaeme /CPH nur hin, indem es dessen Spur
    kreuzt. Also frueher auf die Rueckseite -- Via schon bei (44,60|21,325),
    noerdlich der /+24V-Ausleitung, dann B.Cu nach Sueden auf x = 44,15
    (0,15 mm oestlich der Waermepfad-Flaeche, 0,85 mm von der
    /+24V-Rueckseitenbahn; noetig 0,825).
    Zwei Dinge, die das Gate gefunden hat und die ich vorher falsch hatte:
    * Die Baender von /CPH und /VCP kreuzten s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
    [spec_motor.py]
2026-09-09 Fix-Runde 3: drei Naehpunkte fuer die letzten Massestuecke
    Lauf w brachte den ersten Wurf, in dem ALLE Netze verlegt waren (w8:
    0 Verletzungen, 2 offene Posten -- beide reine GND-Inseln, keine einzige
    Netz-Luecke). Uebrig blieben vier Massestuecke ohne freien Heilpunkt:
    die Notaus-Ecke oben (F.Cu x 6,9..10,6 y 47,2..49,5) und unten (B.Cu
    x 7,4..11,9 y 47,0..57,7) sowie der Zwickel westlich von U100 (F.Cu
    x 12,6..16,5 y 18,1..23,1 und B.Cu x 10,4..17,1 y 18,8..20,0).
    Drei Punkte ergaenzt, an genau diesem Wurf gesucht und gegen das echte
    Kupfer gerechnet (>=0,50 mm zu Pads, >=0,90 zu Vias, >=0,63 zu Bahnen):
    (8,90|48,60), (7,30|54,00), (16,70|19,10). In der Notaus-Ecke sind es
    nur 38 zulaessi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
    [spec_motor.py]
2026-09-09 Aufgabe 7b: Motormodul verlegt -- alle Bauteilnetze geschlossen (Wurf x2)
    Bester aus 14 Wuerfen des Laufs x, ausgewaehlt nach dem, was funktional
    zaehlt: KEINE einzige Netz-Luecke mehr.
    Found 3 unconnected items
    Die drei Posten sind AUSSCHLIESSLICH Zone-gegen-Zone -- kein Pad, kein
    Netz. Jede Verbindung zwischen zwei Bauteilen ist verlegt; uebrig
    bleiben drei Fragmente des Masseflaechen-Gusses, die nicht an den
    Hauptguss angebunden sind (masseheiler-Wachhund nennt sie: F.Cu
    6,4..10,6 x 46,1..49,5 / 13,8..15,8 x 26,3..27,5 / 27,2..35,0 x
    16,6..21,0 und B.Cu 7,4..10,4 x 44,8..51,3 / 29,8..32,6 x 17,4..23,3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
    [Motormodul.kicad_pcb]
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

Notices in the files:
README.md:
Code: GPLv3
